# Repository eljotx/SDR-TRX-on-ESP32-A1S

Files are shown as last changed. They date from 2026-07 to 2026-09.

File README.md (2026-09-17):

# SDR-TRX-on-ESP32-A1S -> JACK
This repository describes an SDR transceiver based on the ESP32 A1S processor, using an ILI9341 color touchscreen display, and a Si5351 oscillator. The program was written on the Arduino platform and is still in development, but the most important features have already been implemented and tested.
The most important part of the software is Arduino Audio Tools, authored by Phil Schatzmann: https://github.com/pschatzmann/arduino-audio-tools

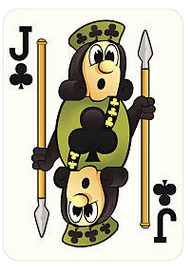
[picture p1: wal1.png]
JACK


# General Idea

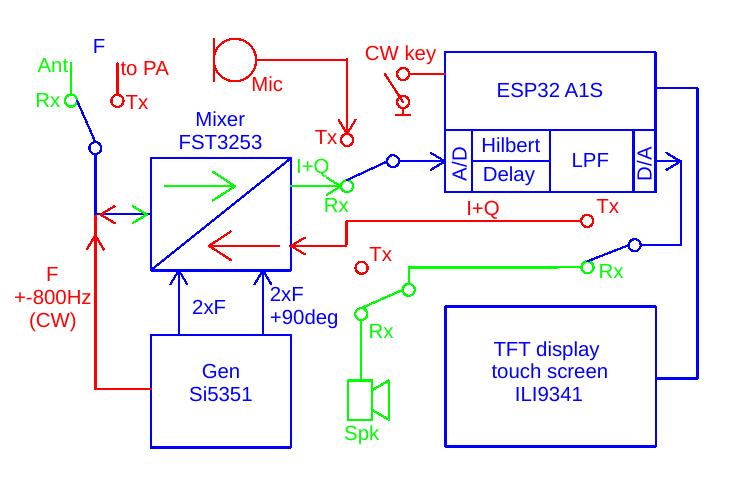
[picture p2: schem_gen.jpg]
Basic idea


The transceiver was built using a phase-based SSB signal generation method. Due to the breadth of the topic and the abundance of descriptions available online, this method will not be described here. However, I encourage you to study this topic theoretically, which will help you understand the presented solution.

Crucial to the solution is the use of **Tayloe mixer on FST3253, A/D conversion, Hilbert transforms, digital filters, and D/A conversion** in the audio paths of the receiver and transmitter.

## Local oscilator 

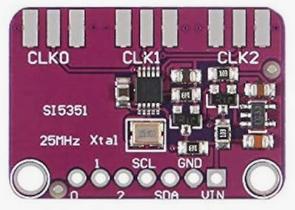
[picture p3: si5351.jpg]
Generator Si5351


The Si5351 acts as a local oscillator, clocking the transmitter and receiver mixers at a frequency that ensures proper detection or modulation. In this case, the clock signals have a frequency twice that of the useful signal, with an additional 90-degree shift between them, achieved using an additional shaping circuit based on integrated circuits 7474 and 7486. It is possible to generate the mixer signals directly within the Si5351, but for operation above 3.5 MHz, the controller needs to be modified, but the biggest inconvenience is the need to reset the PLL synchronization loop. This synchronization generates delays that are perceived as strong clicks during receive mode.

## Tayloe Mixer

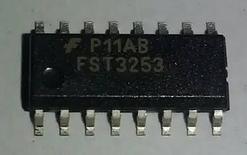
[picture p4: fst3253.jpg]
Mixer FST3253


The FST3253 is a dual, quadruple, high-speed digital keyer that acts as a keyed mixer for both the transmitter and receiver. During reception, the mixer extracts the I and Q components from the received signal for further digital processing. During transmission, it modulates the RF signal with I and Q components, creating a lower or upper sideband signal.

## Processor ESP32 A1S

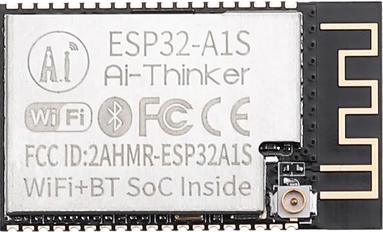
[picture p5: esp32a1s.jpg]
Procesor ESP32A1S


The core of the system is the ESP32 A1S processor, which is suitable for implementing the project because it contains built-in internal A/D and D/A converters and operates at a speed that allows for sufficiently fast sampling and the use of digital filters of desired complexity. Although the A/D and D/A converters have a resolution of 16 bits, this seems sufficient for a design that doesn't aspire to perfection, but rather addresses basic digital processing issues. Additionally, the processor has two cores, allowing for the separation of tasks that don't require immediate processing from those related to audio streaming. An additional advantage of the processor is the ability to use two I2c channels for communication with peripherals and a channel SPI for communication with the display. All of these features are discussed in more detail in the following descriptions.

# How receiver works
The antenna signal reaches a Tayloe mixer, where I and Q signals are generated. Both signals contain sideband information, which is used for digital data processing. To achieve this, the analog I and Q signals are digitized using 16-bit A/D converters. A Hilbert transform is then applied to one of the channels (shifting the signal's phase by 90 degrees). The signals are then digitally filtered using a BiQuad digital filter. Three filters are available: two low-pass filters at 3.6 kHz and 2.4 kHz, and a bandpass filter at 800 Hz for CW reception. Finally, the I and Q signals are converted back to analog using 16-bit D/A converters and summed, reducing the sideband of the received signal. The received sideband is selected in the Tayloe mixer by changing the phase of the heterodyne signals, reducing the load on the digital software.

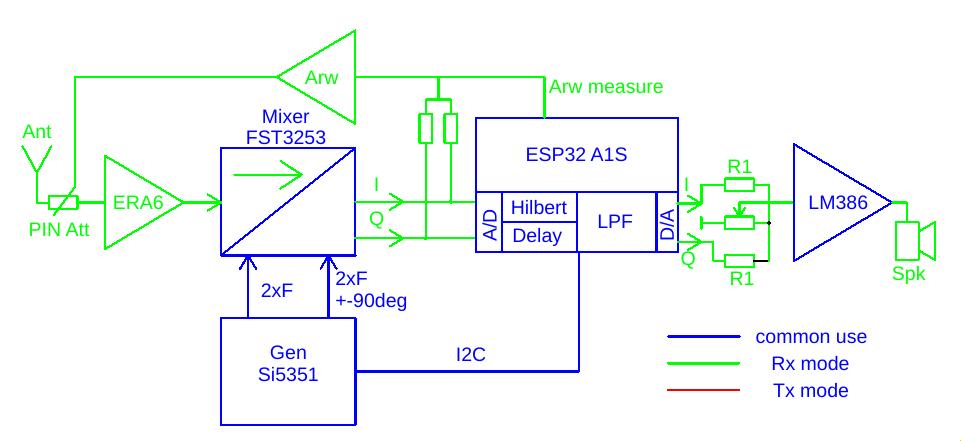
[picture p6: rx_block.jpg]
Receiver


The figure shows the signal waveform during reception in more detail. The antenna signal passes through an adjustable PIN diode attenuator and an ERA6 amplifier, and is then detected in the Taylor mixer. The I and Q signals extracted from the mixer, after summing, detection, and amplification, are used to adjust the gain using the PIN attenuator, and also, through AGC signal measurement, visualize the received signal strength. Simultaneously, the extracted I and Q signals undergo digital processing, as described earlier, and after conversion to analog and amplification, they can be received via headphones or a loudspeaker.

# How transceiver works

## SSB mode
In SSB mode, the transmitter initially digitizes the microphone signal using A/D converters. Subsequently, a Hilbert transform is performed on one of the signals, followed by a common LPF digital filtering with a 2.4 kHz bandwidth. This creates two digital I and Q signals, which are then converted to analog using D/A converters. The SSB signal is formed in a Tayloe mixer using two heterodyne signals that are 90 degrees out of phase. Similar to receiving, the sideband is selected by determining which heterodyne signal has a +90 degree offset relative to the other. This signal is then amplified and fed to the antenna. 

## CW mode
In CW mode, the Tayloe mixer is disabled (heterodyne stop), and an additional keyed heterodyne is activated at the device's operating frequency, with a sideband offset of approximately +800 Hz, depending on the sideband used.

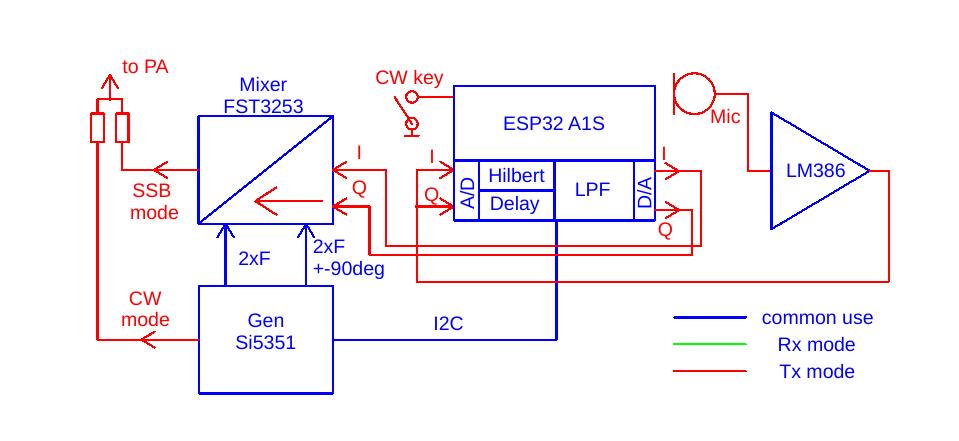
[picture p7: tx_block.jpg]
Transceiver


In addition to the previously described CW and SSB signal generation process, the figure shows how common circuit elements are used. Specifically, the microphone signal is pre-amplified in the same amplifier used for reception, and after shaping the I and Q channels, it feeds the Tayloe mixer. The final output signal is generated at the Tayloe mixer output in SSB mode or directly from the Si5351 generator in CW mode.

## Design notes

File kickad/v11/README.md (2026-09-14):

Kickad files was created with KicCad version 8.09-1

Software version 1_1 require using resistance divider (values) as showed on picture.

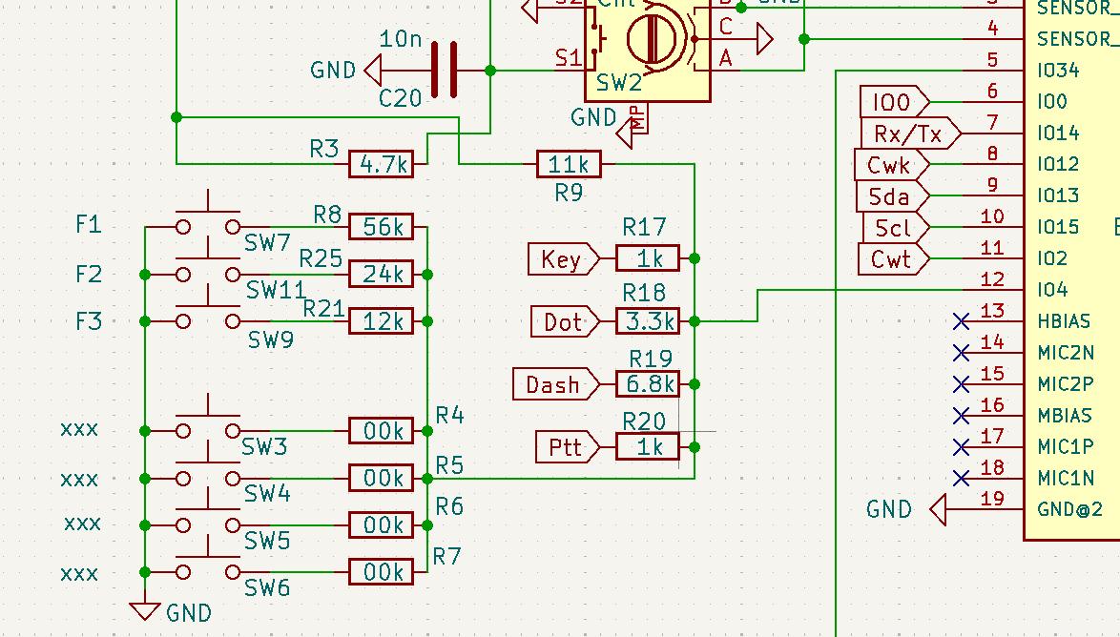
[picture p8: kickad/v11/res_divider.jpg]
divider


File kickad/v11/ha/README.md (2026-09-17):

The system can be operated in a basic configuration without the AGC system and redundant components. The drawing shows which components do not need to be installed in such a case.
The red markings refer to the PIN diode attenuator. The purple markings refer to the input amplifier, which results in reduced receiver sensitivity. In both cases, the jumpers marked in blue must be installed.

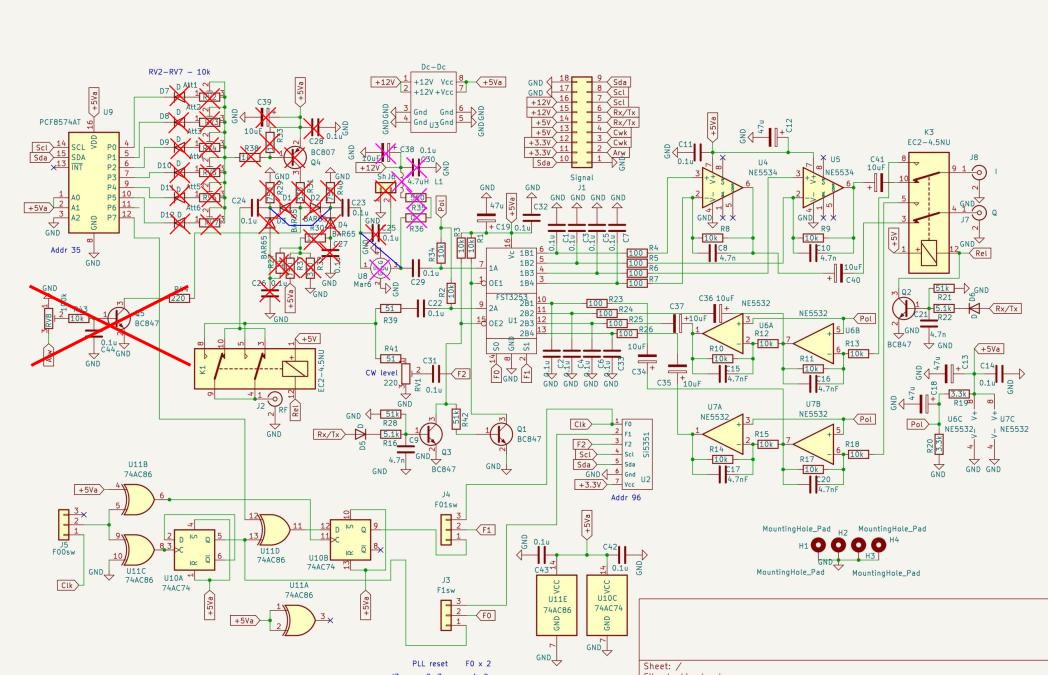
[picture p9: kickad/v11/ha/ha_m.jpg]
reduction


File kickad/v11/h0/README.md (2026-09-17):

Practical tip for mounting anti noise capacitor C31.
The LM386 amplifier may sometimes oscillate at frequencies ranging from several tens of kilohertz to nearly 200 kHz (this is visible on the output when an oscilloscope is connected and is indicated by an operating current exceeding 100 mA). To prevent this, capacitor C31 should be soldered close to the LM386 chip; a good solution is to solder C31 directly onto resistor R10.

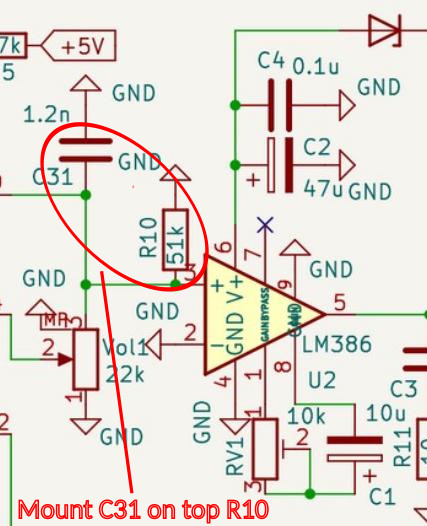
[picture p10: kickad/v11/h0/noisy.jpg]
divider


The system can be operated in a basic configuration without the AGC system and redundant components. The drawing shows which components do not need to be installed in such a case.

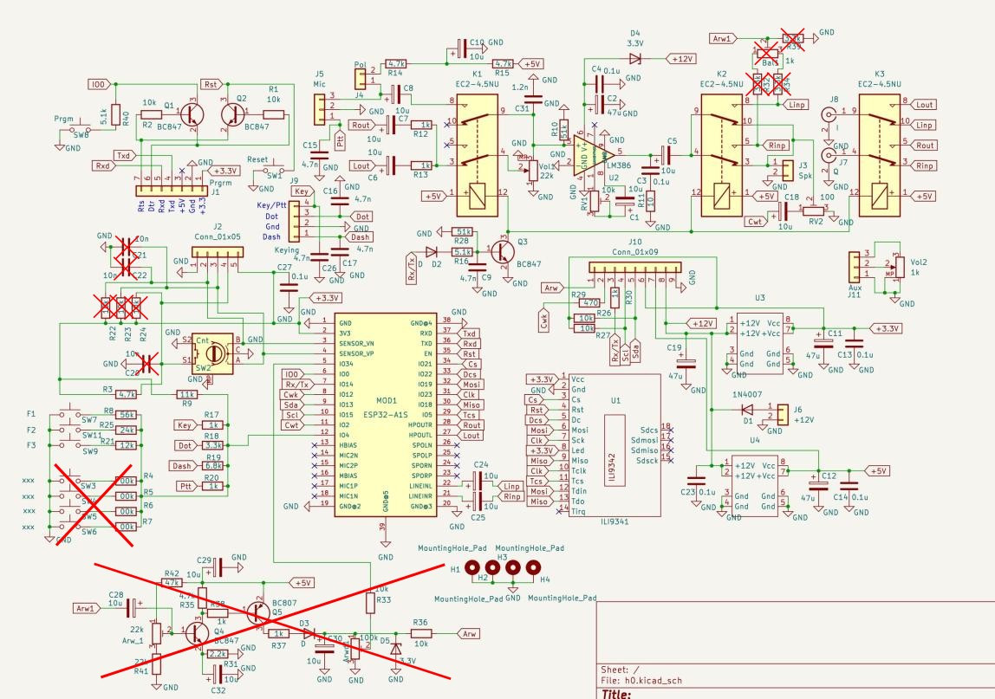
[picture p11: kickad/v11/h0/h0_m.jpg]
reduction


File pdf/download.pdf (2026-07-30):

Jak zaprogramować procesor Waleta z pomocą przeglądarki Chrome

Do wgrywania plików binarnych do procesorów ESP firma Expressive przygotowała dla systemu Windows narzędzia dostępne pod adresami: https://docs.espressif.com/projects/esp-test-tools/en/latest/esp32/production_stage/tools/flash_download_tool.html (https://docs.espressif.com/projects/esp-test-tools/en/latest/esp32/production_stage/tools/flash_download_tool.html) lub https://docs.espressif.com/projects/esp-at/en/latest/esp32/Get_Started/
Stamtąd też można ściągnąć pakiet oprogramowania jako plik .zip https://dl.espressif.com/public/flash_download_tool.zip , w którym znajduje się plik
wykonywalny .exe działający jako okno IDE pozwalający na wgranie plików binarnych do procesora.
Niezależnie od tego, niemal identyczną role pełni dostępna w sieci aplikacja zbliżona w wyglądzie do narzędzia instalowanego na platformie Windows z tym, że działa ona wyłącznie w przeglądarce Chrome.
1. Przeglądarka Chrome ma komponenty pozwalające na bezpośrednie programowanie układu ESP32 A1S bez konieczności instalacji Arduino, bibliotek i innych zależności.
Odpowiednie narzędzie znajduje się na stronie : https://espressif.github.io/esptool-js/
2. Aby wykorzystać to narzędzie należy przede wszystkim zapewnić kontakt elektryczny procesora na płytce z komputerem PC za pomocą opisanego wcześniej (np. w wykazie elementów płytki h0) konwertera USB/RS232 z pełną sygnalizacją (RTS oraz DTR).

Fotografia pokazuje gdzie na płytce znajdują się obwody odpowiedzialne za komunikacją oraz konwerter z pełną sygnalizacją RS. Do programowania procesora nie jest potrzebne zewnętrzne zasilanie bo wystarcza to z portu USB PC.

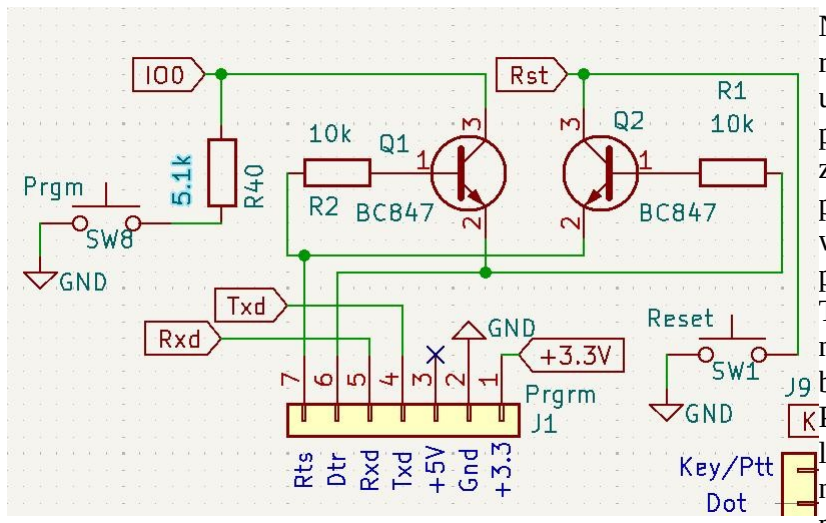
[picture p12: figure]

Niestety, okazało się, że obecne rozwiązanie elektryczne nie uwzględniało tej formy ładowania programu i musiałem
zmodyfikować tą część układu przez dołożenie przycisku
wprowadzania procesora w tryb programowania (SW8 oraz R40). Te elementy pojawią się w
następnej wersji płytek o ile będzie taka potrzeba.
Platforma Arduino radzi sobie lepiej z ładowaniem programu i nie wymaga ręcznego przełączenia procesora w tryb programowania dlatego to rozwiązanie pojawia się tak późno i obecne płytki nie zawierają dodatkowych

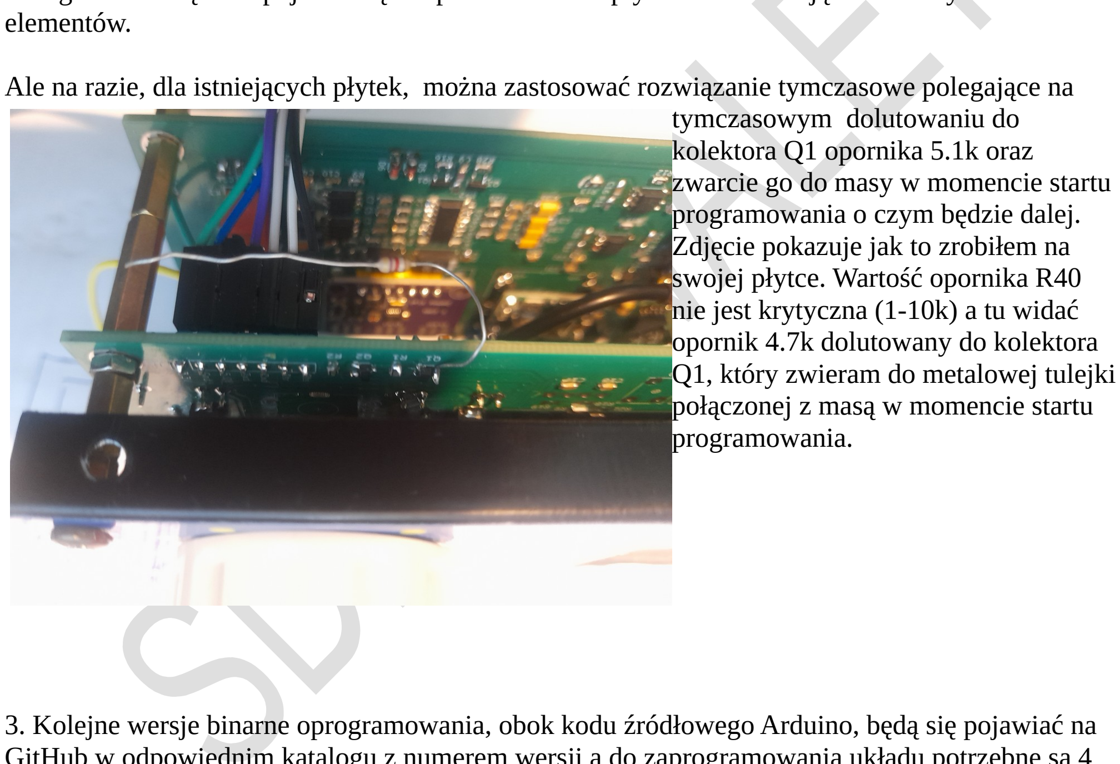
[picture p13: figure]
elementów.; tymczasowym dolutowaniu do kolektora Q1 opornika 5.1k oraz zwarcie go do masy w momencie startu programowania o czym będzie dalej. Zdjęcie pokazuje jak to zrobiłem na swojej płytce. Wartość opornika R40 nie jest krytyczna (1-10k) a tu widać opornik 4.7k dolutowany do kolektora Q1, który zwieram do metalowej tulejki połączonej z masą w momencie startu programowania.

Ale na razie, dla istniejących płytek, można zastosować rozwiązanie tymczasowe polegające na

3. Kolejne wersje binarne oprogramowania, obok kodu źródłowego Arduino, będą się pojawiać na GitHub w odpowiednim katalogu z numerem wersji a do zaprogramowania układu potrzebne są 4 pliki binarne i na przykład obecnie mają one nazwę:
boot_app0.bin
ssd_trx01.ino.bin
ssd_trx01.ini.bootloader.bin
ssd_trx01.ino.partitions.bin
Dodatkowo, podświetliłem plik flash_args, który jest bardzo pomocny podczas definiowania treści wgranej do procesora. Kolejne wersje oprogramowania zawierać będą zestaw pokazanych pięciu plików ale być może będą się różnić rdzeniem nazwy, który tu ma postać ssd_trx01

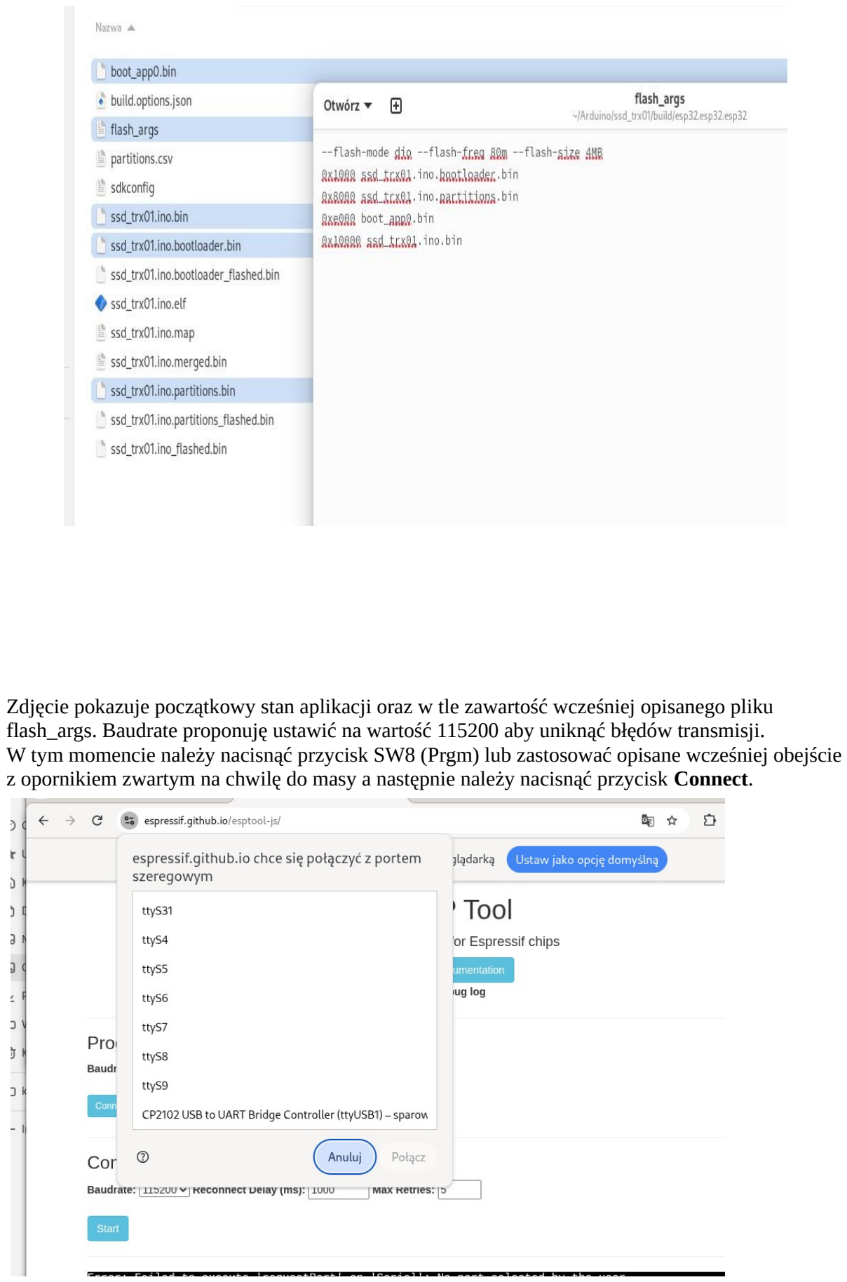
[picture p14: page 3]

Zdjęcie pokazuje początkowy stan aplikacji oraz w tle zawartość wcześniej opisanego pliku flash_args. Baudrate proponuję ustawić na wartość 115200 aby uniknąć błędów transmisji.
W tym momencie należy nacisnąć przycisk SW8 (Prgm) lub zastosować opisane wcześniej obejście z opornikiem zwartym na chwilę do masy a następnie należy nacisnąć przycisk Connect.

Pojawi się okno z możliwością wyboru portu, w moim przypadku to ostatni na dole port ttyUSB1 identyfikowany dodatkowo przez symbol chip-u CP2102. Po wyborze (kliknięciu) na właściwy port aktywny stanie się klawisz Połącz (Connect) i powinien pojawić się komunikat w oknie konsoli na dole aplikacji o skutecznym połączeniu.

Od tego momentu można zwolnić przycisk programowania i przejść do wyboru plików oraz uruchomienia procedury download.

5. Właściwe programowanie wymaga podania dla każdego z czterech plików wymienionych w p.3 zarówno nazwy jak i adresu gdzie powinien ten plik się zaczynać. Robi się to zamieszczając w polu adresowym (z lewej) odpowiednią wartość skojarzoną ze ścieżką do pliku i tu jest pomocny widoczny w tle plik flash_args zawierając właśnie potrzebne dane. Kolejne pliki dodaje się klawiszem Add File.

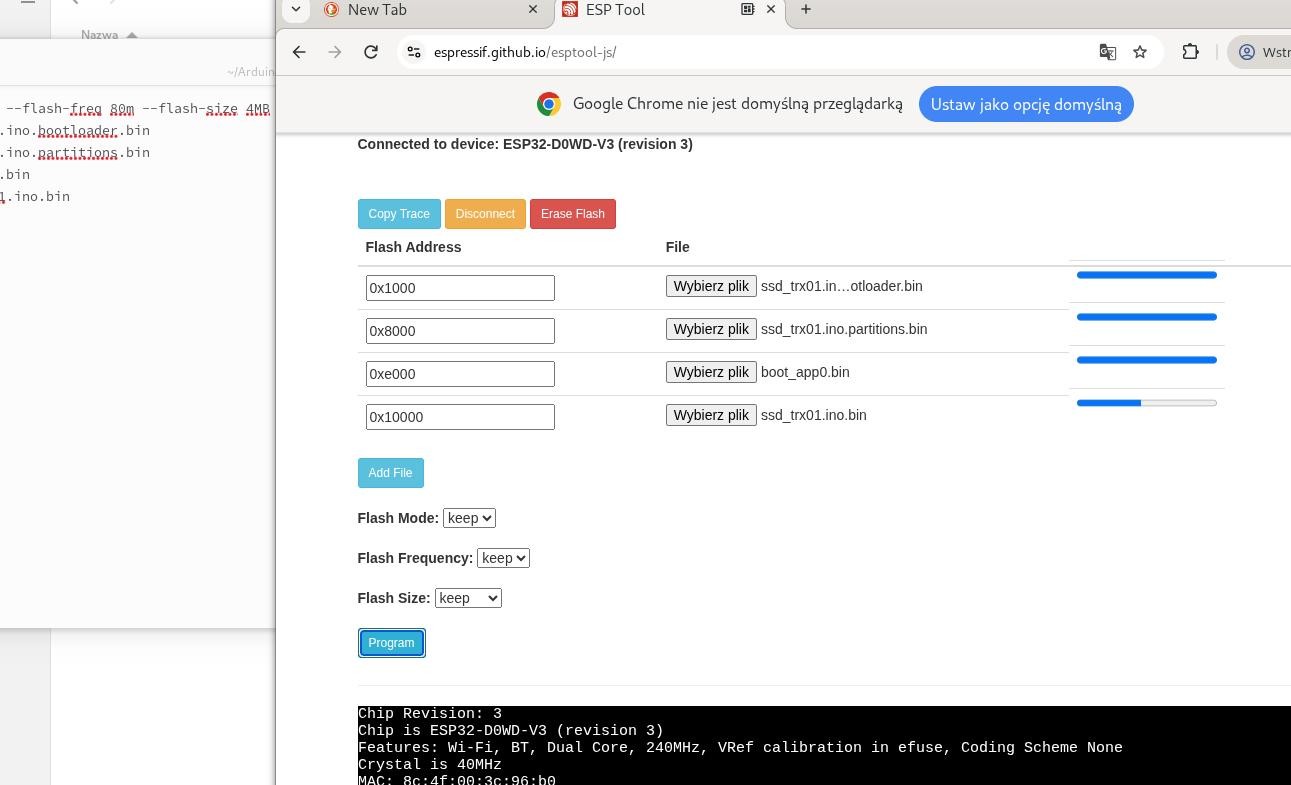
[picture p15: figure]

Zdjęcie pokazuje stan aplikacji po wybraniu czterech niezbędnych plików z odpowiednimi adresami po uruchomieniu programowania za pomocą klawisza Program. Przesłanie plików zajmuje nie więcej niż kilkanaście sekund a po zakończeniu należy układ zresetować klawiszem RST lub poprzez zasilanie i procesor powinien już działać pod kontrolą nowego oprogramowania.

Przy sprawnym połączeniu płytki procesora z komputerem PC wgranie oprogramowania zajmuje kilka minut.

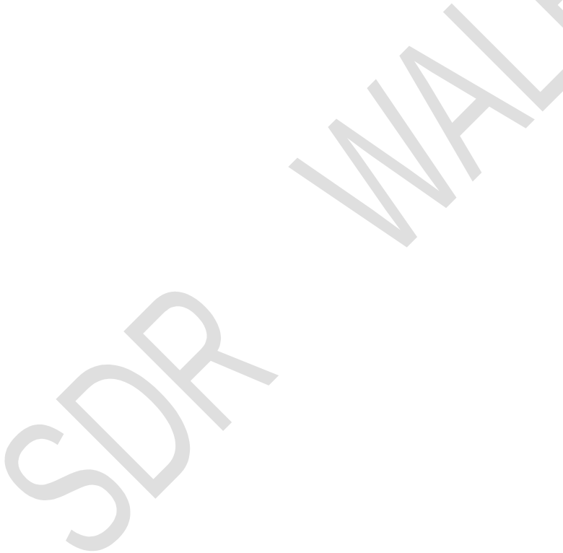
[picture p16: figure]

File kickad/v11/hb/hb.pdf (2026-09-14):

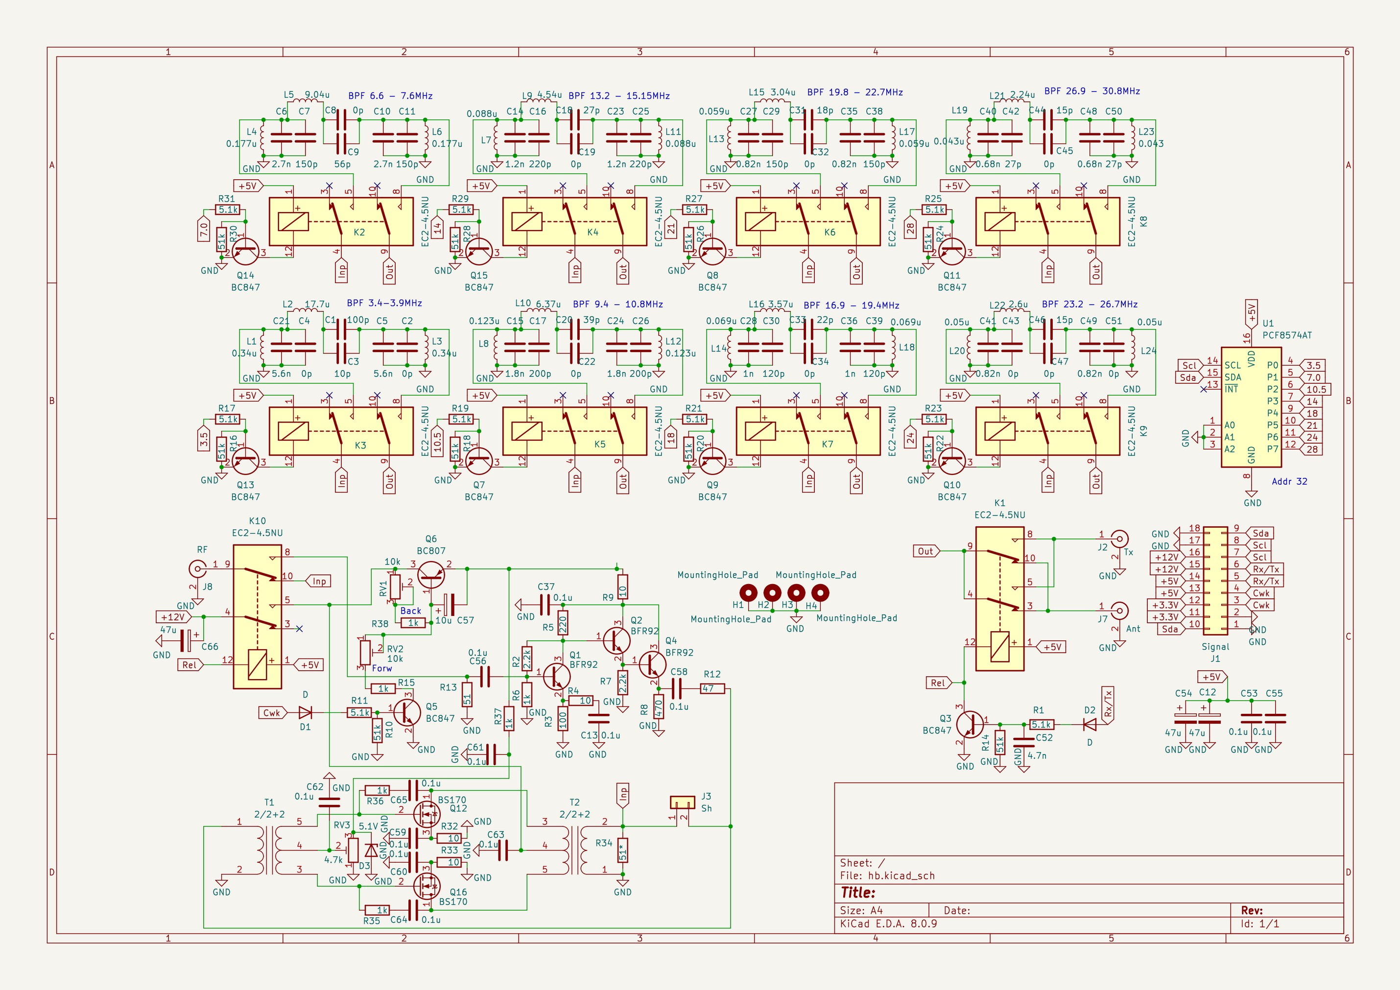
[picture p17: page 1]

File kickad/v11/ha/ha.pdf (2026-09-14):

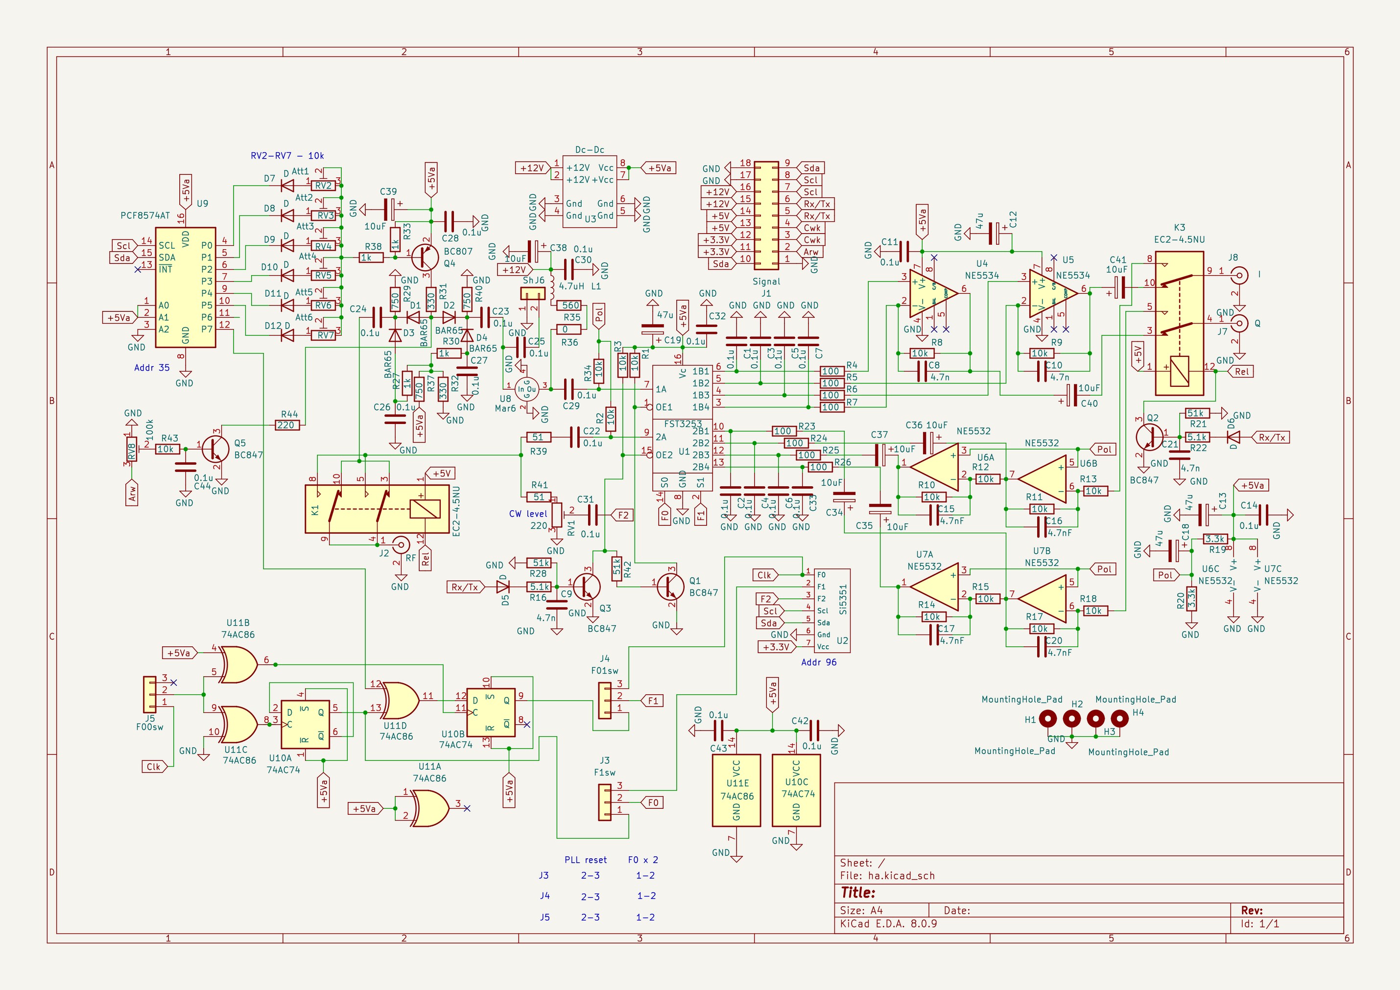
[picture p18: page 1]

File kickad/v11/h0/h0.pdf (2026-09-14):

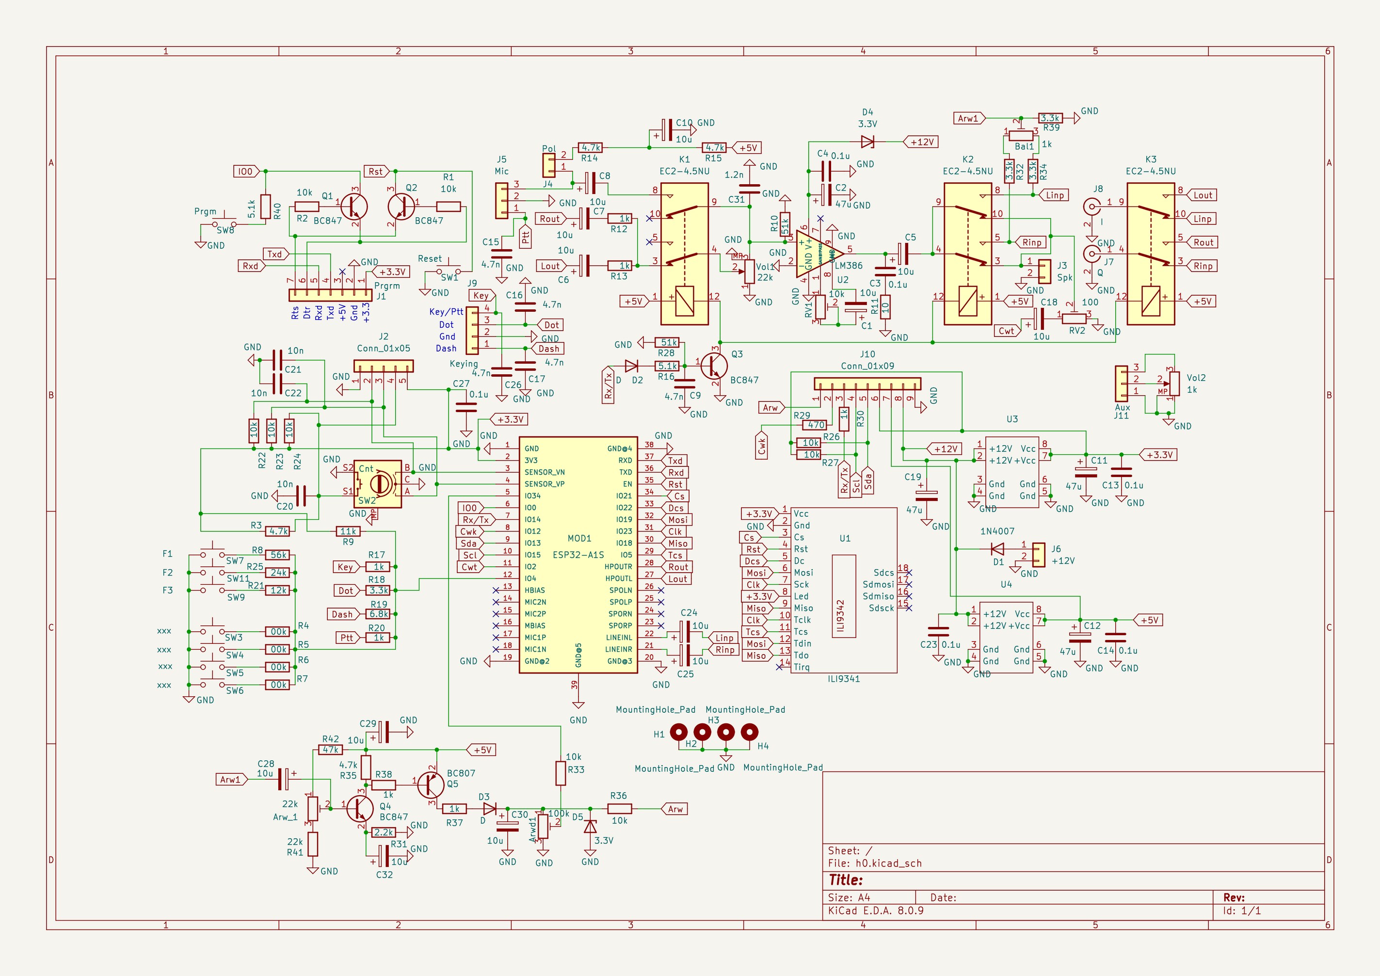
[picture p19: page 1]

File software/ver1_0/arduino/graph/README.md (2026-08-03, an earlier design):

All files here must be in graph subdirectory of main arduino file directory

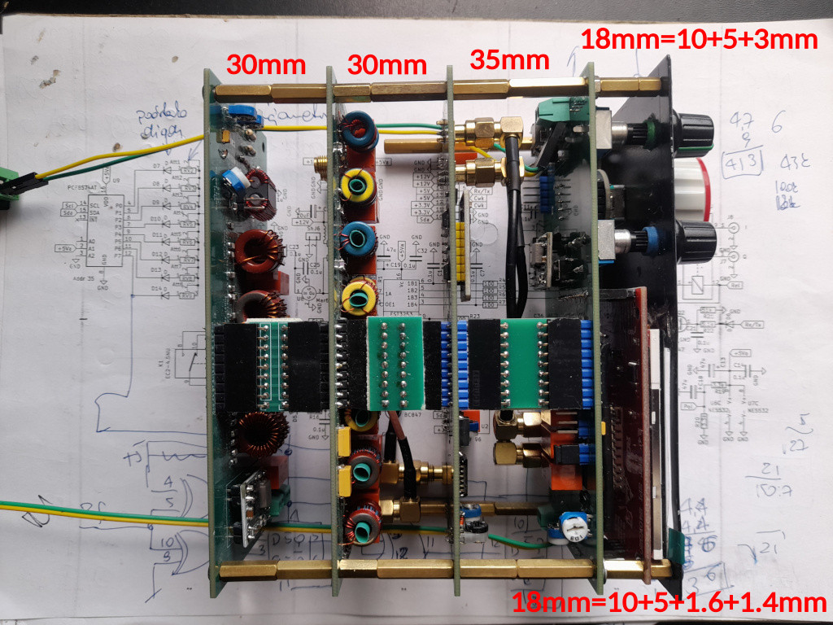
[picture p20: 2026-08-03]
images/mont01.jpg

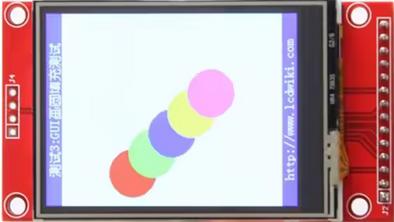
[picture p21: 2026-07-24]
ili9341a.jpg

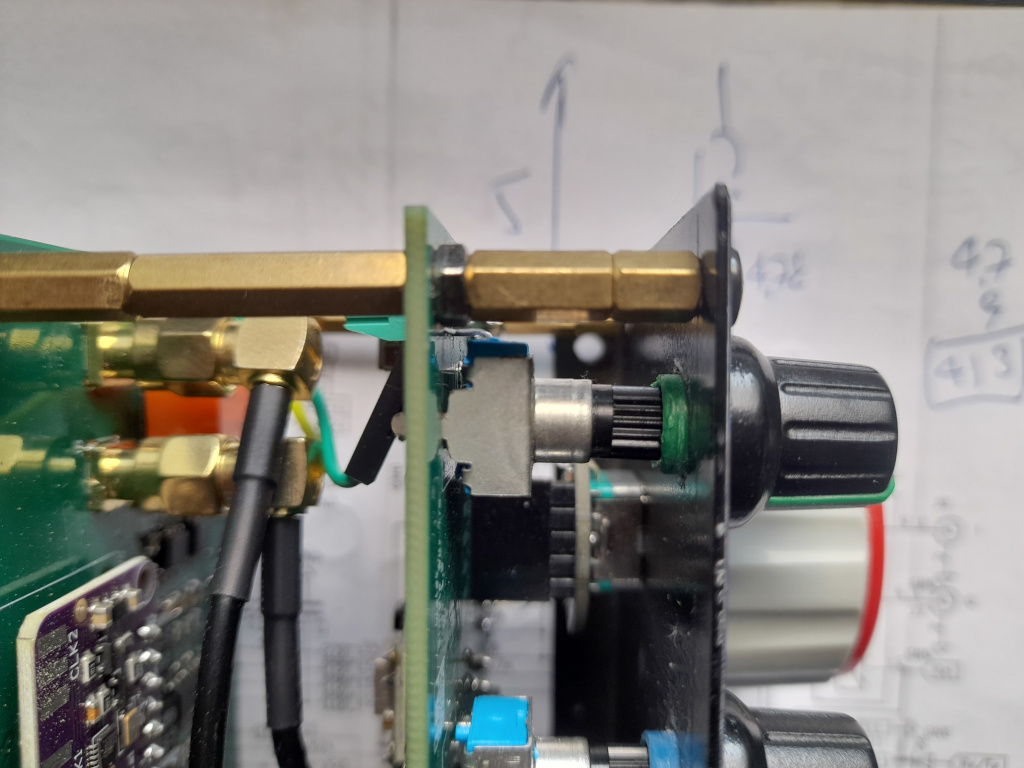
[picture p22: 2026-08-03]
images/mont03.jpg

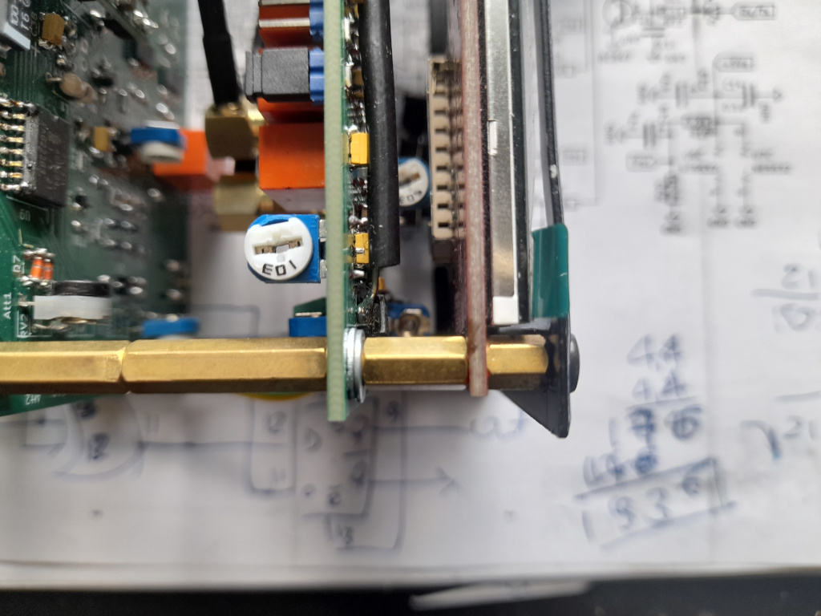
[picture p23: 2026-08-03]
images/mont02.jpg

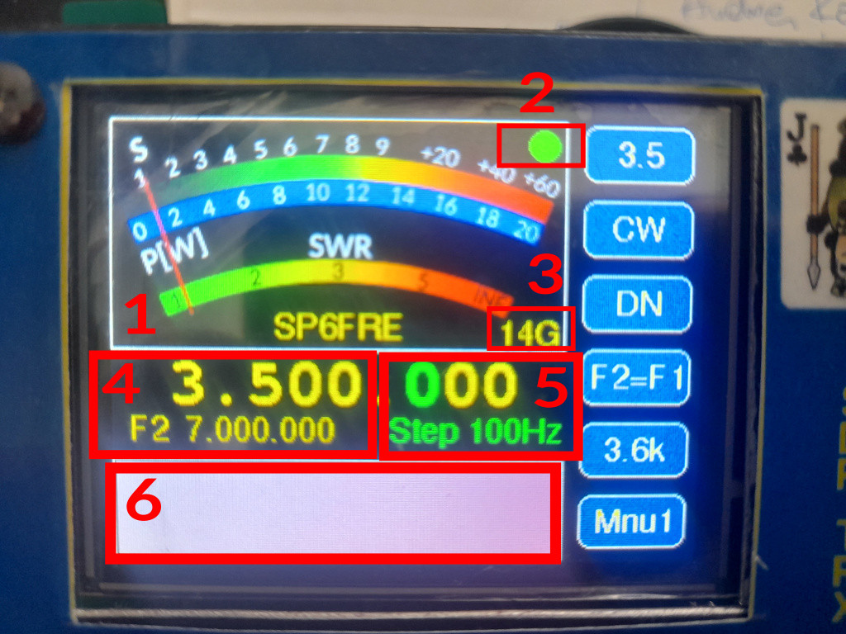
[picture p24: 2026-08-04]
images/screen.jpg

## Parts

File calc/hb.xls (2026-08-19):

Reference | Value | Uwagi | Footprint | Qty | DNP | Cena | Wartość | Gdzie kupić
C1 | 10p |  | Capacitor_SMD:C_0805_2012Metric | 1 |  | 0.15 | 0.15 | TME, allegro
C2,C4,C9,C18,C20,C31,C33,C43,C44,C46,C51 | 0p |  | Capacitor_SMD:C_0805_2012Metric | 11 |  | 0.15 | 1.65 | TME, allegro
C3,C49 | 100p |  | Capacitor_SMD:C_0805_2012Metric | 2 |  | 0.15 | 0.30 | TME, allegro
C5,C21 | 5.6n |  | Capacitor_SMD:C_0805_2012Metric | 2 |  | 0.15 | 0.30 | TME, allegro
C6,C10 | 2.7n |  | Capacitor_SMD:C_0805_2012Metric | 2 |  | 0.15 | 0.30 | TME, allegro
C7,C11,C29,C38 | 150p |  | Capacitor_SMD:C_0805_2012Metric | 4 |  | 0.15 | 0.60 | TME, allegro
C8 | 56p |  | Capacitor_SMD:C_0805_2012Metric | 1 |  | 0.15 | 0.15 | TME, allegro
C12,C54,C66 | 47u | 47-100u | Capacitor_Tantalum_SMD:CP_EIA-7343-31_Kemet-D | 3 |  | 2.928 | 8.78 | TME
C13,C37,C53,C55,C56,C58,C59,C60,C61,C62,C63,C64,C65 | 0.1u |  | Capacitor_SMD:C_0805_2012Metric | 13 |  | 0.15 | 1.95 | TME, allegro
C14,C23 | 1.2n |  | Capacitor_SMD:C_0805_2012Metric | 2 |  | 0.15 | 0.30 | TME, allegro
C15,C24 | 1.8n |  | Capacitor_SMD:C_0805_2012Metric | 2 |  | 0.15 | 0.30 | TME, allegro
C16,C25 | 220p |  | Capacitor_SMD:C_0805_2012Metric | 2 |  | 0.15 | 0.30 | TME, allegro
C17,C26 | 200p |  | Capacitor_SMD:C_0805_2012Metric | 2 |  | 0.15 | 0.30 | TME, allegro
C19,C42,C50 | 27p |  | Capacitor_SMD:C_0805_2012Metric | 3 |  | 0.15 | 0.45 | TME, allegro
C22 | 39p |  | Capacitor_SMD:C_0805_2012Metric | 1 |  | 0.15 | 0.15 | TME, allegro
C27,C35,C41 | 0.82n |  | Capacitor_SMD:C_0805_2012Metric | 3 |  | 0.15 | 0.45 | TME, allegro
C28,C36 | 1n |  | Capacitor_SMD:C_0805_2012Metric | 2 |  | 0.15 | 0.30 | TME, allegro
C30,C39 | 120p |  | Capacitor_SMD:C_0805_2012Metric | 2 |  | 0.15 | 0.30 | TME, allegro
C32 | 18p |  | Capacitor_SMD:C_0805_2012Metric | 1 |  | 0.15 | 0.15 | TME, allegro
C34 | 22p |  | Capacitor_SMD:C_0805_2012Metric | 1 |  | 0.15 | 0.15 | TME, allegro
C40,C48 | 0.68n |  | Capacitor_SMD:C_0805_2012Metric | 2 |  | 0.15 | 0.30 | TME, allegro
C45,C47 | 15p |  | Capacitor_SMD:C_0805_2012Metric | 2 |  | 0.15 | 0.30 | TME, allegro
C52 | 4.7n |  | Capacitor_SMD:C_0805_2012Metric | 1 |  | 0.15 | 0.15 | TME, allegro
C57 | 10u |  | Capacitor_SMD:C_0805_2012Metric | 1 |  | 0.15 | 0.15 | TME, allegro
D1,D2 | D | Schottky | Capacitor_SMD:C_1206_3216Metric | 2 |  | 0.3 | 0.60 | TME, allegro
D3 | 5.1V |  | Capacitor_SMD:C_1206_3216Metric | 1 |  | 0.3 | 0.30 | TME, allegro
J1 | Signal |  | Connector_PinHeader_2.54mm:PinHeader_2x09_P2.54mm_Vertical | 1 |  | 3.105 | 3.11 | TME, allegro
J2 | Tx |  | Connector_Coaxial:SMA_Amphenol_901-144_Vertical | 1 |  | 2.5 | 2.50 | aliexpress
J3 | Sh |  | Connector_PinHeader_2.54mm:PinHeader_1x02_P2.54mm_Vertical | 1 |  | 0.345 | 0.35 | TME, allegro
J7 | Ant |  | Connector_Coaxial:SMA_Amphenol_901-144_Vertical | 1 |  | 2.5 | 2.50 | aliexpress
J8 | RF |  | Connector_Coaxial:SMA_Amphenol_901-144_Vertical | 1 |  | 2.5 | 2.50 | aliexpress
K1,K2,K3,K4,K5,K6,K7,K8,K9,K10 | EC2-4.5NU |  | Relay_THT:Relay_DPDT_Kemet_EC2_NJ | 10 |  | 2.952 | 29.52 | https://shop.tvsat.com.pl/pl/p/10szt-EC2-4.5N-Relay-4.5VDC-2A-Coil-178-Ohm-THT-NEC/8891
L1,L3 | 0.34u | T37-12 lub 17 | tr_rf:l_01 | 2 |  | 3.2 | 6.40 | allegro, hps://sklep.sp2fp.profimot.pl/rdzenie-c-1.html,
L2 | 17.7u | T37-1 | tr_rf:l_01 | 1 |  | 2.5 | 2.50 | allegro, https://sklep.sp2fp.profimot.pl/rdzenie-c-1.html
L4,L6 | 0.177u | T37-12 lub 17 | tr_rf:l_01 | 2 |  | 3.2 | 6.40 | allegro, https://sklep.sp2fp.profimot.pl/rdzenie-c-1.html
L5 | 9.04u | T37-1 | tr_rf:l_01 | 1 |  | 2.5 | 2.50 | allegro, https://sklep.sp2fp.profimot.pl/rdzenie-c-1.html
L7,L11 | 0.088u | T37-0 | tr_rf:l_01 | 2 |  | 4.5 | 9.00 | allegro, https://sklep.sp2fp.profimot.pl/rdzenie-c-1.html
L8,L12 | 0.123u | T37-12 lub 17 | tr_rf:l_01 | 2 |  | 3.2 | 6.40 | allegro, https://sklep.sp2fp.profimot.pl/rdzenie-c-1.html
L9 | 4.54u | T37-2 | tr_rf:l_01 | 1 |  | 2.5 | 2.50 | allegro, https://sklep.sp2fp.profimot.pl/rdzenie-c-1.html
L10 | 6.37u | T37-2 | tr_rf:l_01 | 1 |  | 2.5 | 2.50 | allegro, https://sklep.sp2fp.profimot.pl/rdzenie-c-1.html
L13,L17 | 0.059u | T37-0 | tr_rf:l_01 | 2 |  | 4.5 | 9.00 | allegro, https://sklep.sp2fp.profimot.pl/rdzenie-c-1.html
L14,L18 | 0.069u | T37-0 | tr_rf:l_01 | 2 |  | 4.5 | 9.00 | allegro, https://sklep.sp2fp.profimot.pl/rdzenie-c-1.html
L15 | 3.04u | T37-2 | tr_rf:l_01 | 1 |  | 2.5 | 2.50 | allegro, https://sklep.sp2fp.profimot.pl/rdzenie-c-1.html
L16 | 3.57u | T37-2 | tr_rf:l_01 | 1 |  | 2.5 | 2.50 | allegro, https://sklep.sp2fp.profimot.pl/rdzenie-c-1.html
L19 | 0.043u | T37-0 | tr_rf:l_01 | 1 |  | 4.5 | 4.50 | allegro, https://sklep.sp2fp.profimot.pl/rdzenie-c-1.html
L20,L24 | 0.05u | T37-0 | tr_rf:l_01 | 2 |  | 4.5 | 9.00 | allegro, https://sklep.sp2fp.profimot.pl/rdzenie-c-1.html
L21 | 2.24u | T37-2 | tr_rf:l_01 | 1 |  | 2.5 | 2.50 | allegro, https://sklep.sp2fp.profimot.pl/rdzenie-c-1.html
L22 | 2.6u | T32-2 | tr_rf:l_01 | 1 |  | 2.5 | 2.50 | allegro, https://sklep.sp2fp.profimot.pl/rdzenie-c-1.html
L23 | 0.043 | T37-0 | tr_rf:l_01 | 1 |  | 4.5 | 4.50 | allegro, https://sklep.sp2fp.profimot.pl/rdzenie-c-1.html
Q1,Q2,Q4 | BFR92 |  | Package_TO_SOT_SMD:SOT-23 | 3 |  | 1.31241 | 3.94 | TME, allegro
Q3,Q5,Q7,Q8,Q9,Q10,Q11,Q13,Q14,Q15 | BC847 |  | Package_TO_SOT_SMD:SOT-23 | 10 |  | 0.8784 | 8.78 | TME, allegro
Q6 | BC807 |  | Package_TO_SOT_SMD:SOT-23 | 1 |  | 0.8784 | 0.88 | TME, allegro
Q12,Q16 | BS170 |  | Package_TO_SOT_THT:TO-92_Inline | 2 |  | 1.968 | 3.94 | TME, allegro
R1,R11,R17,R19,R21,R23,R25,R27,R29,R31 | 5.1k |  | Resistor_SMD:R_0805_2012Metric | 10 |  | 0.03 | 0.30 | TME, allegro
R2,R7 | 2.2k |  | Resistor_SMD:R_0805_2012Metric | 2 |  | 0.03 | 0.06 | TME, allegro
R3 | 100 |  | Resistor_SMD:R_0805_2012Metric | 1 |  | 0.03 | 0.03 | TME, allegro
R4,R9,R32,R33 | 10 |  | Resistor_SMD:R_0805_2012Metric | 4 |  | 0.03 | 0.12 | TME, allegro
R5 | 220 |  | Resistor_SMD:R_0805_2012Metric | 1 |  | 0.03 | 0.03 | TME, allegro
R6,R15,R35,R36,R37,R38 | 1k |  | Resistor_SMD:R_0805_2012Metric | 6 |  | 0.03 | 0.18 | TME, allegro
R8 | 470 |  | Resistor_SMD:R_0805_2012Metric | 1 |  | 0.03 | 0.03 | TME, allegro
R10,R14,R16,R18,R20,R22,R24,R26,R28,R30 | 51k |  | Resistor_SMD:R_0805_2012Metric | 10 |  | 0.03 | 0.30 | TME, allegro
R12 | 47 |  | Resistor_SMD:R_0805_2012Metric | 1 |  | 0.03 | 0.03 | TME, allegro
R13 | 51 |  | Resistor_SMD:R_0805_2012Metric | 1 |  | 0.03 | 0.03 | TME, allegro
R34 | 51* |  | Resistor_SMD:R_0805_2012Metric | 1 |  | 0.03 | 0.03 | TME, allegro
RV1,RV2 | 10k |  | Potentiometer_THT:Potentiometer_ACP_CA6-H2,5_Horizontal | 2 |  | 0.5 | 1.00 | TME, allegro
RV3 | 4.7k |  | Potentiometer_THT:Potentiometer_ACP_CA6-H2,5_Horizontal | 1 |  | 0.5 | 0.50 | TME, allegro
T1,T2 | 2/2+2 | dwuotworowy niski | tr_rf:tr_05_v | 2 |  | 2.5 | 5.00 | allegro, https://sklep.sp2fp.profimot.pl/rdzenie-c-1.html
U1 | PCF8574AT |  | Package_SO:SOIC-16W_7.5x10.3mm_P1.27mm | 1 |  | 7.3 | 7.30 | TME
 | Przewód SMA kątowy | >10szt |  | 3 |  | 7.4 | 22.20 | aliexpress
 | Płytka dr. |  |  | 1 |  | 13.627 | 13.63 | JLCPCB
 |  |  |  |  |  | suma | 212.11

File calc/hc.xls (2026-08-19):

Reference | Value | Uwagi | Footprint | Qty | DNP | Cena | Wartość | Gdzie kupić
C1,C27,C28,C29,C31 | 0.1u |  | Capacitor_SMD:C_0805_2012Metric | 5 |  | 0.15 | 0.75 | TME, allegro
C2 | 470p |  | Capacitor_SMD:C_1206_3216Metric | 1 |  | 0.15 | 0.15 | TME, allegro
C3,C4 | 750p |  | Capacitor_SMD:C_1206_3216Metric | 2 |  | 0.15 | 0.30 | TME, allegro
C5,C9,C12 | 47p |  | Capacitor_SMD:C_1206_3216Metric | 3 |  | 0.15 | 0.45 | TME, allegro
C6,C10 | 390p |  | Capacitor_SMD:C_1206_3216Metric | 2 |  | 0.15 | 0.30 | TME, allegro
C7,C11,C15,C17,C19,C21,C23,C25 | 0p |  | Capacitor_SMD:C_1206_3216Metric | 8 |  | 0.15 | 1.20 | TME, allegro
C8 | 680p |  | Capacitor_SMD:C_1206_3216Metric | 1 |  | 0.15 | 0.15 | TME, allegro
C13 | 1n |  | Capacitor_SMD:C_1206_3216Metric | 1 |  | 0.15 | 0.15 | TME, allegro
C14,C18 | 200p |  | Capacitor_SMD:C_1206_3216Metric | 2 |  | 0.15 | 0.30 | TME, allegro
C16 | 360p |  | Capacitor_SMD:C_1206_3216Metric | 1 |  | 0.15 | 0.15 | TME, allegro
C20,C24 | 100p |  | Capacitor_SMD:C_1206_3216Metric | 2 |  | 0.15 | 0.30 | TME, allegro
C22 | 180p |  | Capacitor_SMD:C_1206_3216Metric | 1 |  | 0.15 | 0.15 | TME, allegro
C26,C32 | 47u | 47-100u | Capacitor_Tantalum_SMD:CP_EIA-3528-21_Kemet-B | 2 |  | 2.928 | 5.86 | TME, allegro
C30 | 4.7n |  | Capacitor_SMD:C_0805_2012Metric | 1 |  | 0.15 | 0.15 | TME, allegro
D1,D2,D3 | D | Schottky | Diode_SMD:D_1206_3216Metric | 3 |  | 0.3 | 0.90 | TME, allegro
D4 | 1N4007 |  | Diode_SMD:D_1206_3216Metric | 1 |  | 0.3 | 0.30 | TME, allegro
J1 | +12V | 3mm | Connector:power_con | 1 |  | 0.5 | 0.50 | TME, allegro
J2 | Sign |  | Connector_PinHeader_2.54mm:PinHeader_2x09_P2.54mm_Vertical | 1 |  | 1.5525 | 1.55 | TME, allegro
J5 | Ant |  | Connector_Coaxial:SMA_Amphenol_901-144_Vertical | 1 |  | 2.5 | 2.50 | aliexpress
J7 | Sh |  | Connector_PinHeader_2.54mm:PinHeader_1x02_P2.54mm_Vertical | 1 |  | 0.345 | 0.35 | TME, allegro
J10 | RF |  | Connector_Coaxial:SMA_Amphenol_901-144_Vertical | 1 |  | 2.5 | 2.50 | aliexpress
J11 | Pa |  | Connector_Coaxial:SMA_Amphenol_901-144_Vertical | 1 |  | 2.5 | 2.50 | aliexpress
J12 | +12Tx | 3mm | Connector:power_con | 1 |  | 0.5 | 0.50 | TME, allegro
K1,K2,K3,K4,K6,K7 | EC2-4.5NU |  | Relay_THT:Relay_DPDT_Kemet_EC2_NU | 6 |  | 2.952 | 17.71 | https://shop.tvsat.com.pl/pl/p/10szt-EC2-4.5N-Relay-4.5VDC-2A-Coil-178-Ohm-THT-NEC/8891
L1,L2 | 2.73u | T50-2 | tr_rf:l_01 | 2 |  | 4.3 | 8.60 | allegro, https://sklep.sp2fp.profimot.pl/rdzenie-c-1.html
L3,L4 | 1.37u | T50-2 | tr_rf:l_01 | 2 |  | 4.3 | 8.60 | allegro, https://sklep.sp2fp.profimot.pl/rdzenie-c-1.html
L5,L6 | 0.683u | T50-12,17 lub 6 | tr_rf:l_01 | 2 |  | 4.3 | 8.60 | allegro, https://sklep.sp2fp.profimot.pl/rdzenie-c-1.html
L7,L8 | 0.341u | T50-12,17 lub 6 | tr_rf:l_01 | 2 |  | 4.3 | 8.60 | allegro, https://sklep.sp2fp.profimot.pl/rdzenie-c-1.html
Q1,Q2,Q3,Q4,Q5 | BC847 |  | Package_TO_SOT_SMD:SOT-23 | 5 |  | 0.8784 | 4.39 | TME, allegro
R2,R5,R7,R9,R17 | 5.1k |  | Resistor_SMD:R_0805_2012Metric | 5 |  | 0.03 | 0.15
R3 | 1.2k |  | Resistor_SMD:R_0805_2012Metric | 1 |  | 0.03 | 0.03
R4,R6,R8,R10,R16 | 51k |  | Resistor_SMD:R_0805_2012Metric | 5 |  | 0.03 | 0.15
R18,R19 | 51 |  | Resistor_THT:R_Axial_DIN0309_L9.0mm_D3.2mm_P12.70mm_Horizontal | 2 |  | 0.2 | 0.40
RV1,RV2,RV3 | 10k |  | Potentiometer_THT:Potentiometer_ACP_CA6-H2,5_Horizontal | 3 |  | 0.5 | 1.50
TR2 | DC | dwuotworowy | dircoupler:dircoupler | 1 |  | 5 | 5.00
U2 | MCP3424 |  | Package_SO:SOIC-14_3.9x8.7mm_P1.27mm | 1 |  | 14.36 | 14.36 | TME, allegro
U3 | Dc-Dc |  | Dc-dc:dc-dc | 1 |  | 4.99 | 4.99 | allegro
U4 | PCF8574AT |  | Package_SO:SOIC-16W_7.5x10.3mm_P1.27mm | 1 |  | 7.3 | 7.30 | TME, allegro
 | Przewód SMA kątowy | >10szt |  | 2 |  | 7.4 | 14.80 | aliexpress
 | Płytka dr. |  |  | 1 |  | 13.627 | 13.63 | JLCPCB
 |  |  |  |  |  | suma | 140.7645

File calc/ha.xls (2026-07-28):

Reference | Value | Uwagi | Footprint | Qty | DNP | Cena | Wartość | Gdzie kupić
C1,C2,C3,C4,C5,C6,C7,C11,C14,C22,C23,C24,C25,C26,C27,C28,C29,C30,C31,C32,C33,C42,C43,C44 | 0.1u |  | Capacitor_SMD:C_0805_2012Metric | 24 |  | 0.15 | 3.60 | TME, allegro
C8,C9,C10,C21 | 4.7n |  | Capacitor_SMD:C_0805_2012Metric | 4 |  | 0.15 | 0.60 | TME, allegro
C12,C13,C18,C19 | 47u | 47-100u | Capacitor_Tantalum_SMD:CP_EIA-7343-31_Kemet-D | 4 |  | 2.928 | 11.71 | TME
C15,C16,C17,C20 | 4.7nF |  | Capacitor_SMD:C_0805_2012Metric | 4 |  | 0.15 | 0.60 | TME, allegro
C34,C35,C36,C37,C38,C39,C40,C41 | 10uF |  | Capacitor_SMD:C_1206_3216Metric | 8 |  | 0.15 | 1.20 | TME, allegro
D1,D2,D3,D4 | BAR65 |  | Capacitor_SMD:C_0805_2012Metric | 4 |  | 0.15 | 0.60 | https://shop.tvsat.com.pl/pl/p/200szt-BAR65-03W-E6722-Diode-PIN-3GHz-SMD-SOD123-SIEMENS/19748
D5,D6,D7,D8,D9,D10,D11,D12 | D |  | Capacitor_SMD:C_1206_3216Metric | 8 |  | 0.15 | 1.20 | TME, allegro
J1 | Signal |  | Connector_PinHeader_2.54mm:PinHeader_2x09_P2.54mm_Vertical | 1 |  | 3.105 | 3.11 | TME, allegro
J2 | RF |  | Connector_Coaxial:SMA_Amphenol_901-144_Vertical | 1 |  | 2.5 | 2.50 | aliexpress
J6 | Sh |  | Connector_PinHeader_2.54mm:PinHeader_1x02_P2.54mm_Vertical | 1 |  | 0.345 | 0.35 | TME, allegro
J7 | Q |  | Connector_Coaxial:SMA_Amphenol_901-144_Vertical | 1 |  | 2.5 | 2.50 | aliexpress
J8 | I |  | Connector_Coaxial:SMA_Amphenol_901-144_Vertical | 1 |  | 2.5 | 2.50 | aliexpress
K1,K3 | EC2-4.5NU |  | Relay_THT:Relay_DPDT_Kemet_EC2_NJ | 2 |  | 2.952 | 5.90 | https://shop.tvsat.com.pl/pl/p/10szt-EC2-4.5N-Relay-4.5VDC-2A-Coil-178-Ohm-THT-NEC/8891
L1 | 4.7uH |  | Inductor_THT:L_Axial_L5.3mm_D2.2mm_P7.62mm_Horizontal_Vishay_IM-1 | 1 |  | 0.3 | 0.30
Q1,Q2,Q3,Q5 | BC847 |  | Package_TO_SOT_SMD:SOT-23 | 4 |  | 0.8784 | 3.51 | TME, allegro
Q4 | BC807 |  | Package_TO_SOT_SMD:SOT-23 | 1 |  | 0.8784 | 0.88 | TME, allegro
R1,R2,R3,R8,R9,R10,R11,R12,R13,R14,R15,R17,R18,R34,R43 | 10k |  | Resistor_SMD:R_0805_2012Metric | 15 |  | 0.03 | 0.45 | TME, allegro
R4,R5,R6,R7,R23,R24,R25,R26 | 100 |  | Resistor_SMD:R_0805_2012Metric | 8 |  | 0.03 | 0.24 | TME, allegro
R16,R22 | 5.1k |  | Resistor_SMD:R_0805_2012Metric | 2 |  | 0.03 | 0.06 | TME, allegro
R19,R20 | 3.3k |  | Resistor_SMD:R_0805_2012Metric | 2 |  | 0.03 | 0.06 | TME, allegro
R21,R28,R42 | 51k |  | Resistor_SMD:R_0805_2012Metric | 3 |  | 0.03 | 0.09 | TME, allegro
R27,R30,R33,R38 | 1k |  | Resistor_SMD:R_0805_2012Metric | 4 |  | 0.03 | 0.12 | TME, allegro
R29,R37,R40 | 750 |  | Resistor_SMD:R_0805_2012Metric | 3 |  | 0.03 | 0.09 | TME, allegro
R31,R32 | 330 |  | Resistor_SMD:R_0805_2012Metric | 2 |  | 0.03 | 0.06 | TME, allegro
R35 | 560 |  | Resistor_SMD:R_0805_2012Metric | 1 |  | 0.03 | 0.03 | TME, allegro
R36 | 0 |  | Resistor_SMD:R_0805_2012Metric | 1 |  | 0.03 | 0.03 | TME, allegro
R39,R41 | 51 |  | Resistor_SMD:R_0805_2012Metric | 2 |  | 0.03 | 0.06 | TME, allegro
R44,RV1 | 220 |  | Resistor_SMD:R_0805_2012Metric | 2 |  | 0.03 | 0.06 | TME, allegro
RV2 | Att1 |  | Potentiometer_THT:Potentiometer_ACP_CA6-H2,5_Horizontal | 1 |  | 0.5 | 0.50 | TME, allegro
RV3 | Att2 |  | Potentiometer_THT:Potentiometer_ACP_CA6-H2,5_Horizontal | 1 |  | 0.5 | 0.50 | TME, allegro
RV4 | Att3 |  | Potentiometer_THT:Potentiometer_ACP_CA6-H2,5_Horizontal | 1 |  | 0.5 | 0.50 | TME, allegro
RV5 | Att4 |  | Potentiometer_THT:Potentiometer_ACP_CA6-H2,5_Horizontal | 1 |  | 0.5 | 0.50 | TME, allegro
RV6 | Att5 |  | Potentiometer_THT:Potentiometer_ACP_CA6-H2,5_Horizontal | 1 |  | 0.5 | 0.50 | TME, allegro
RV7 | Att6 |  | Potentiometer_THT:Potentiometer_ACP_CA6-H2,5_Horizontal | 1 |  | 0.5 | 0.50 | TME, allegro
RV8 | 100k |  | Potentiometer_THT:Potentiometer_ACP_CA6-H2,5_Horizontal | 1 |  | 0.5 | 0.50 | TME, allegro
U1 | FST3253 |  | Package_SO:SOIC-16W_5.3x10.2mm_P1.27mm | 1 |  | 15 | 15.00 | allegro
U2 | Si5351 |  | Si5351:Si5351 | 1 |  | 21.5 | 21.50 | allegro
U3 | Dc-Dc |  | Dc-dc:dc-dc | 1 |  | 4.99 | 4.99 | allegro
U4,U5 | NE5534 |  | Package_SO:SO-8_3.9x4.9mm_P1.27mm | 2 |  | 5.2 | 10.40 | TME, allegro
U6,U7 | NE5532 |  | Package_SO:SO-8_3.9x4.9mm_P1.27mm | 2 |  | 5.2 | 10.40 | TME, allegro
U8 | Mar6 |  | era_mar:Era | 1 |  | 11.468 | 11.47 | https://www.digikey.pl/pl/products/detail/mini-circuits/MAR-6SM/13928288
U9 | PCF8574AT |  | Package_SO:SOIC-16W_7.5x10.3mm_P1.27mm | 1 |  | 7.3 | 7.30 | TME
U10 | 74AC74 |  | Package_SO:SO-14_5.3x10.2mm_P1.27mm | 1 |  | 4.3 | 4.30 | TME
U11 | 74AC86 |  | Package_SO:SO-14_5.3x10.2mm_P1.27mm | 1 |  | 3.2 | 3.20 | TME
 | Płytka dr. |  |  | 1 |  | 13.627 | 13.63 | JLCPCB
 | Przewód SMA kątowy | >10szt |  | 2 |  | 7.4 | 14.80 | aliexpress
 |  |  |  |  |  | Suma | 162.893

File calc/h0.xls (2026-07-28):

Reference | Value | Uwagi | Footprint | Qty | DNP | Cena | Wartość | Gdzie kupić
Arwd1,Arw_1 | 100k |  | Potentiometer_THT:Potentiometer_ACP_CA6-H2,5_Horizontal | 2 |  | 0.5 | 1.00 | TME, allegro
Bal1,R1,R2,R9,R10,R22,R23,R24,R26,R27,R33,R36,RV1 | 10k |  | Resistor_SMD:R_0805_2012Metric | 13 |  | 0.03 | 0.39 | TME,allegro
C1,C5,C6,C7,C8,C10,C18,C24,C25,C28,C29,C30 | 10u | Tantal | SMD:C_1206_3216Metric | 12 |  | 1.098 | 1.10 | TME
C2,C11,C12,C19 | 47u lub 100u | Tantal | Capacitor_Tantalum_SMD:CP_EIA-7343-31_Kemet-D | 4 |  | 2.928 | 11.71 | TME
C3,C4,C13,C14,C23,C27 | 0.1u |  | Capacitor_SMD:C_0805_2012Metric | 6 |  | 0.15 | 0.90 | TME, allegro
C9,C15,C16,C17,C26 | 4.7n |  | Capacitor_SMD:C_0805_2012Metric | 5 |  | 0.15 | 0.75 | TME, allegro
C20,C21,C22 | 10n |  | Capacitor_SMD:C_0805_2012Metric | 3 |  | 0.15 | 0.45 | TME, allegro
D1 | 1N4007 |  | Diode_SMD:D_2114_3652Metric | 1 |  | 0.3 | 0.30 | TME, allegro
D2,D3 | D | np.. BAT48 SMD | SMD:C_1206_3216Metric | 2 |  | 0.29 | 0.58 | https://botland.com.pl/diody-schottky/14581-dioda-schottky-bat48-smd-1a-40v-10szt-5903351244503.html
D4,D5 | 3.3V |  | SMD:C_1206_3216Metric | 2 |  | 0.5 | 1.00 | TME, allegro
J1 | Prgrm |  | Connector_PinHeader_2.54mm:PinHeader_1x07_P2.54mm_Vertical | 1 |  | 1.2075 | 1.21 | TME, allegro
J2 | Conn_01x05 |  | Connector_PinHeader_2.54mm:PinHeader_1x05_P2.54mm_Vertical | 1 |  | 0.8625 | 0.86 | TME, allegro
J3 | Spk | Raster pinów 3.5mm | Connector:power_con | 1 |  | 1.5 | 1.50 | TME, allegro
J4 | Pol |  | Connector_PinHeader_2.54mm:PinHeader_1x02_P2.54mm_Vertical | 1 |  | 0.345 | 0.35 | TME, allegro
J5 | Mic |  | Connector_PinHeader_2.54mm:PinHeader_1x03_P2.54mm_Vertical | 1 |  | 0.5175 | 0.52 | TME, allegro
J6 | +12V | Raster pinów 3.5mm | Connector:power_con | 1 |  | 1.5 | 1.50 | TME, allegro
J7 | Q | >=10 szt | Connector_Coaxial:SMA_Amphenol_901-144_Vertical | 1 |  | 2.5 | 2.50 | aliexpress
J8 | I | >=10 szt | Connector_Coaxial:SMA_Amphenol_901-144_Vertical | 1 |  | 2.5 | 2.50 | aliexpress
J9 | Keying |  | Connector_PinHeader_2.54mm:PinHeader_1x04_P2.54mm_Vertical | 1 |  | 0.69 | 0.69 | TME, allegro
J10 | Conn_01x09 |  | Connector_PinHeader_2.54mm:PinHeader_1x09_P2.54mm_Vertical | 1 |  | 1.5525 | 1.55 | TME, allegro
J11 | Aux |  | Connector_PinHeader_2.54mm:PinHeader_1x03_P2.54mm_Vertical | 1 |  | 0.5175 | 0.52 | TME, allegro
K1,K2,K3 | EC2-4.5NU |  | Relay_THT:Relay_DPDT_Kemet_EC2_NJ | 3 |  | 2.952 | 8.86 | https://shop.tvsat.com.pl/pl/p/10szt-EC2-4.5N-Relay-4.5VDC-2A-Coil-178-Ohm-THT-NEC/8891
MOD1 | ESP32-A1S |  | esp32a1s:ESP32-A1S | 1 |  | 30.9 | 30.90 | aliexpress
Q1,Q2,Q3,Q4 | BC847 |  | Package_TO_SOT_SMD:SOT-23 | 4 |  | 0.8784 | 3.51 | TME, allegro
Q5 | BC807 |  | Package_TO_SOT_SMD:SOT-23 | 1 |  | 0.8784 | 0.88 | TME,allegro
R3,R14,R15,R17,R20,R35 | 4.7k |  | Resistor_SMD:R_0805_2012Metric | 6 |  | 0.03 | 0.18 | TME, allegro
R4 | 15k |  | Resistor_SMD:R_0805_2012Metric | 1 |  | 0.03 | 0.03 | TME, allegro
R5 | 7.5k |  | Resistor_SMD:R_0805_2012Metric | 1 |  | 0.03 | 0.03 | TME, allegro
R6 | 3.6k |  | Resistor_SMD:R_0805_2012Metric | 1 |  | 0.03 | 0.03 | TME, allegro
R7 | 1.6k |  | Resistor_SMD:R_0805_2012Metric | 1 |  | 0.03 | 0.03 | TME, allegro
R8,R29,R31 | 470 |  | Resistor_SMD:R_0805_2012Metric | 3 |  | 0.03 | 0.09 | TME, allegro
R11 | 10 |  | Resistor_SMD:R_0805_2012Metric | 1 |  | 0.03 | 0.03 | TME, allegro
R12,R13,R30,R37,R38,Vol2 | 1k |  | Resistor_SMD:R_0805_2012Metric | 6 |  | 0.03 | 0.18 | TME, allegro
R16 | 5.1k |  | Resistor_SMD:R_0805_2012Metric | 1 |  | 0.03 | 0.03 | TME, allegro
R18 | 12k |  | Resistor_SMD:R_0805_2012Metric | 1 |  | 0.03 | 0.03 | TME, allegro
R19 | 24k |  | Resistor_SMD:R_0805_2012Metric | 1 |  | 0.03 | 0.03 | TME, allegro
R21 | 1.2k |  | Resistor_SMD:R_0805_2012Metric | 1 |  | 0.03 | 0.03 | TME, allegro
R25 | 56k |  | Resistor_SMD:R_0805_2012Metric | 1 |  | 0.03 | 0.03 | TME, allegro
R28 | 51k |  | Resistor_SMD:R_0805_2012Metric | 1 |  | 0.03 | 0.03 | TME, allegro
R32,R34,R39 | 3.3k |  | Resistor_SMD:R_0805_2012Metric | 3 |  | 0.03 | 0.09 | TME, allegro
RV2 | 100 | >=10 szt | Potentiometer_THT:Potentiometer_ACP_CA6-H2,5_Horizontal | 1 |  | 0.36 | 0.36 | TME, allegro
SW1 | Reset |  | Connector:microswitch | 1 |  | 0.5 | 0.50 | TME, allegro
SW2 | Cnt |  | Rotary_Encoder:RotaryEncoder_Alps_EC11E-Switch_Vertical_H20mm | 1 |  | 6.9 | 6.90 | allegro, aliexpress
SW3 | Step |  | Connector:microswitch | 1 |  | 0.5 | 0.50 | TME, allegro
SW4 | Up/Dn |  | Connector:microswitch | 1 |  | 0.5 | 0.50 | TME, allegro
SW5 | Rit |  | Connector:microswitch | 1 |  | 0.5 | 0.50 | TME, allegro
SW6 | Save |  | Connector:microswitch | 1 |  | 0.5 | 0.50 | TME, allegro
SW7 | Rest |  | Connector:microswitch | 1 |  | 0.5 | 0.50 | TME, allegro
SW9 | Mnu |  | Connector:microswitch | 1 |  | 0.5 | 0.50 | TME, allegro
SW11 | F1/F2 |  | Connector:microswitch | 1 |  | 0.5 | 0.50 | TME, allegro
U1 | ILI9341 | 2.4” | Ili9341:ili9342 | 1 |  | 41.1 | 41.10 | allegro
U2 | LM386 |  | Package_SO:Diodes_PSOP-8 | 1 |  | 4.6 | 4.60 | TME
U3,U4 | ~ |  | Dc-dc:dc-dc | 2 |  | 4.99 | 9.98 | allegro
Vol? | 22k |  | Potentiometer_THT:Potentiometer_Alpha_RD901F-40-00D_Single_Vertical | 1 |  | 4.5 | 4.50 | TME, allegro
 | Płytka dr. |  |  | 1 |  | 13.627 | 13.63
 | Przewód SMA kątowy | 10szt |  | 2 |  | 7.4 | 14.80
 | Programator |  | Konwerter USB CP2102 RS232 TTL UART 3.3/5V programator do odczytu TX/RX | 1 |  | 9.4 | 9.40 | allegro, Microbot
 | Inne |  |  | 1 |  | 10 | 10.00 | allegro, Microbot
 |  |  |  |  |  | Razem ok: | 196.16

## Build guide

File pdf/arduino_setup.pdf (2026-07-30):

Ustawienie i konfiguracja bibliotek niezbędnych do programowania Waleta

### 1. Instalacja platformy Arduino

Software dla różnych systemów operacyjnych można znaleźć pod tym linkiem: https://support.arduino.cc/hc/en-us/articles/360019833020-Download-and-install-Arduino-IDE

Kolejno należy wgrać do Arduino biblioteki procesorów ESP:
Installing ESP32 Add-on in Arduino IDE
1. In your Arduino IDE, go to File> Preferences.
2. Open the Boards Manager. Go to Tools > Board > Boards Manager…
3. Search for ESP32 and press install button for the “ESP32 by Espressif Systems“:
4. That's it. It should be installed after a few seconds.
Pomocny film: https://randomnerdtutorials.com/installing-the-esp32-board-in-arduino-idewindows-instructions/ (https://randomnerdtutorials.com/installing-the-esp32-board-in-arduino-ide-windows-instructions/)
Po dołączeniu konwertera USB/RS do procesora należy wybrać odpowiedni procesor oraz port, w moim przypadku jest to port linux-owy, na platformie Windows będzie to jakiś COMx.

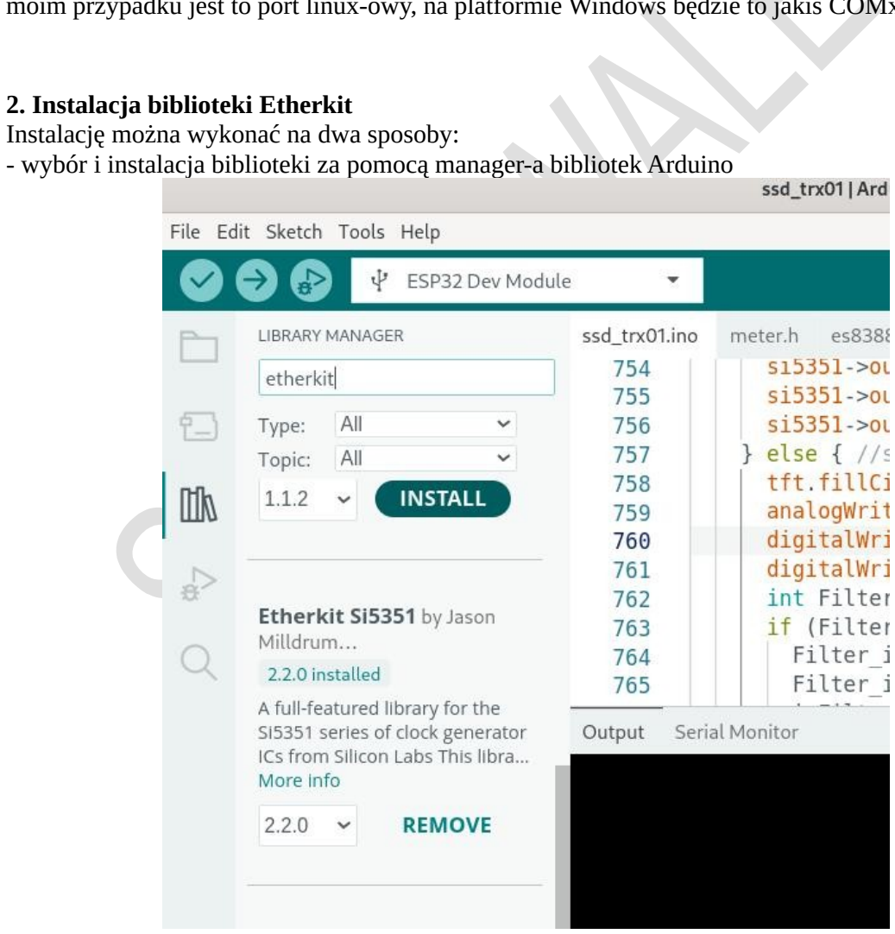
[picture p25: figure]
2. Instalacja biblioteki Etherkit

Instalację można wykonać na dwa sposoby:
- wybór i instalacja biblioteki za pomocą manager-a bibliotek Arduino

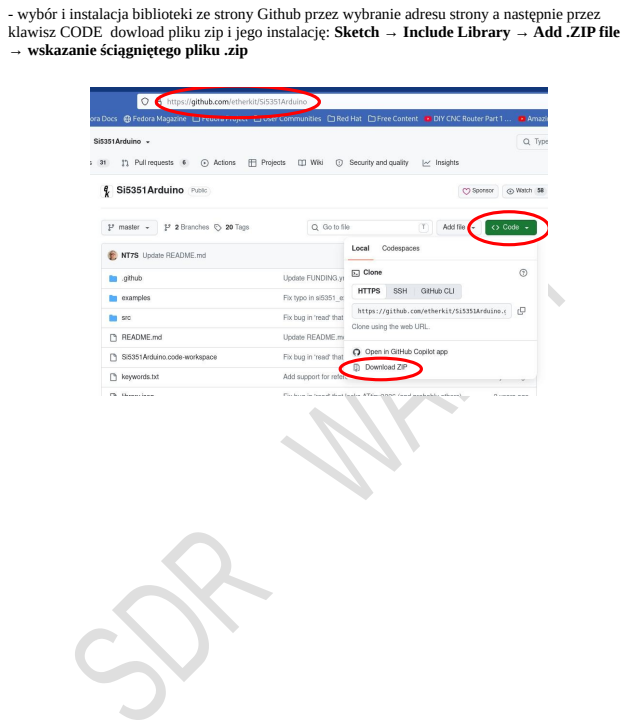
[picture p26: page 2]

- wybór i instalacja biblioteki ze strony Github przez wybranie adresu strony a następnie przez
klawisz CODE dowload pliku zip i jego instalację: Sketch → Include Library → Add .ZIP file
→ wskazanie ściągniętego pliku .zip

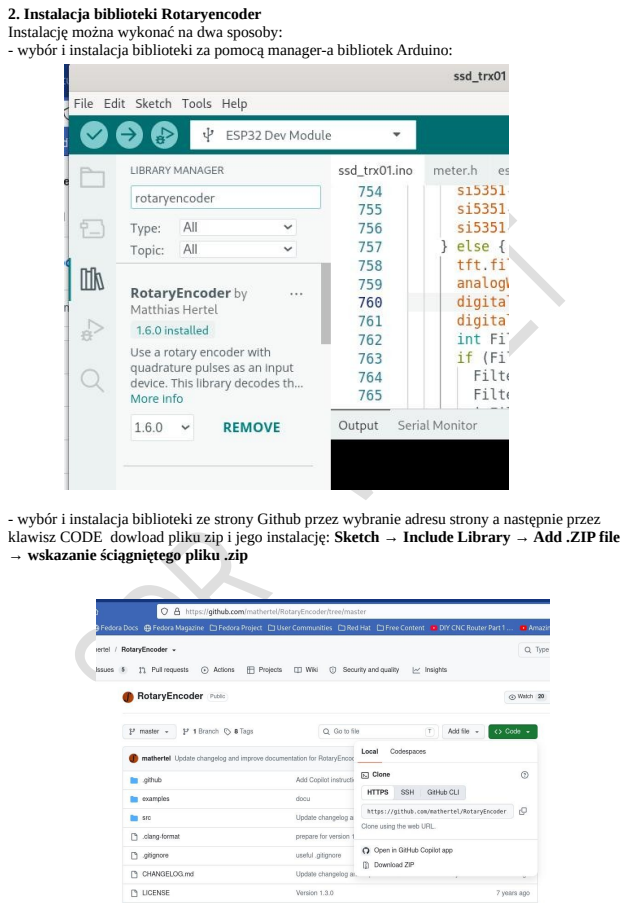
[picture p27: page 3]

2. Instalacja biblioteki Rotaryencoder
Instalację można wykonać na dwa sposoby:
- wybór i instalacja biblioteki za pomocą manager-a bibliotek Arduino:

- wybór i instalacja biblioteki ze strony Github przez wybranie adresu strony a następnie przez
klawisz CODE dowload pliku zip i jego instalację: Sketch → Include Library → Add .ZIP file
→ wskazanie ściągniętego pliku .zip

### 3. Instalacja bibliotek Arduino Audio Tools

- wybór i instalacja biblioteki ze strony Github przez wybranie adresu strony a następnie przez klawisz CODE dowload pliku zip i jego instalację: Sketch → Include Library → Add .ZIP file

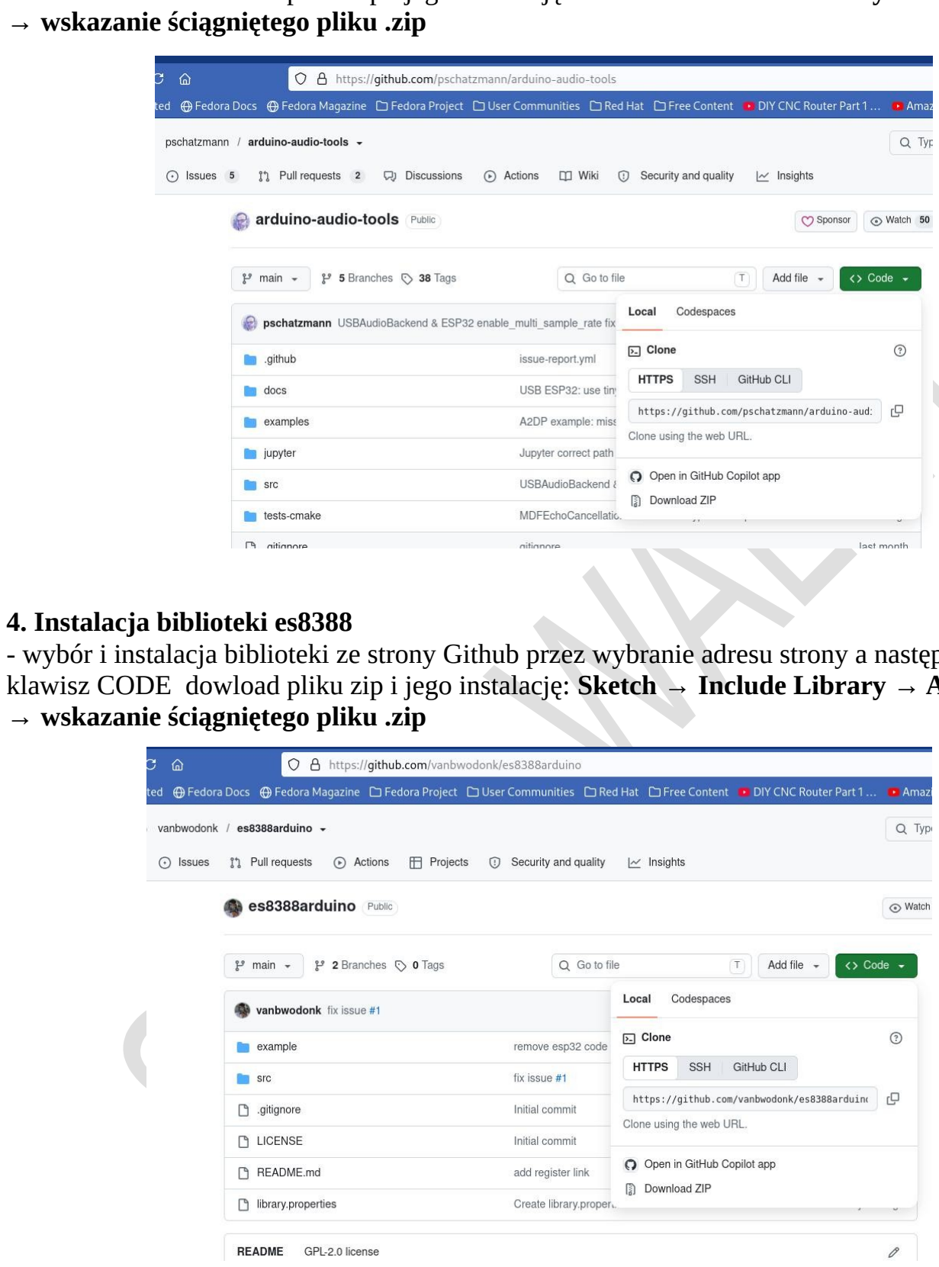
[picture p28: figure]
→ wskazanie ściągniętego pliku .zip; 4. Instalacja biblioteki es8388

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

Niezbędne do pracy pliki można też ściągnąć z mojej strony i wgrać je w głównym katalogu projektu (sketch-a):
https://lx-net.pl/img/es8388.cpp
https://lx-net.pl/img/es8388.h

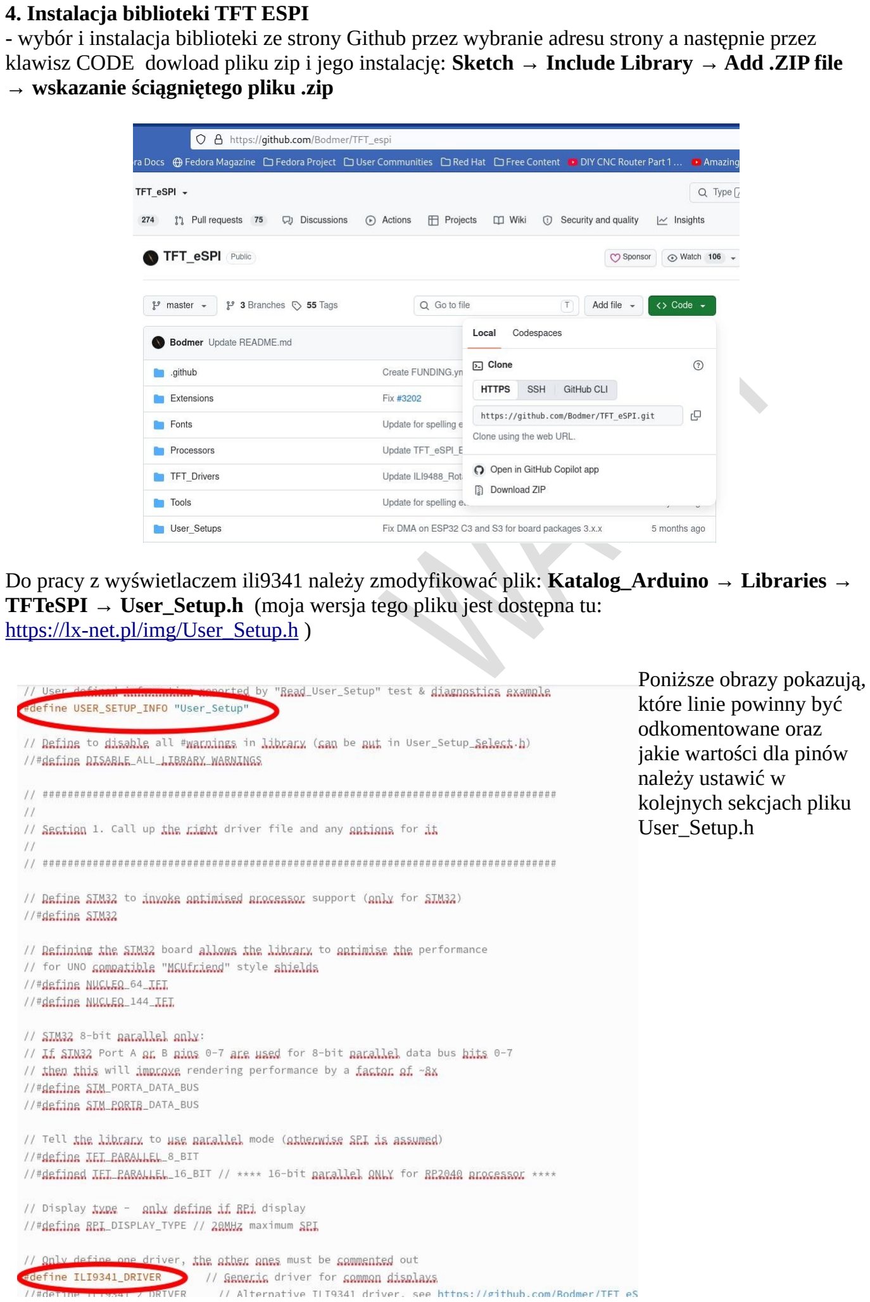
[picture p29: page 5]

### 4. Instalacja biblioteki TFT ESPI

- wybór i instalacja biblioteki ze strony Github przez wybranie adresu strony a następnie przez klawisz CODE dowload pliku zip i jego instalację: Sketch → Include Library → Add .ZIP file → wskazanie ściągniętego pliku .zip

Do pracy z wyświetlaczem ili9341 należy zmodyfikować plik: Katalog_Arduino → Libraries → TFTeSPI → User_Setup.h (moja wersja tego pliku jest dostępna tu: https://lx-net.pl/img/User_Setup.h )

Poniższe obrazy pokazują,
które linie powinny być
odkomentowane oraz
jakie wartości dla pinów
należy ustawić w
kolejnych sekcjach pliku
User_Setup.h

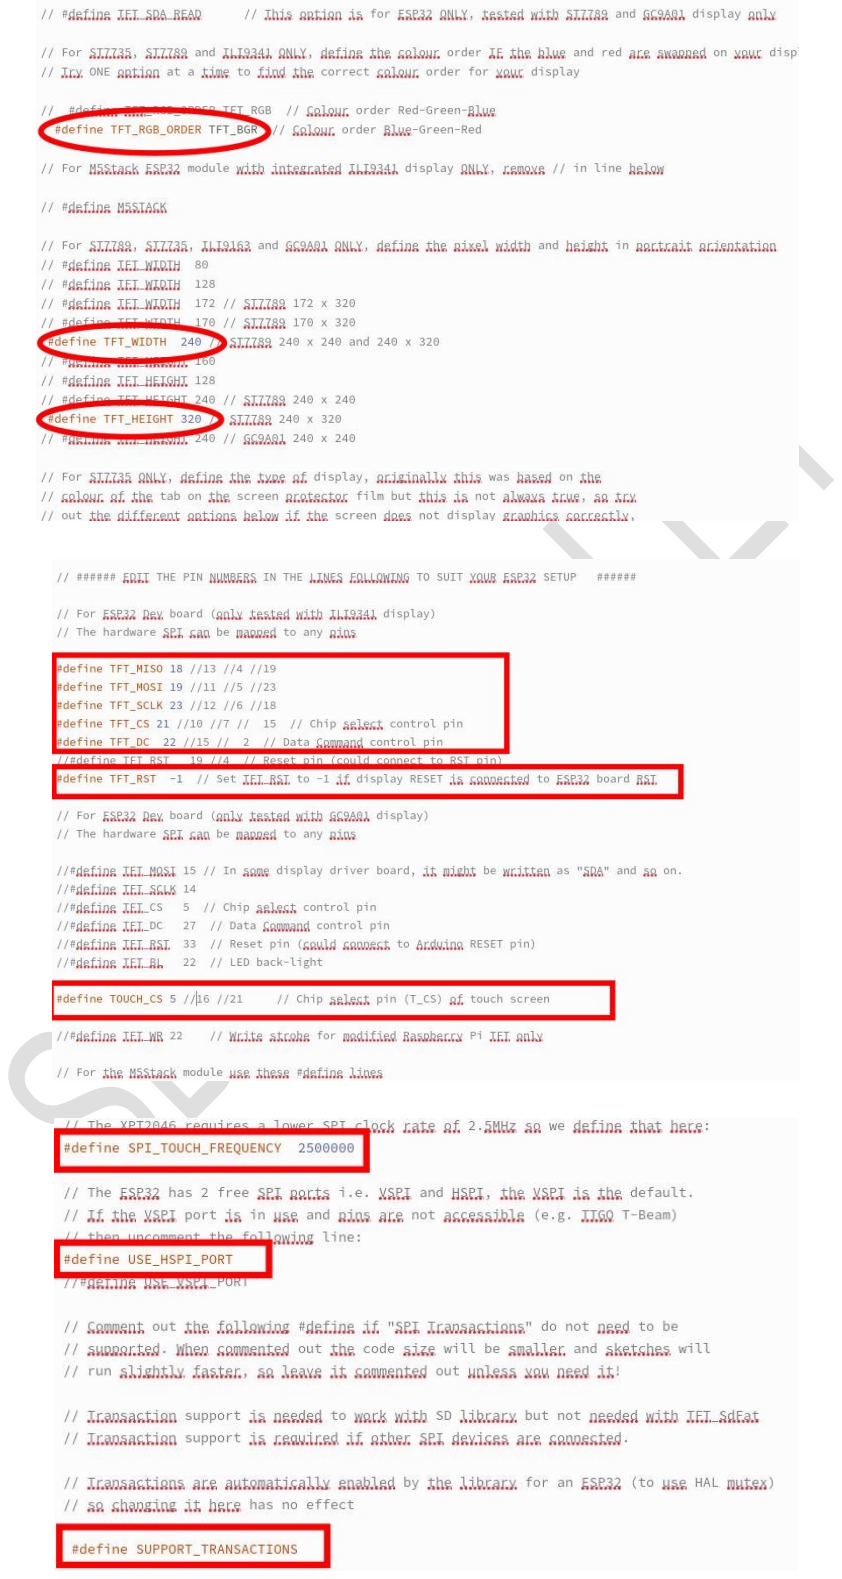
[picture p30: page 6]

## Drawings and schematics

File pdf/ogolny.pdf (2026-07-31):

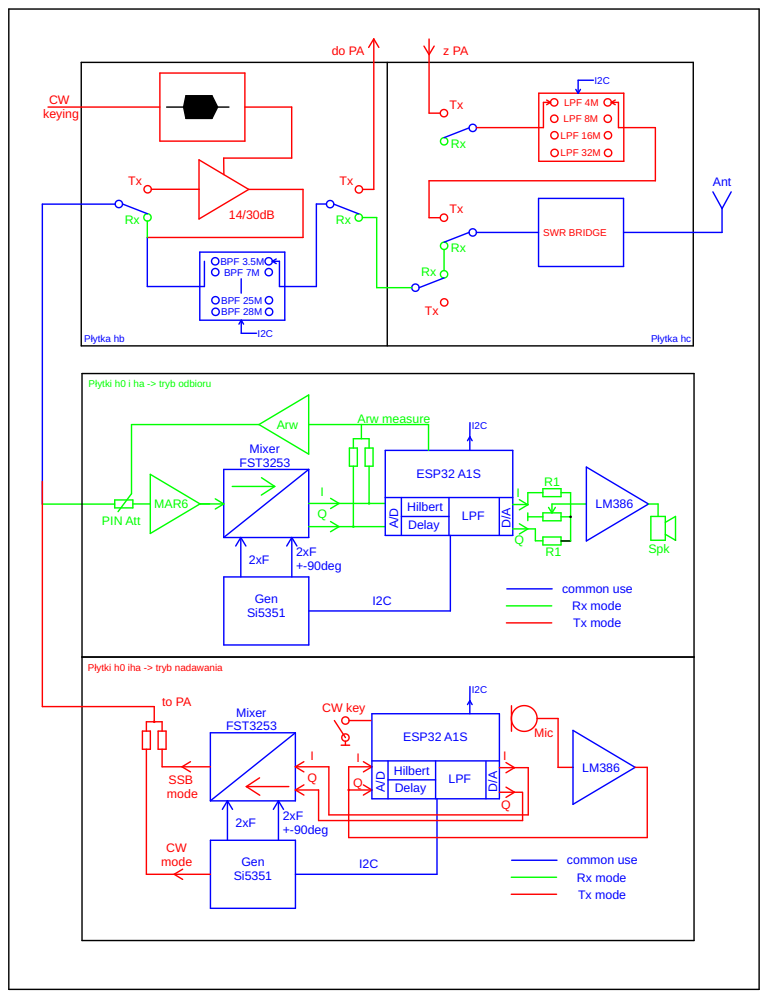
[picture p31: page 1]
Gen Si5351; common use Rx mode Tx mode; 2xF +-90deg; R1R1 Mixer FST3253; ESP32 A1S; D/A D/A Hilbert; Hilbert; Delay; LPF; keying; CW key; Mic; Spk LM386; Ant; Arw MAR6; BPF 3.5M BPF 7M; BPF 25M BPF 28M; LPF 4M; LPF 8M LPF 16M; LPF 32M; Płytka hc; SWR BRIDGE; PIN Att; Arw measure

Płytka hb Płytki h0 i ha -> tryb odbioru

LPF

common use Rx mode Tx mode

Płytki h0 iha -> tryb nadawania

Mixer FST3253
mode SSB mode

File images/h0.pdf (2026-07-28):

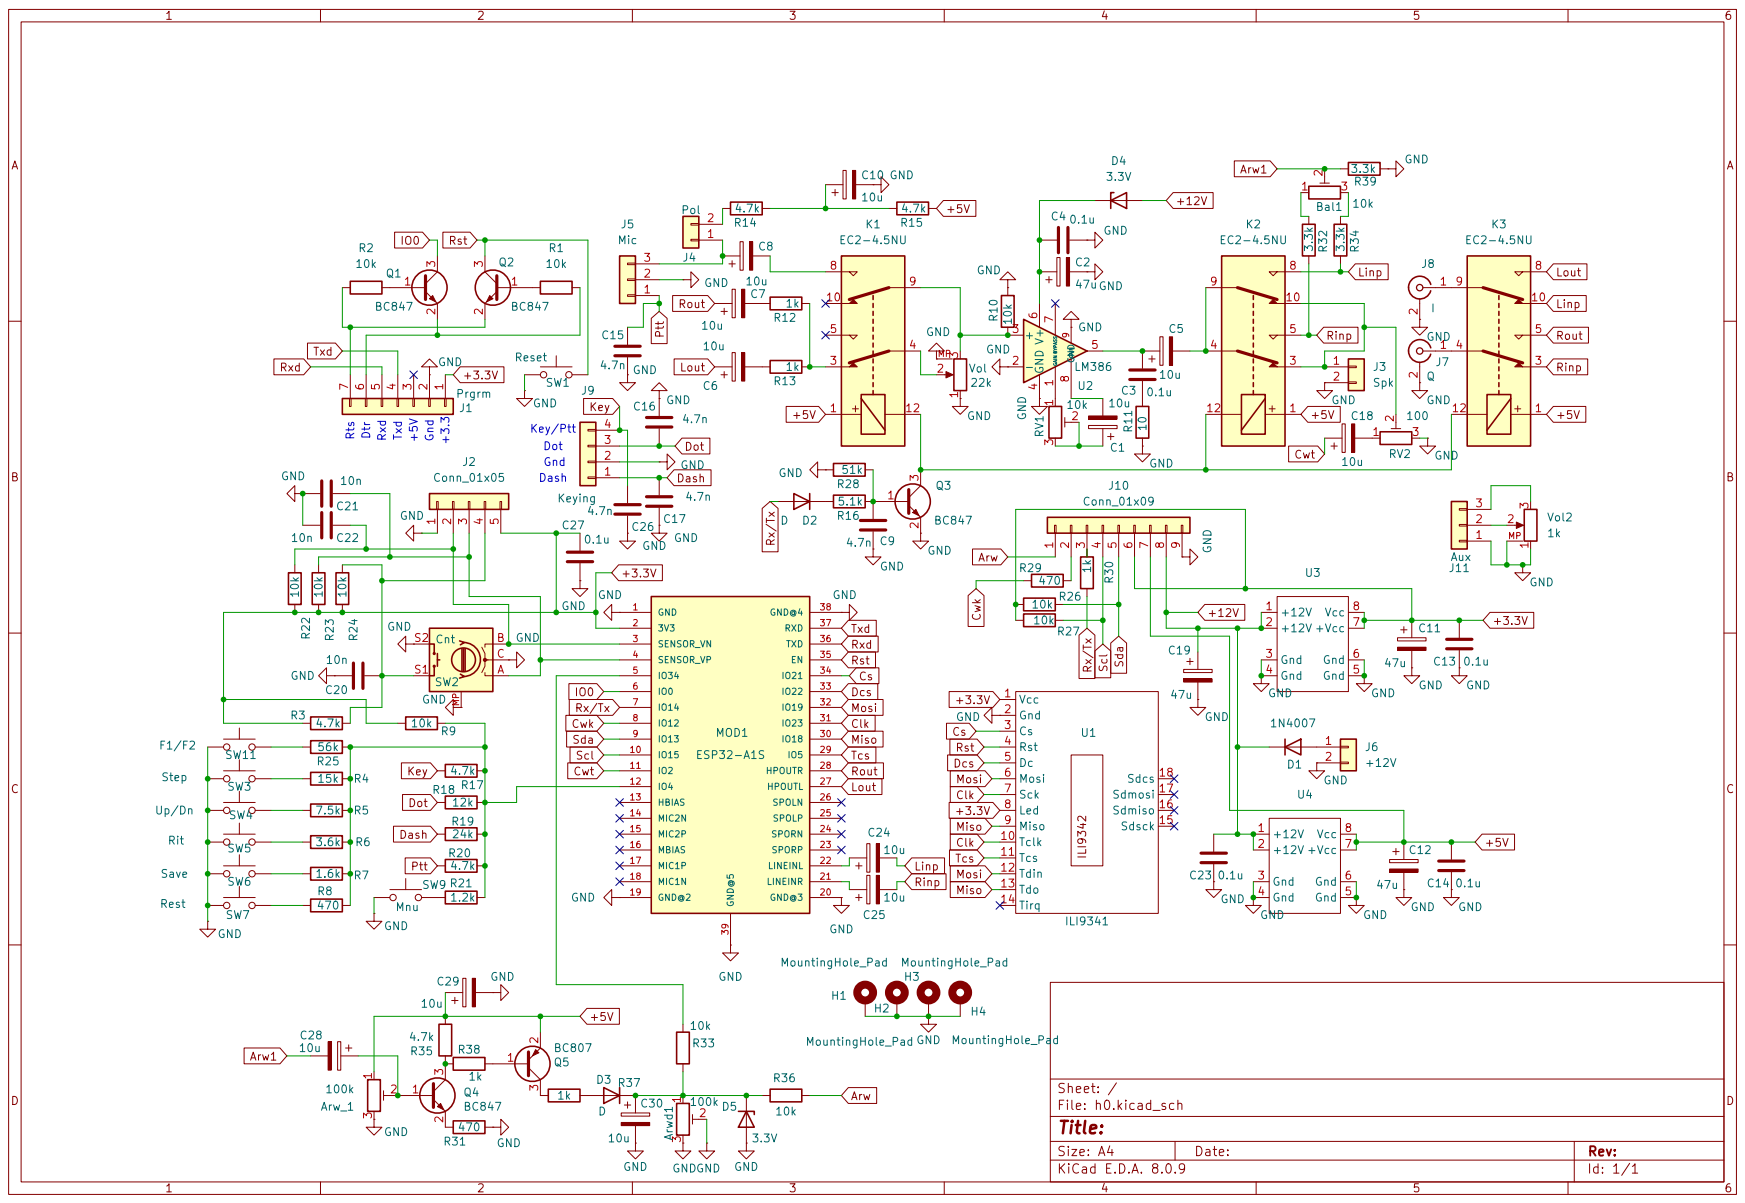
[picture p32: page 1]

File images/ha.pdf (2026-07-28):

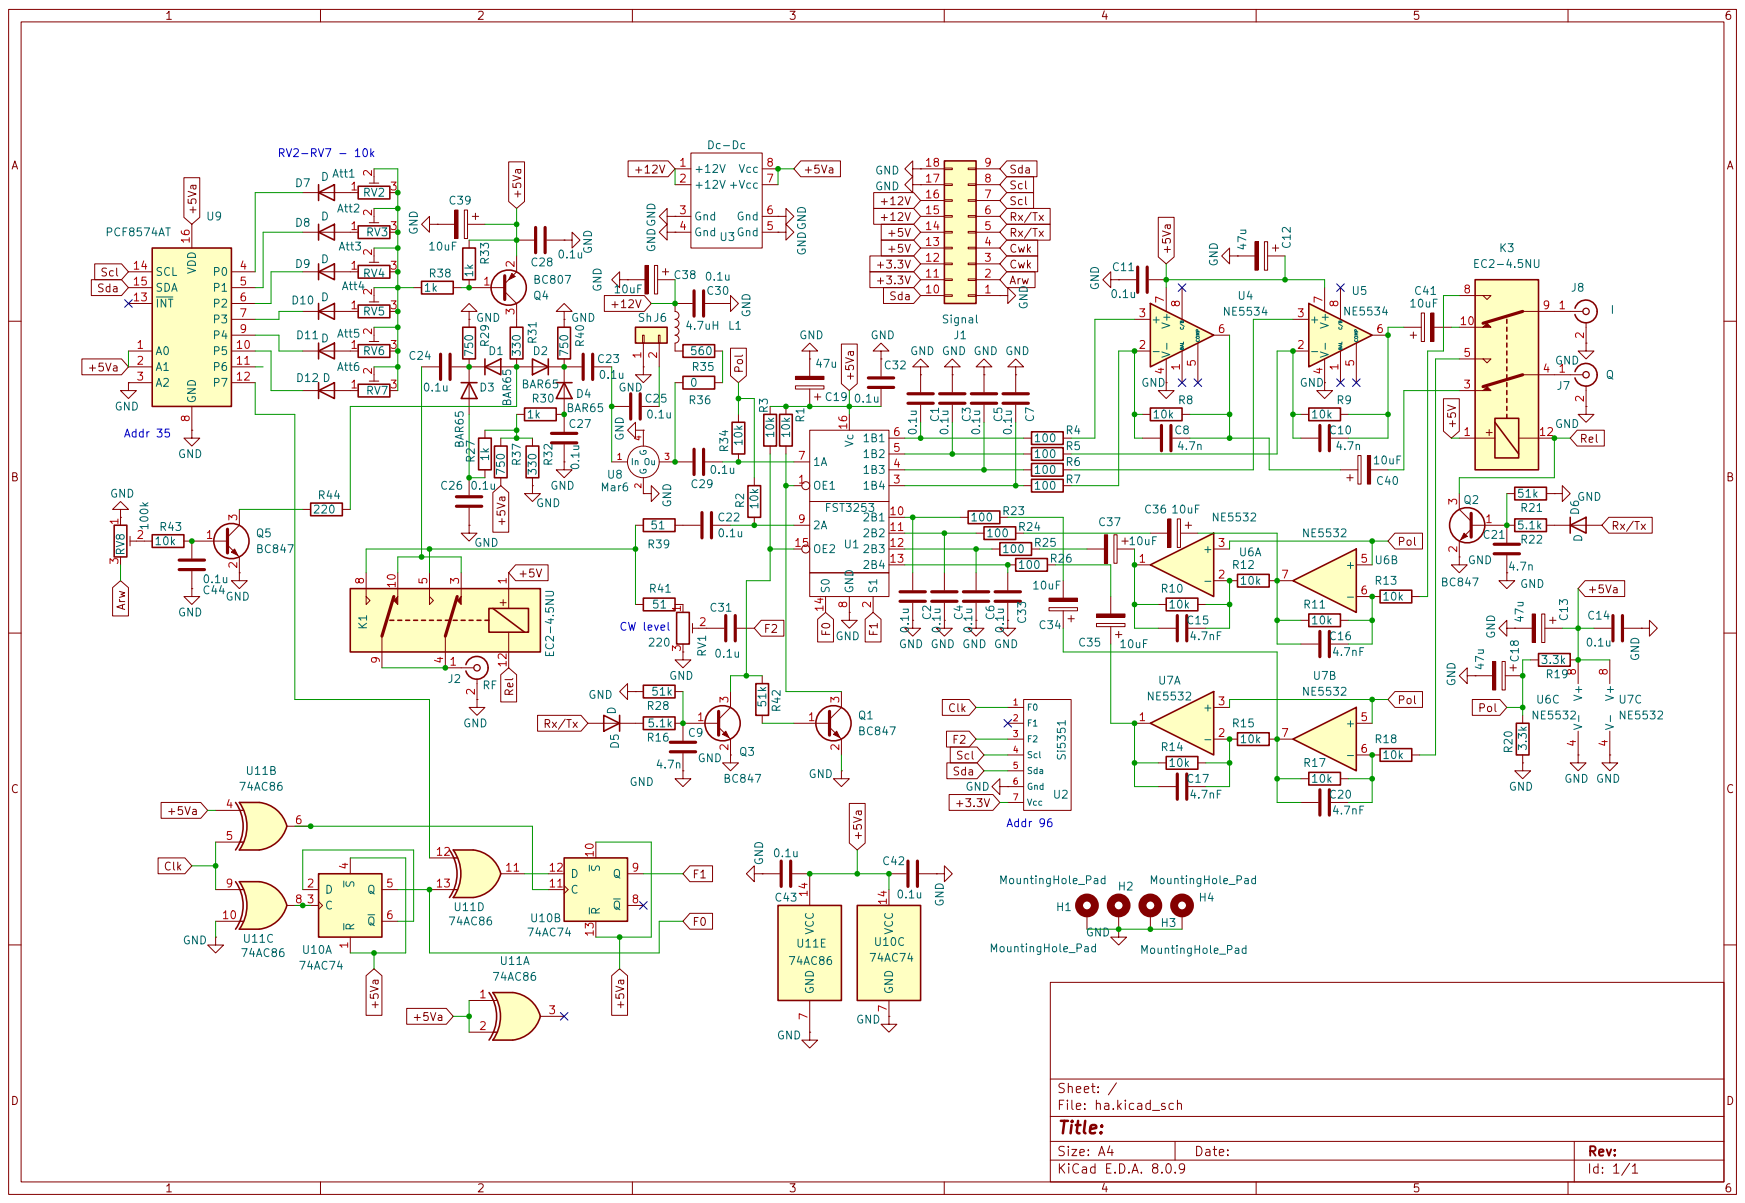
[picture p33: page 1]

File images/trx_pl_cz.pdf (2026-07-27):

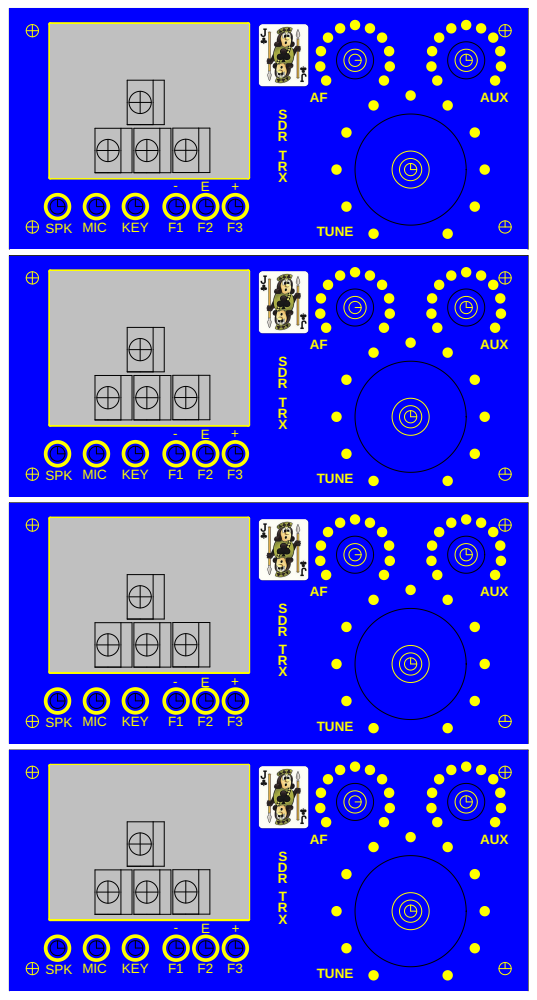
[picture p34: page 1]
TUNE TUNE TUNE TUNE AFAFAFAF SSSSDDDDRRRRTTTTRRRRXXXX; AUX AUX AUX AUX SPK SPK SPK SPK MIC KEY MIC KEY MIC KEY MIC KEY

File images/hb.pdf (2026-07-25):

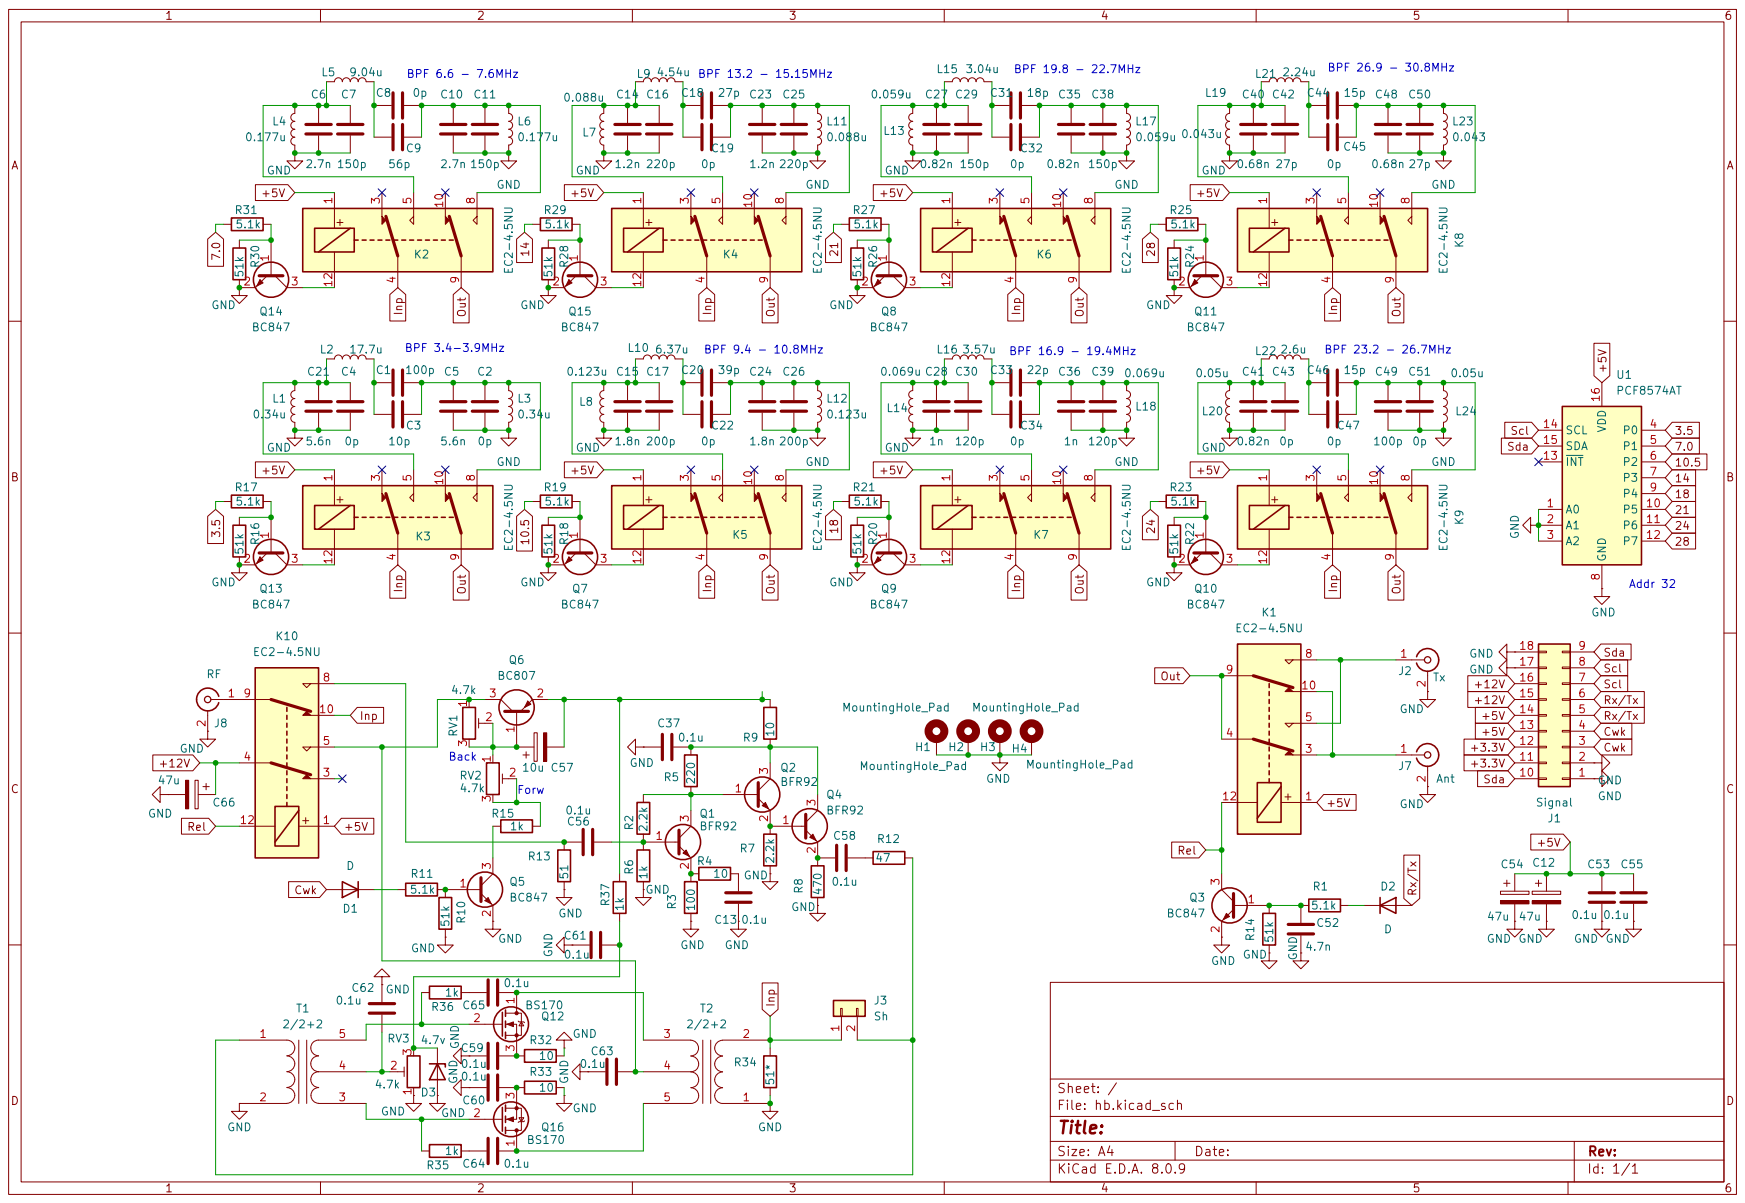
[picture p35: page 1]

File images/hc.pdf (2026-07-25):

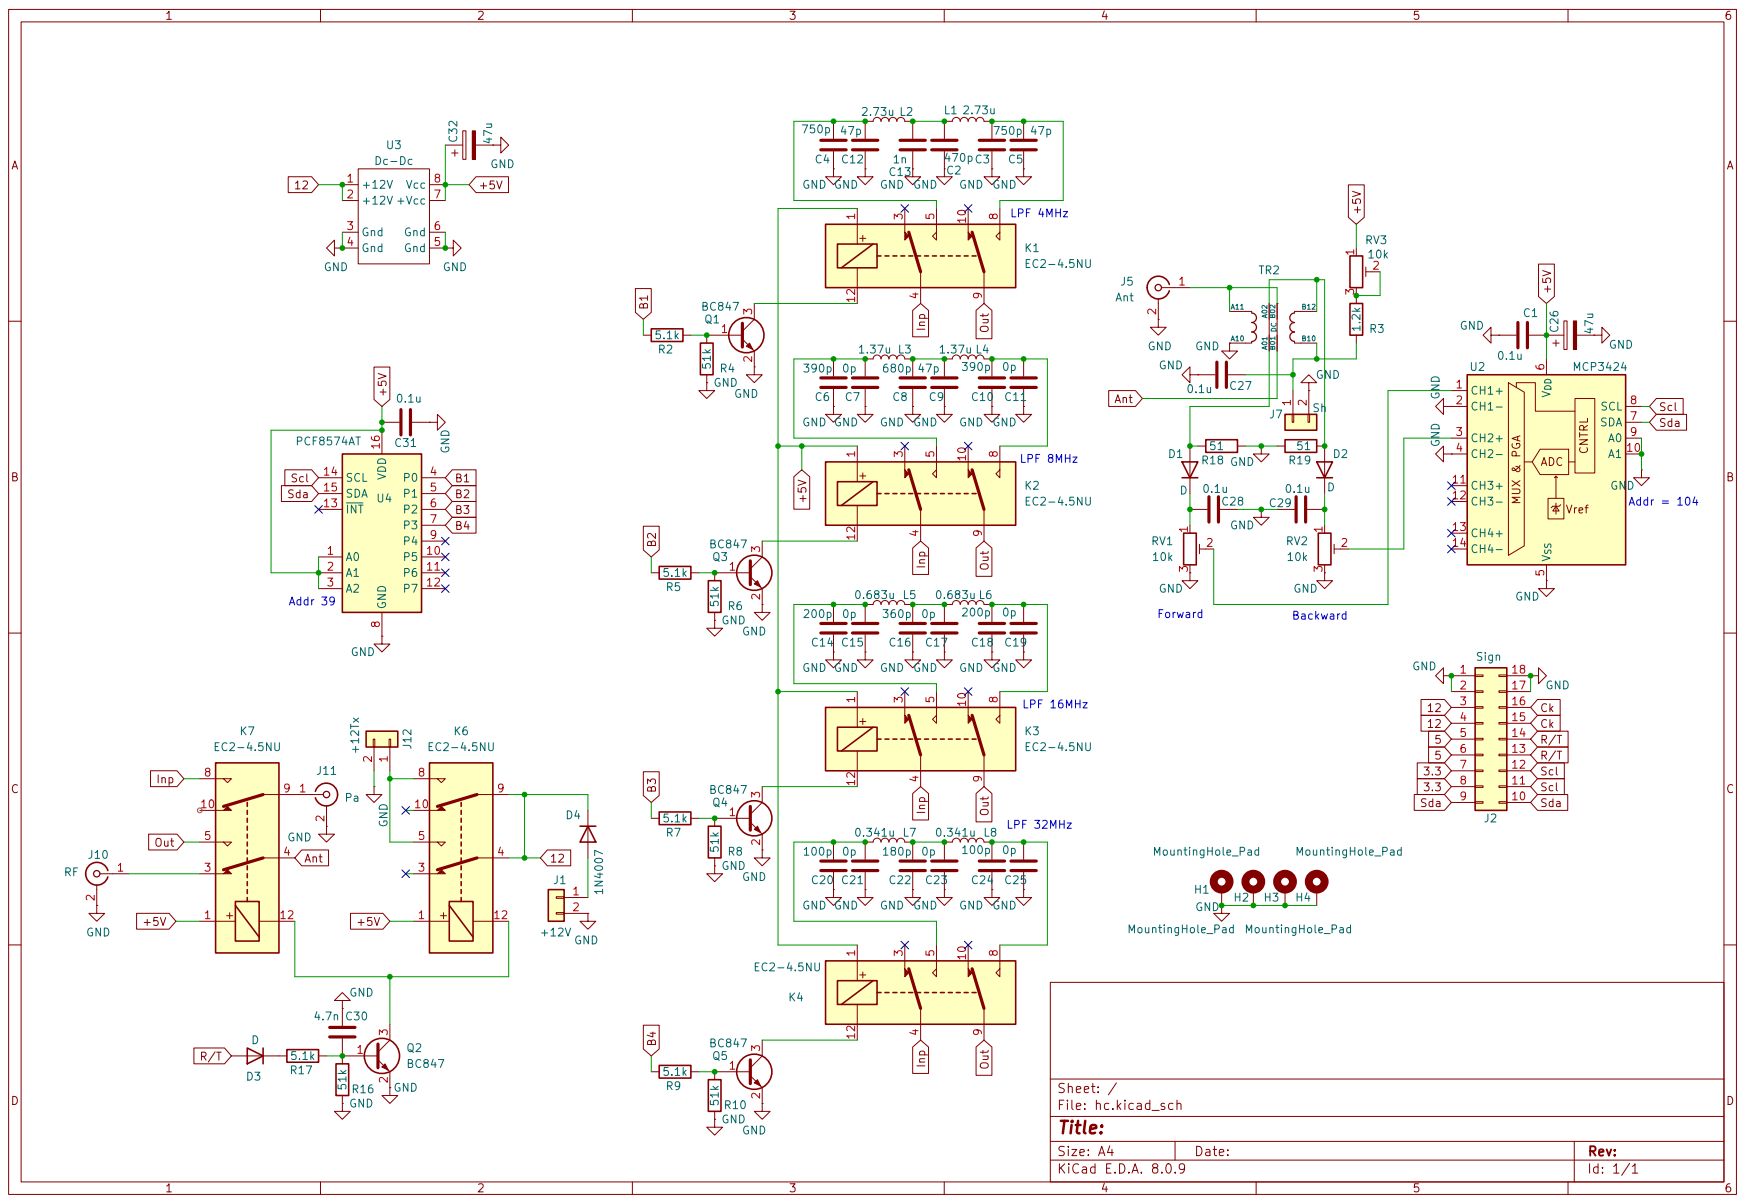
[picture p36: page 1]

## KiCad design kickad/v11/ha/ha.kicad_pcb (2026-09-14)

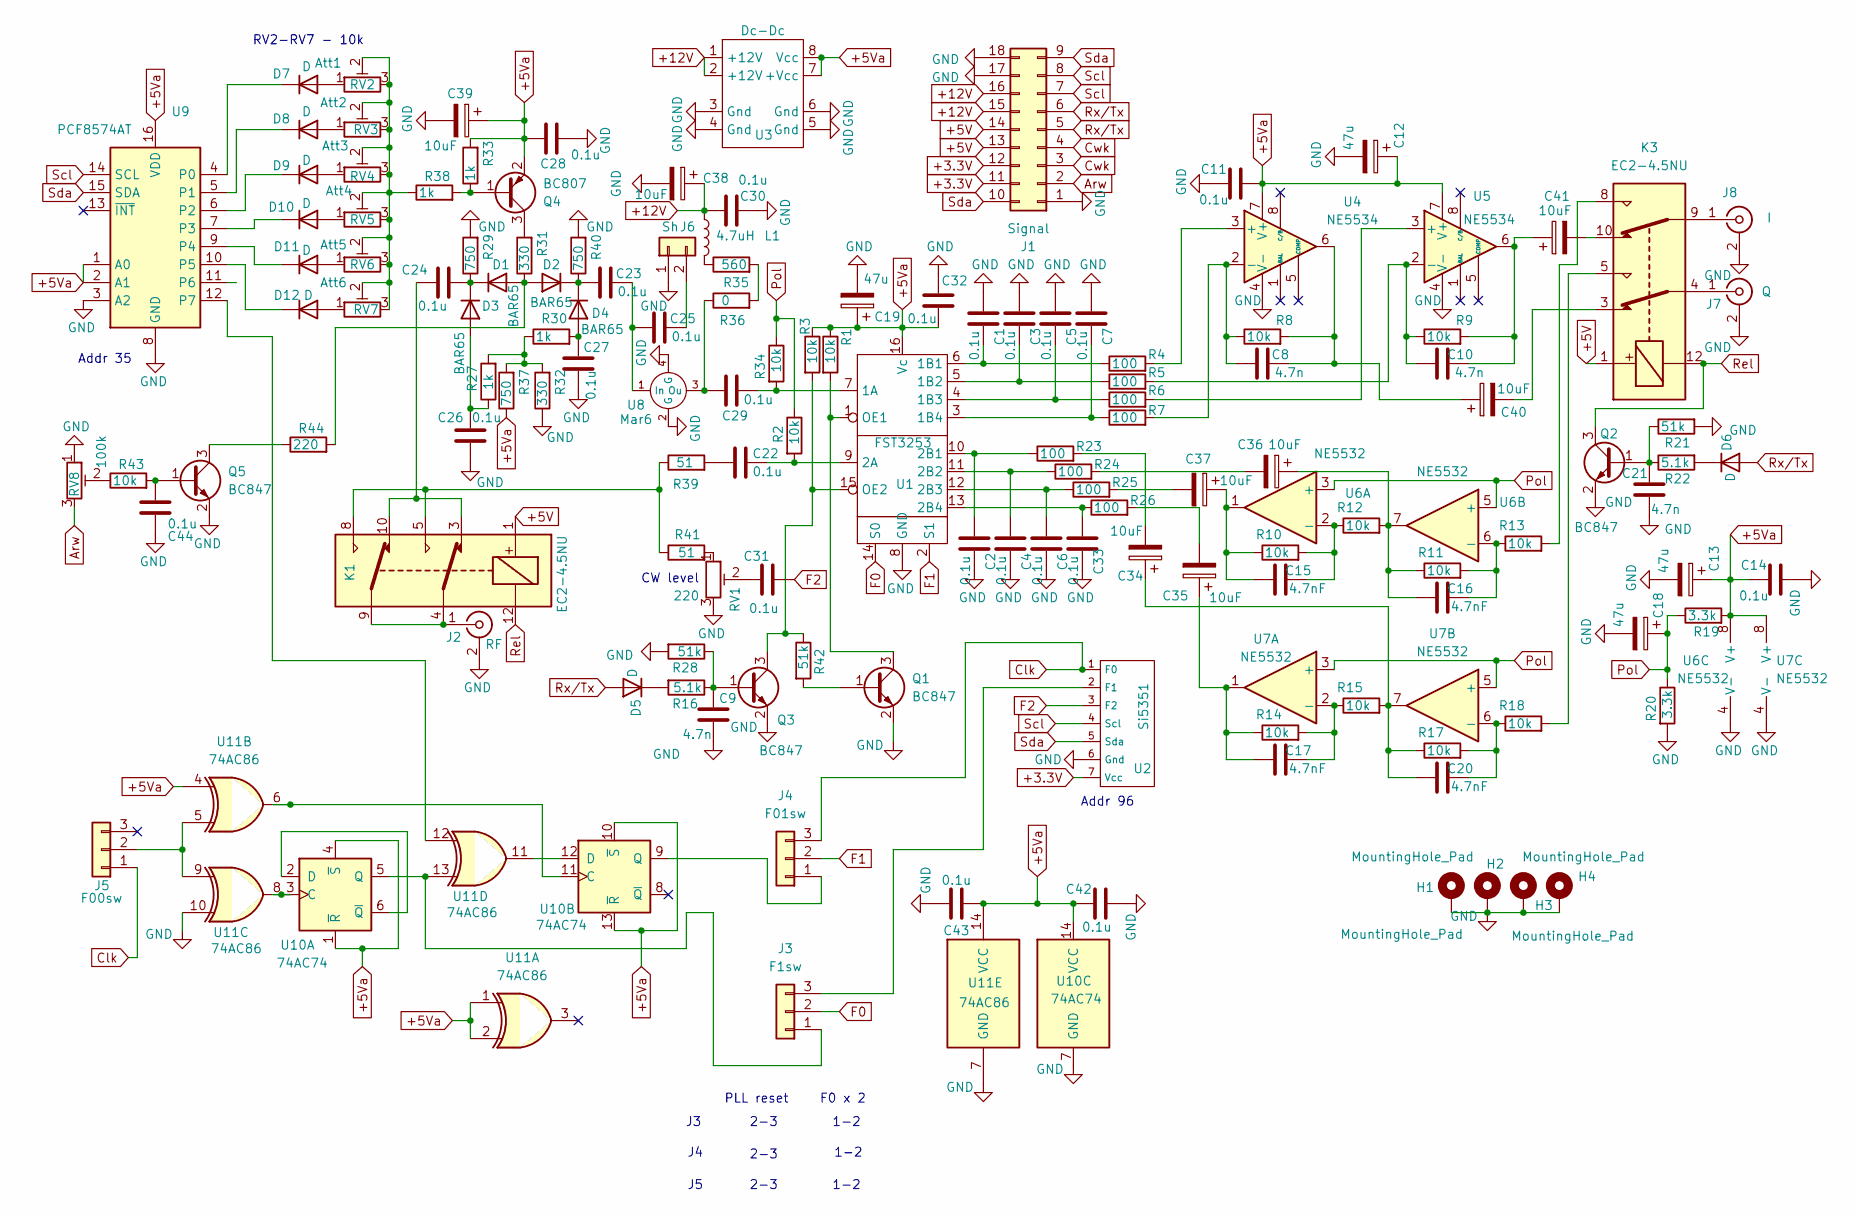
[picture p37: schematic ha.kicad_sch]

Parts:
C1, C2, C3, C4, C5, C6, C7, C11, C14, C22, C23, C24, C25, C26, C27, C28, C29, C30, C31, C32, C33, C42, C43, C44: 0.1u; C_0805_2012Metric
C8, C9, C10, C21: 4.7n; C_0805_2012Metric
C12, C13, C18, C19: 47u; CP_EIA-7343-31_Kemet-D
C15, C16, C17, C20: 4.7nF; C_0805_2012Metric
C34, C35, C36, C37, C38, C39, C40, C41: 10uF; C_1206_3216Metric
D1, D2, D3, D4: BAR65; C_0805_2012Metric
D5, D6, D7, D8, D9, D10, D11, D12: D; C_1206_3216Metric
H1, H2, H3, H4: MountingHole_Pad; MountingHole_3.2mm_M3_Pad_Via
J1: Signal; PinHeader_2x09_P2.54mm_Vertical
J2: RF; SMA_Amphenol_901-144_Vertical
J3: F1sw; PinHeader_1x03_P2.54mm_Vertical
J4: F01sw; PinHeader_1x03_P2.54mm_Vertical
J5: F00sw; PinHeader_1x03_P2.54mm_Vertical
J6: Sh; PinHeader_1x02_P2.54mm_Vertical
J7: Q; SMA_Amphenol_901-144_Vertical
J8: I; SMA_Amphenol_901-144_Vertical
K1, K3: EC2-4.5NU; Relay_DPDT_Kemet_EC2_NJ
L1: 4.7uH; L_Axial_L5.3mm_D2.2mm_P7.62mm_Horizontal_Vishay_IM-1
Q1, Q2, Q3, Q5: BC847; SOT-23
Q4: BC807; SOT-23
R1, R2, R3, R8, R9, R10, R11, R12, R13, R14, R15, R17, R18, R34, R43: 10k; R_0805_2012Metric
R4, R5, R6, R7, R23, R24, R25, R26: 100; R_0805_2012Metric
R16, R22: 5.1k; R_0805_2012Metric
R19, R20: 3.3k; R_0805_2012Metric
R21, R28, R42: 51k; R_0805_2012Metric
R27, R30, R33, R38: 1k; R_0805_2012Metric
R29, R37, R40: 750; R_0805_2012Metric
R31, R32: 330; R_0805_2012Metric
R35: 560; R_0805_2012Metric
R36: 0; R_0805_2012Metric
R39, R41: 51; R_0805_2012Metric
R44: 220; R_0805_2012Metric
RV1: 220; Potentiometer_ACP_CA6-H2,5_Horizontal
RV2: Att1; Potentiometer_ACP_CA6-H2,5_Horizontal
RV3: Att2; Potentiometer_ACP_CA6-H2,5_Horizontal
RV4: Att3; Potentiometer_ACP_CA6-H2,5_Horizontal
RV5: Att4; Potentiometer_ACP_CA6-H2,5_Horizontal
RV6: Att5; Potentiometer_ACP_CA6-H2,5_Horizontal
RV7: Att6; Potentiometer_ACP_CA6-H2,5_Horizontal
RV8: 100k; Potentiometer_ACP_CA6-H2,5_Horizontal
U1: FST3253; SOIC-16W_5.3x10.2mm_P1.27mm
U2: Si5351
U3: Dc-Dc; dc-dc
U4, U5: NE5534; SO-8_3.9x4.9mm_P1.27mm
U6, U7: NE5532; SO-8_3.9x4.9mm_P1.27mm
U8: Mar6; Era
U9: PCF8574AT; SOIC-16W_7.5x10.3mm_P1.27mm
U10: 74AC74; SO-14_5.3x10.2mm_P1.27mm
U11: 74AC86; SO-14_5.3x10.2mm_P1.27mm

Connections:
+3.3V: J1.11, J1.12, U2.7 (Vcc)
+5V: J1.13, J1.14, K1.1, K3.1
+5Va: C11.1, C12.1, C13.1, C14.2, C19.1, C28.1, C32.1, C39.1, C42.2, C43.2, Q4.2 (E), R1.1, R3.1, R19.2, R33.2, R37.1, U1.16 (Vc), U3.7 (+Vcc), U3.8 (Vcc), U4.7 (V+), U5.7 (V+), U6.8 (V+), U7.8 (V+), U9.1 (A0), U9.2 (A1), U9.16 (VDD), U10.1 (~R), U10.4 (~S), U10.10 (~S), U10.13 (~R), U10.14 (VCC), U11.1, U11.2, U11.4, U11.14 (VCC)
+12V: C30.2, C38.1, J1.15, J1.16, L1.1, U3.1 (+12V), U3.2 (+12V)
Arw: J1.2, RV8.3
Clk: J4.3, J5.1, U2.1 (F0)
Cwk: J1.3, J1.4
F0: J3.2, U1.14 (S0)
F1: J4.2, U1.2 (S1)
F2: C31.1, U2.3 (F2)
GND: C1.2, C2.1, C3.2, C4.1, C5.2, C6.1, C7.2, C9.1, C11.2, C12.2, C13.2, C14.1, C18.2, C19.2, C21.1, C26.2, C27.2, C28.2, C30.1, C32.2, C33.1, C38.2, C39.2, C42.1, C43.1, C44.1, H1.1, H2.1, H3.1, H4.1, J1.1, J1.17, J1.18, J2.2 (Ext), J6.1, J7.2 (Ext), J8.2 (Ext), Q1.2 (E), Q2.2 (E), Q3.2 (E), Q5.2 (E), R20.2, R21.2, R28.2, R29.2, R32.1, R40.2, RV1.3, RV8.1, U1.8 (GND), U2.6 (Gnd), U3.3 (Gnd), U3.4 (Gnd), U3.5 (Gnd), U3.6 (Gnd), U4.4 (V-), U5.4 (V-), U6.4 (V-), U7.4 (V-), U8.2 (G), U8.4 (G), U9.3 (A2), U9.8 (GND), U10.7 (GND), U11.7 (GND), U11.10
unnamed: C10.1, C41.1, R9.2, U5.6
unnamed: C15.2, C37.1, R10.1, U6.1
unnamed: C16.2, C36.1, R11.1, R12.2, U6.7
unnamed: C17.2, C35.1, R14.1, U7.1
unnamed: C20.2, C34.1, R15.2, R17.1, U7.7
unnamed: C22.2, R39.2
unnamed: C24.2, K1.3, K1.10
unnamed: C31.2, RV1.2
unnamed: C34.2, R23.2
unnamed: C35.2, R26.2
unnamed: C36.2, R24.2
unnamed: C37.2, R25.2
unnamed: C8.1, C40.1, R8.2, U4.6
unnamed: C40.2, K3.3
unnamed: C41.2, K3.10
unnamed: D1.2 (A), D2.2 (A), R31.1, R44.2
unnamed: C24.1, D1.1 (K), D3.1 (K), R29.1
unnamed: C23.2, D2.1 (K), D4.1 (K), R40.1
unnamed: C26.1, D3.2 (A), R27.1
unnamed: C27.1, D4.2 (A), R30.2
unnamed: D5.1 (K), R16.2
unnamed: D6.1 (K), R22.2
unnamed: D7.2 (A), RV2.1
unnamed: D7.1 (K), U9.4 (P0)
unnamed: D8.2 (A), RV3.1
unnamed: D8.1 (K), U9.5 (P1)
unnamed: D9.2 (A), RV4.1
unnamed: D9.1 (K), U9.6 (P2)
unnamed: D10.2 (A), RV5.1
unnamed: D10.1 (K), U9.7 (P3)
unnamed: D11.2 (A), RV6.1
unnamed: D11.1 (K), U9.9 (P4)
unnamed: D12.2 (A), RV7.1
unnamed: D12.1 (K), U9.10 (P5)
unnamed: J2.1 (In), K1.4, K1.9
unnamed: J3.1, U10.5 (Q), U11.13
unnamed: J3.3, U2.2 (F1)
unnamed: J4.1, U10.9 (Q)
unnamed: J5.2, U11.5, U11.9
unnamed: C25.1, J6.2
unnamed: J7.1 (In), K3.4
unnamed: J8.1 (In), K3.9
unnamed: K1.5, K1.8, R39.1, R41.1
unnamed: K3.5, R18.2
unnamed: K3.8, R13.2
unnamed: L1.2, R35.1
unnamed: Q1.1 (B), R42.2
unnamed: Q1.3 (C), R1.2, U1.1 (OE1)
unnamed: C21.2, Q2.1 (B), R21.1, R22.1
unnamed: C9.2, Q3.1 (B), R16.1, R28.1
unnamed: Q3.3 (C), R3.2, R42.1, U1.15 (OE2)
unnamed: Q4.1 (B), R33.1, R38.2
unnamed: Q4.3 (C), R31.2
unnamed: C44.2, Q5.1 (B), R43.2
unnamed: Q5.3 (C), R44.1
unnamed: R27.2, R30.1, R32.2, R37.2
unnamed: R35.2, R36.2
unnamed: R38.1, RV2.2, RV2.3, RV3.2, RV3.3, RV4.2, RV4.3, RV5.2, RV5.3, RV6.2, RV6.3, RV7.2, RV7.3
unnamed: R41.2, RV1.1
unnamed: R43.1, RV8.2
unnamed: C29.1, R34.2, U1.7 (1A)
unnamed: C1.1, R4.1, U1.6 (1B1)
unnamed: C3.1, R5.1, U1.5 (1B2)
unnamed: C5.1, R6.1, U1.4 (1B3)
unnamed: C7.1, R7.1, U1.3 (1B4)
unnamed: C22.1, R2.2, U1.9 (2A)
unnamed: C2.2, R23.1, U1.10 (2B1)
unnamed: C4.2, R24.1, U1.11 (2B2)
unnamed: C6.2, R25.1, U1.12 (2B3)
unnamed: C33.2, R26.1, U1.13 (2B4)
unnamed: R4.2, U4.3 (+)
unnamed: C8.2, R7.2, R8.1, U4.2 (-)
unnamed: R6.2, U5.3 (+)
unnamed: C10.2, R5.2, R9.1, U5.2 (-)
unnamed: C15.1, R10.2, R12.1, U6.2 (-)
unnamed: C16.1, R11.2, R13.1, U6.6 (-)
unnamed: C17.1, R14.2, R15.1, U7.2 (-)
unnamed: C20.1, R17.2, R18.1, U7.6 (-)
unnamed: C23.1, C25.2, U8.1 (In)
unnamed: C29.2, R36.1, U8.3 (Ou)
unnamed: U9.12 (P7), U11.12
unnamed: U10.3 (C), U11.8
unnamed: U10.2 (D), U10.6 (~Q)
unnamed: U10.11 (C), U11.6
unnamed: U10.12 (D), U11.11
Pol: C18.1, R2.1, R19.1, R20.1, R34.1, U6.3 (+), U6.5 (+), U7.3 (+), U7.5 (+)
Rel: K1.12, K3.12, Q2.3 (C)
Rx/Tx: D5.2 (A), D6.2 (A), J1.5, J1.6
Scl: J1.7, J1.8, U2.4 (Scl), U9.14 (SCL)
Sda: J1.9, J1.10, U2.5 (Sda), U9.15 (SDA)

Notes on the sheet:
2-3
1-2
Addr 96
Addr 35
F0 x 2
PLL reset
RV2-RV7 - 10k
CW level

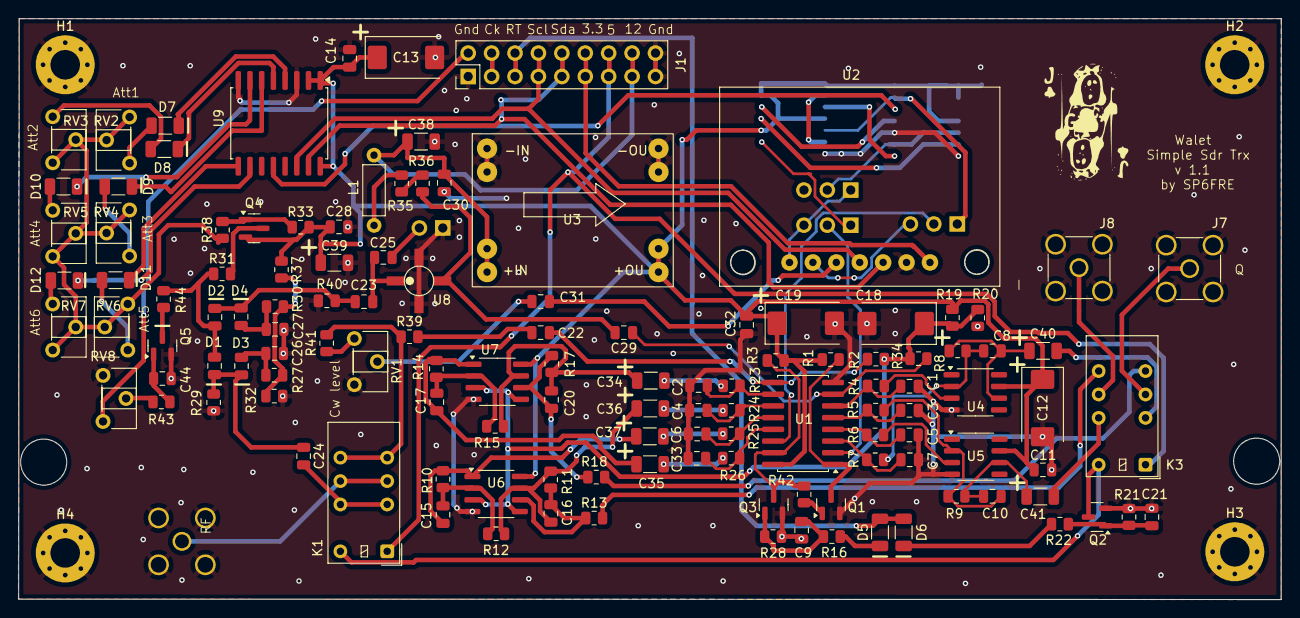
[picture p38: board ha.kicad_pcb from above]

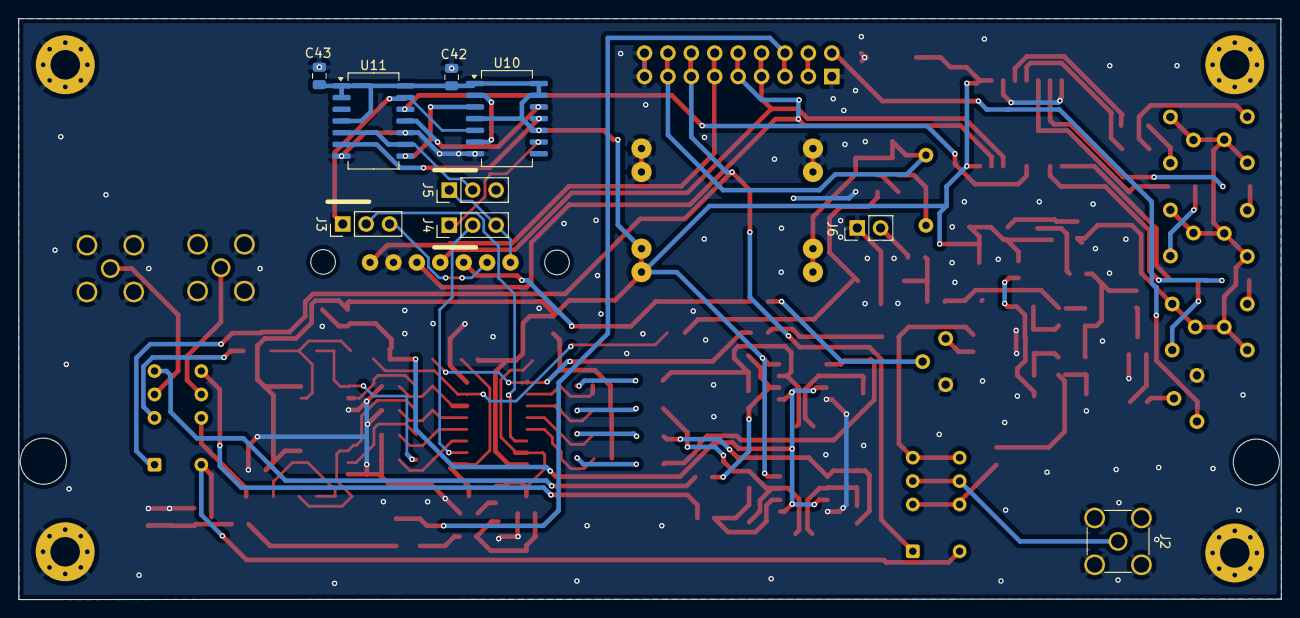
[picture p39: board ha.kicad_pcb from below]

Board: 2 copper layers, 137.0 x 63.0 mm, 139 parts (9 on the bottom side), 101 nets.

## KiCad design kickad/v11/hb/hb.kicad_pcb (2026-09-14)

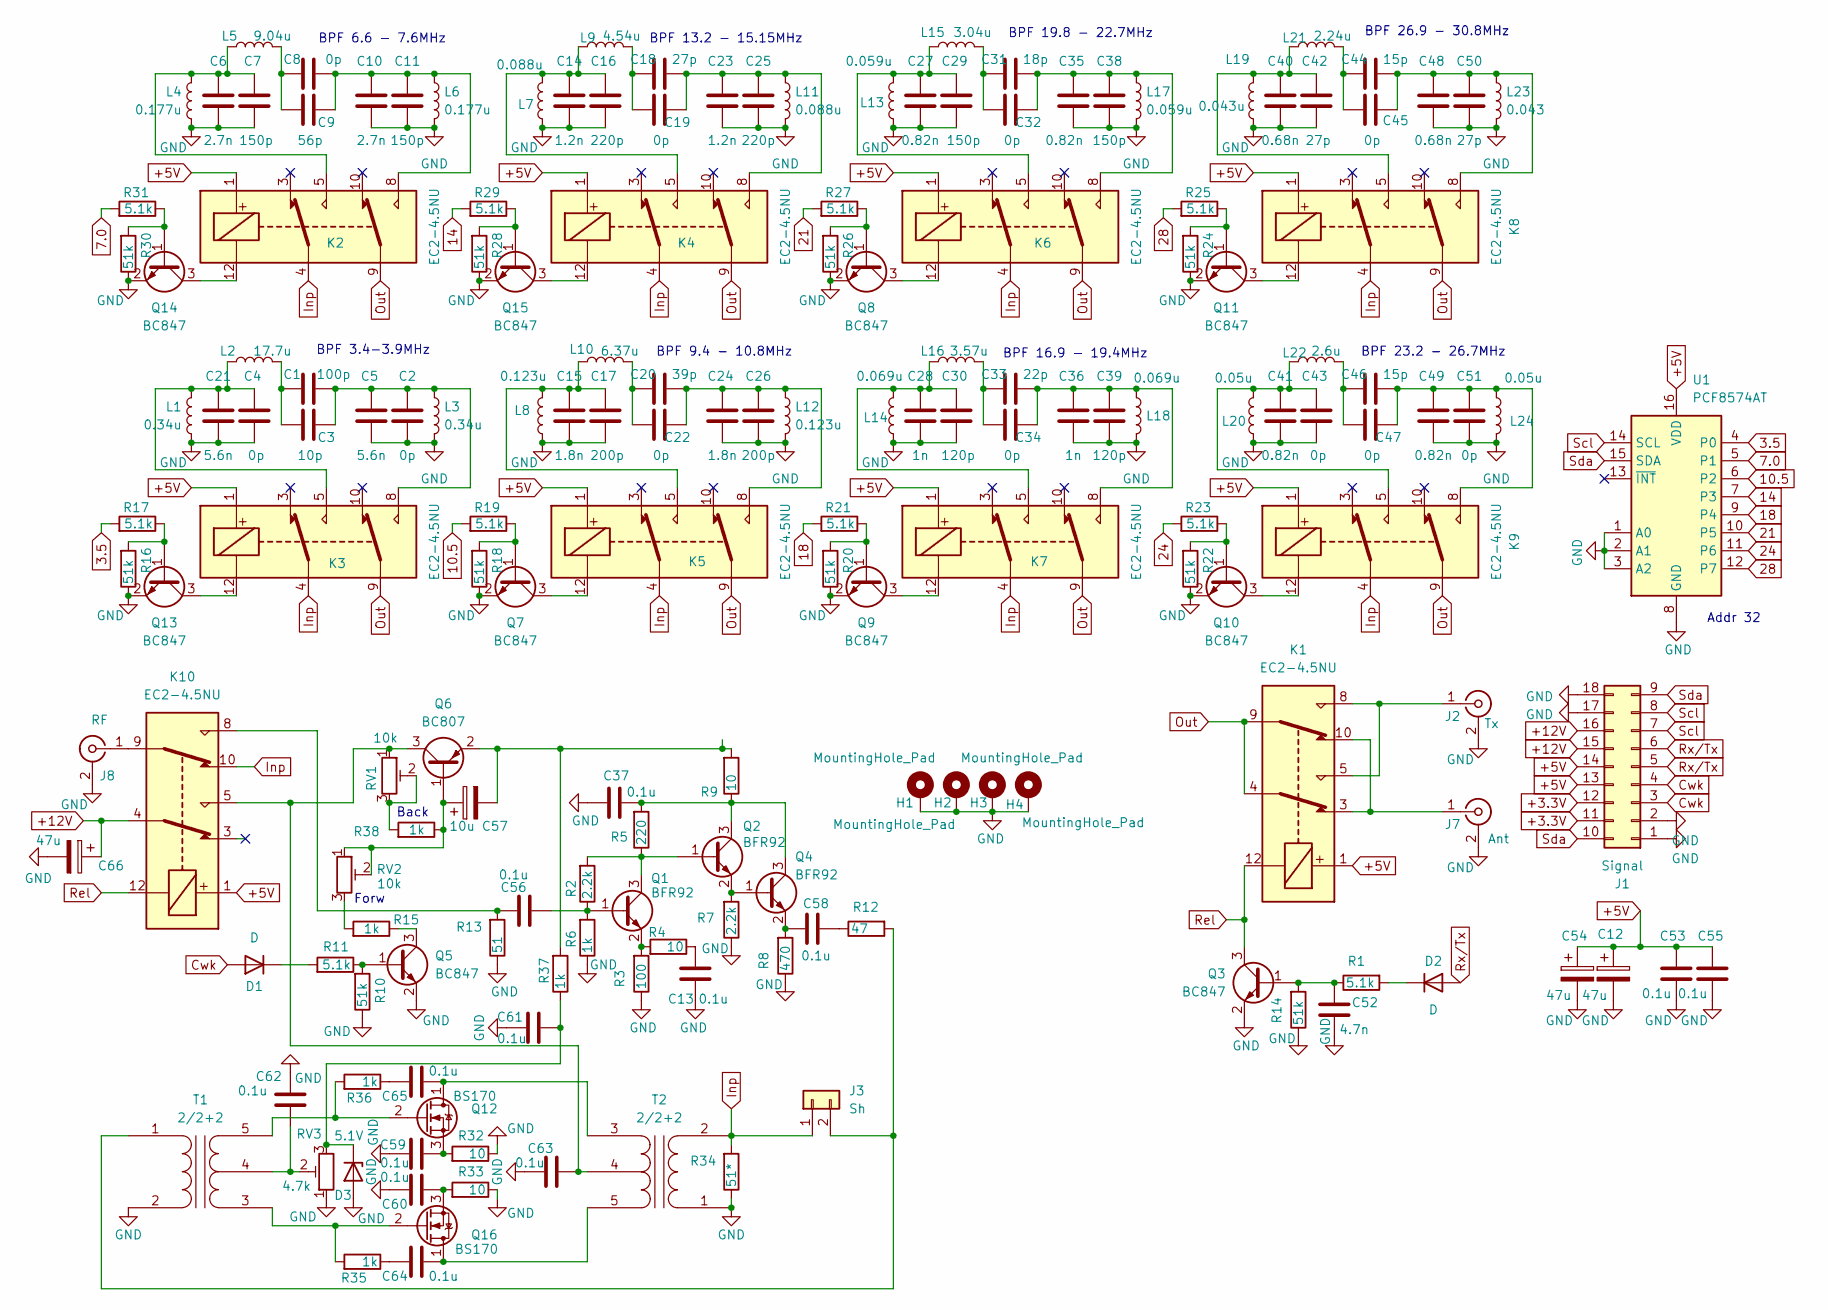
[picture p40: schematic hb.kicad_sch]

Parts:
C1: 10p; C_0805_2012Metric
C2, C4, C9, C18, C20, C31, C33, C43, C44, C46, C51: 0p; C_0805_2012Metric
C3: 100p; C_0805_2012Metric
C5, C21: 5.6n; C_0805_2012Metric
C6, C10: 2.7n; C_0805_2012Metric
C7, C11, C29, C38: 150p; C_0805_2012Metric
C8: 56p; C_0805_2012Metric
C12, C54, C66: 47u; CP_EIA-7343-31_Kemet-D
C13, C37, C53, C55, C56, C58, C59, C60, C61, C62, C63, C64, C65: 0.1u; C_0805_2012Metric
C14, C23: 1.2n; C_0805_2012Metric
C15, C24: 1.8n; C_0805_2012Metric
C16, C25: 220p; C_0805_2012Metric
C17, C26: 200p; C_0805_2012Metric
C19, C42, C50: 27p; C_0805_2012Metric
C22: 39p; C_0805_2012Metric
C27, C35, C41, C49: 0.82n; C_0805_2012Metric
C28, C36: 1n; C_0805_2012Metric
C30, C39: 120p; C_0805_2012Metric
C32: 18p; C_0805_2012Metric
C34: 22p; C_0805_2012Metric
C40, C48: 0.68n; C_0805_2012Metric
C45, C47: 15p; C_0805_2012Metric
C52: 4.7n; C_0805_2012Metric
C57: 10u; C_1206_3216Metric
D1, D2: D; C_1206_3216Metric
D3: 5.1V; C_1206_3216Metric
H1, H2, H3, H4: MountingHole_Pad; MountingHole_3.2mm_M3_Pad_Via
J1: Signal; PinHeader_2x09_P2.54mm_Vertical
J2: Tx; SMA_Amphenol_901-144_Vertical
J3: Sh; PinHeader_1x02_P2.54mm_Vertical
J7: Ant; SMA_Amphenol_901-144_Vertical
J8: RF; SMA_Amphenol_901-144_Vertical
K1, K2, K3, K4, K5, K6, K7, K8, K9, K10: EC2-4.5NU; Relay_DPDT_Kemet_EC2_NJ
L1, L3: 0.34u; l_01
L2: 17.7u; l_01
L4, L6: 0.177u; l_01
L5: 9.04u; l_01
L7, L11: 0.088u; l_01
L8, L12: 0.123u; l_01
L9: 4.54u; l_01
L10: 6.37u; l_01
L13, L17: 0.059u; l_01
L14, L18: 0.069u; l_01
L15: 3.04u; l_01
L16: 3.57u; l_01
L19: 0.043u; l_01
L20, L24: 0.05u; l_01
L21: 2.24u; l_01
L22: 2.6u; l_01
L23: 0.043; l_01
Q1, Q2, Q4: BFR92; SOT-23
Q3, Q5, Q7, Q8, Q9, Q10, Q11, Q13, Q14, Q15: BC847; SOT-23
Q6: BC807; SOT-23
Q12, Q16: BS170; TO-92_Inline
R1, R11, R17, R19, R21, R23, R25, R27, R29, R31: 5.1k; R_0805_2012Metric
R2, R7: 2.2k; R_0805_2012Metric
R3: 100; R_0805_2012Metric
R4, R9, R32, R33: 10; R_0805_2012Metric
R5: 220; R_0805_2012Metric
R6, R15, R35, R36, R37, R38: 1k; R_0805_2012Metric
R8: 470; R_0805_2012Metric
R10, R14, R16, R18, R20, R22, R24, R26, R28, R30: 51k; R_0805_2012Metric
R12: 47; R_0805_2012Metric
R13: 51; R_0805_2012Metric
R34: 51*; R_Axial_DIN0207_L6.3mm_D2.5mm_P10.16mm_Horizontal
RV1, RV2: 10k; Potentiometer_ACP_CA6-H2,5_Horizontal
RV3: 4.7k; Potentiometer_ACP_CA6-H2,5_Horizontal
T1, T2: 2/2+2; tr_05_v
U1: PCF8574AT; SOIC-16W_7.5x10.3mm_P1.27mm

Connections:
3.5: R17.2, U1.4 (P0)
7.0: R31.2, U1.5 (P1)
10.5: R19.2, U1.6 (P2)
14: R29.2, U1.7 (P3)
18: R21.2, U1.9 (P4)
21: R27.2, U1.10 (P5)
24: R23.2, U1.11 (P6)
28: R25.2, U1.12 (P7)
+3.3V: J1.11, J1.12
+5V: C12.1, C53.2, C54.1, C55.2, J1.13, J1.14, K1.1, K2.1, K3.1, K4.1, K5.1, K6.1, K7.1, K8.1, K9.1, K10.1, U1.16 (VDD)
+12V: C66.1, J1.15, J1.16, K10.4
Cwk: D1.2 (A), J1.3, J1.4
GND: C2.1, C4.1, C5.1, C6.1, C7.1, C10.1, C11.1, C12.2, C13.1, C14.1, C15.1, C16.1, C17.1, C21.1, C23.1, C24.1, C25.1, C26.1, C27.1, C28.1, C29.1, C30.1, C35.1, C36.1, C37.2, C38.1, C39.1, C40.1, C41.1, C42.1, C43.1, C48.1, C49.1, C50.1, C51.1, C52.1, C53.1, C54.2, C55.1, C59.2, C60.2, C61.1, C62.1, C63.2, C66.2, D3.2 (A), H1.1, H2.1, H3.1, H4.1, J1.1, J1.2, J1.17, J1.18, J2.2 (Ext), J7.2 (Ext), J8.2 (Ext), L1.2, L3.2, L4.2, L6.2, L7.2, L8.2, L11.2, L12.2, L13.2, L14.2, L17.2, L18.2, L19.2, L20.2, L23.2, L24.2, Q3.2 (E), Q5.2 (E), Q7.2 (E), Q8.2 (E), Q9.2 (E), Q10.2 (E), Q11.2 (E), Q13.2 (E), Q14.2 (E), Q15.2 (E), R3.1, R6.1, R7.1, R8.1, R10.1, R13.1, R14.1, R16.1, R18.1, R20.1, R22.1, R24.1, R26.1, R28.1, R30.1, R32.1, R33.1, R34.1, RV3.1, T1.2 (AB), T2.1 (AA), U1.1 (A0), U1.2 (A1), U1.3 (A2), U1.8 (GND)
Inp: J3.1, K2.4, K3.4, K4.4, K5.4, K6.4, K7.4, K8.4, K9.4, K10.10, R34.2, T2.2 (AB)
unnamed: C1.1, C2.2, C3.1, C5.2, K3.8, L3.1
unnamed: C1.2, C3.2, L2.2
unnamed: C6.2, C7.2, K2.5, L4.1, L5.1
unnamed: C8.2, C9.2, L5.2
unnamed: C8.1, C9.1, C10.2, C11.2, K2.8, L6.1
unnamed: C13.2, R4.1
unnamed: C14.2, C16.2, K4.5, L7.1, L9.1
unnamed: C15.2, C17.2, K5.5, L8.1, L10.1
unnamed: C18.1, C19.1, C23.2, C25.2, K4.8, L11.1
unnamed: C18.2, C19.2, L9.2
unnamed: C20.1, C22.1, C24.2, C26.2, K5.8, L12.1
unnamed: C20.2, C22.2, L10.2
unnamed: C4.2, C21.2, K3.5, L1.1, L2.1
unnamed: C27.2, C29.2, K6.5, L13.1, L15.1
unnamed: C28.2, C30.2, K7.5, L14.1, L16.1
unnamed: C31.1, C32.1, C35.2, C38.2, K6.8, L17.1
unnamed: C31.2, C32.2, L15.2
unnamed: C33.1, C34.1, C36.2, C39.2, K7.8, L18.1
unnamed: C33.2, C34.2, L16.2
unnamed: C40.2, C42.2, K8.5, L19.1, L21.1
unnamed: C41.2, C43.2, K9.5, L20.1, L22.1
unnamed: C44.1, C45.1, C48.2, C50.2, K8.8, L23.1
unnamed: C44.2, C45.2, L21.2
unnamed: C46.1, C47.1, C49.2, C51.2, K9.8, L24.1
unnamed: C46.2, C47.2, L22.2
unnamed: C56.2, K10.8, R13.2
unnamed: C58.1, R12.1
unnamed: C64.2, R35.1
unnamed: C65.2, R36.1
unnamed: D1.1 (K), R11.2
unnamed: D2.1 (K), R1.2
unnamed: C61.2, D3.1 (K), R37.1, RV3.3
unnamed: J2.1 (In), K1.5, K1.8
unnamed: J3.2, R12.2, T1.1 (AA)
unnamed: J7.1 (In), K1.3, K1.10
unnamed: J8.1 (In), K10.9
unnamed: C56.1, Q1.1 (B), R2.1, R6.2
unnamed: Q1.3 (C), Q2.1 (B), R2.2, R5.1
unnamed: Q1.2 (E), R3.2, R4.2
unnamed: C37.1, Q2.3 (C), Q4.3 (C), R5.2, R9.1
unnamed: Q2.2 (E), Q4.1 (B), R7.2
unnamed: C52.2, Q3.1 (B), R1.1, R14.2
unnamed: C58.2, Q4.2 (E), R8.2
unnamed: Q5.1 (B), R10.2, R11.1
unnamed: Q5.3 (C), R15.1
unnamed: C57.1, Q6.1 (B), R38.1, RV2.1, RV2.2
unnamed: C63.1, K10.5, Q6.3 (C), RV1.1, T2.4 (SC)
unnamed: C57.2, Q6.2 (E), R9.2, R37.2
unnamed: Q7.1 (B), R18.2, R19.1
unnamed: K5.12, Q7.3 (C)
unnamed: Q8.1 (B), R26.2, R27.1
unnamed: K6.12, Q8.3 (C)
unnamed: Q9.1 (B), R20.2, R21.1
unnamed: K7.12, Q9.3 (C)
unnamed: Q10.1 (B), R22.2, R23.1
unnamed: K9.12, Q10.3 (C)
unnamed: Q11.1 (B), R24.2, R25.1
unnamed: K8.12, Q11.3 (C)
unnamed: C65.1, Q12.1 (D), T2.3 (SA)
unnamed: Q12.2 (G), R36.2, T1.5 (SB)
unnamed: C59.1, Q12.3 (S), R32.2
unnamed: Q13.1 (B), R16.2, R17.1
unnamed: K3.12, Q13.3 (C)
unnamed: Q14.1 (B), R30.2, R31.1
unnamed: K2.12, Q14.3 (C)
unnamed: Q15.1 (B), R28.2, R29.1
unnamed: K4.12, Q15.3 (C)
unnamed: C64.1, Q16.1 (D), T2.5 (SB)
unnamed: Q16.2 (G), R35.2, T1.3 (SA)
unnamed: C60.1, Q16.3 (S), R33.2
unnamed: R15.2, RV2.3
unnamed: R38.2, RV1.2, RV1.3
unnamed: C62.2, RV3.2, T1.4 (SC)
Out: K1.4, K1.9, K2.9, K3.9, K4.9, K5.9, K6.9, K7.9, K8.9, K9.9
Rel: K1.12, K10.12, Q3.3 (C)
Rx/Tx: D2.2 (A), J1.5, J1.6
Scl: J1.7, J1.8, U1.14 (SCL)
Sda: J1.9, J1.10, U1.15 (SDA)

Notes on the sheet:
Forw
BPF 9.4 - 10.8MHz
BPF 16.9 - 19.4MHz
BPF 19.8 - 22.7MHz
Addr 32
BPF 23.2 - 26.7MHz
BPF 26.9 - 30.8MHz
BPF 6.6 - 7.6MHz
BPF 13.2 - 15.15MHz
Back
BPF 3.4-3.9MHz

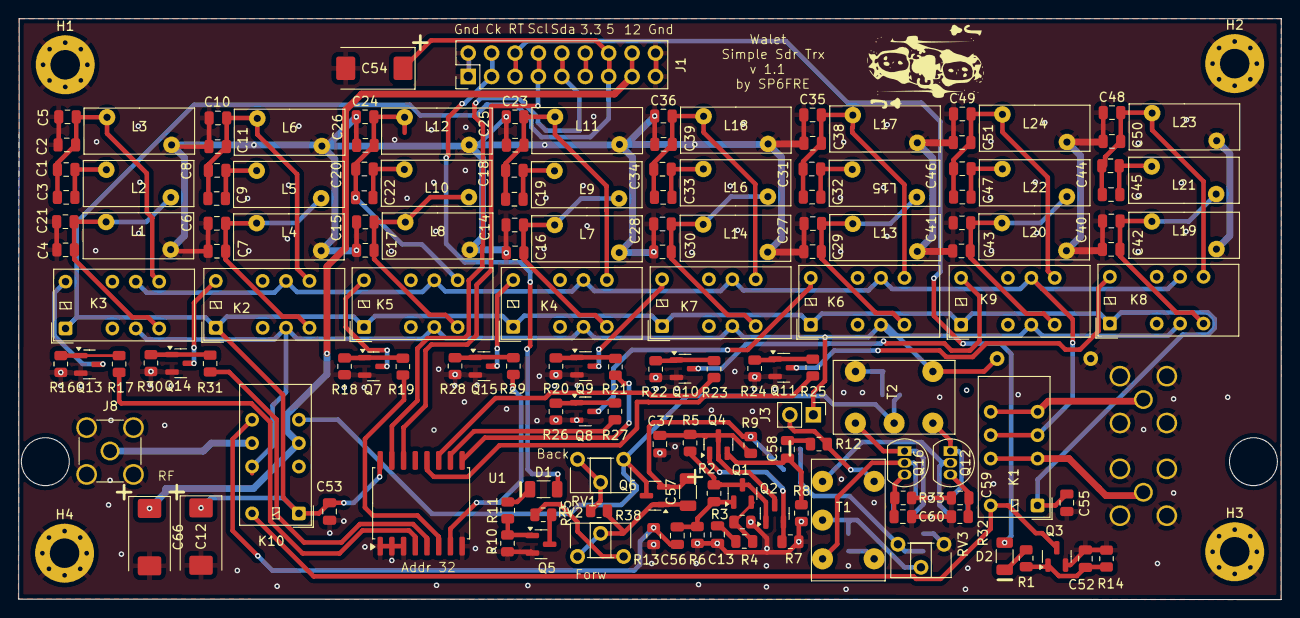
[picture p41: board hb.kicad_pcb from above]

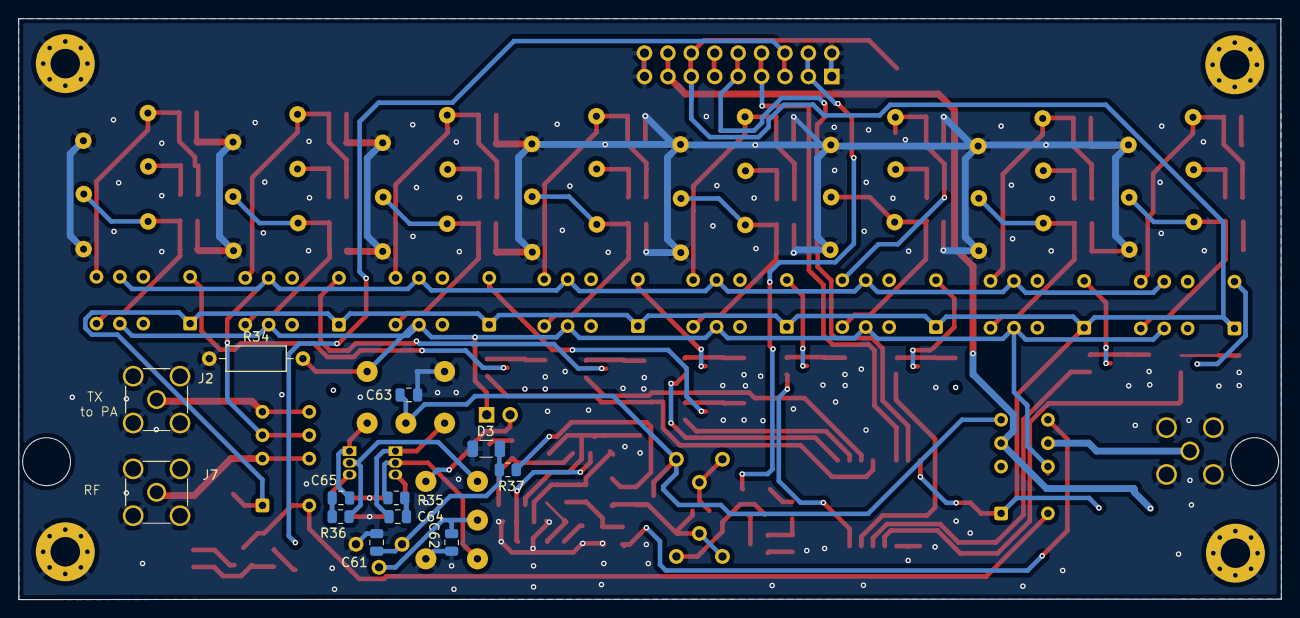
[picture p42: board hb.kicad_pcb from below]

Board: 2 copper layers, 137.0 x 63.0 mm, 172 parts (12 on the bottom side), 92 nets.

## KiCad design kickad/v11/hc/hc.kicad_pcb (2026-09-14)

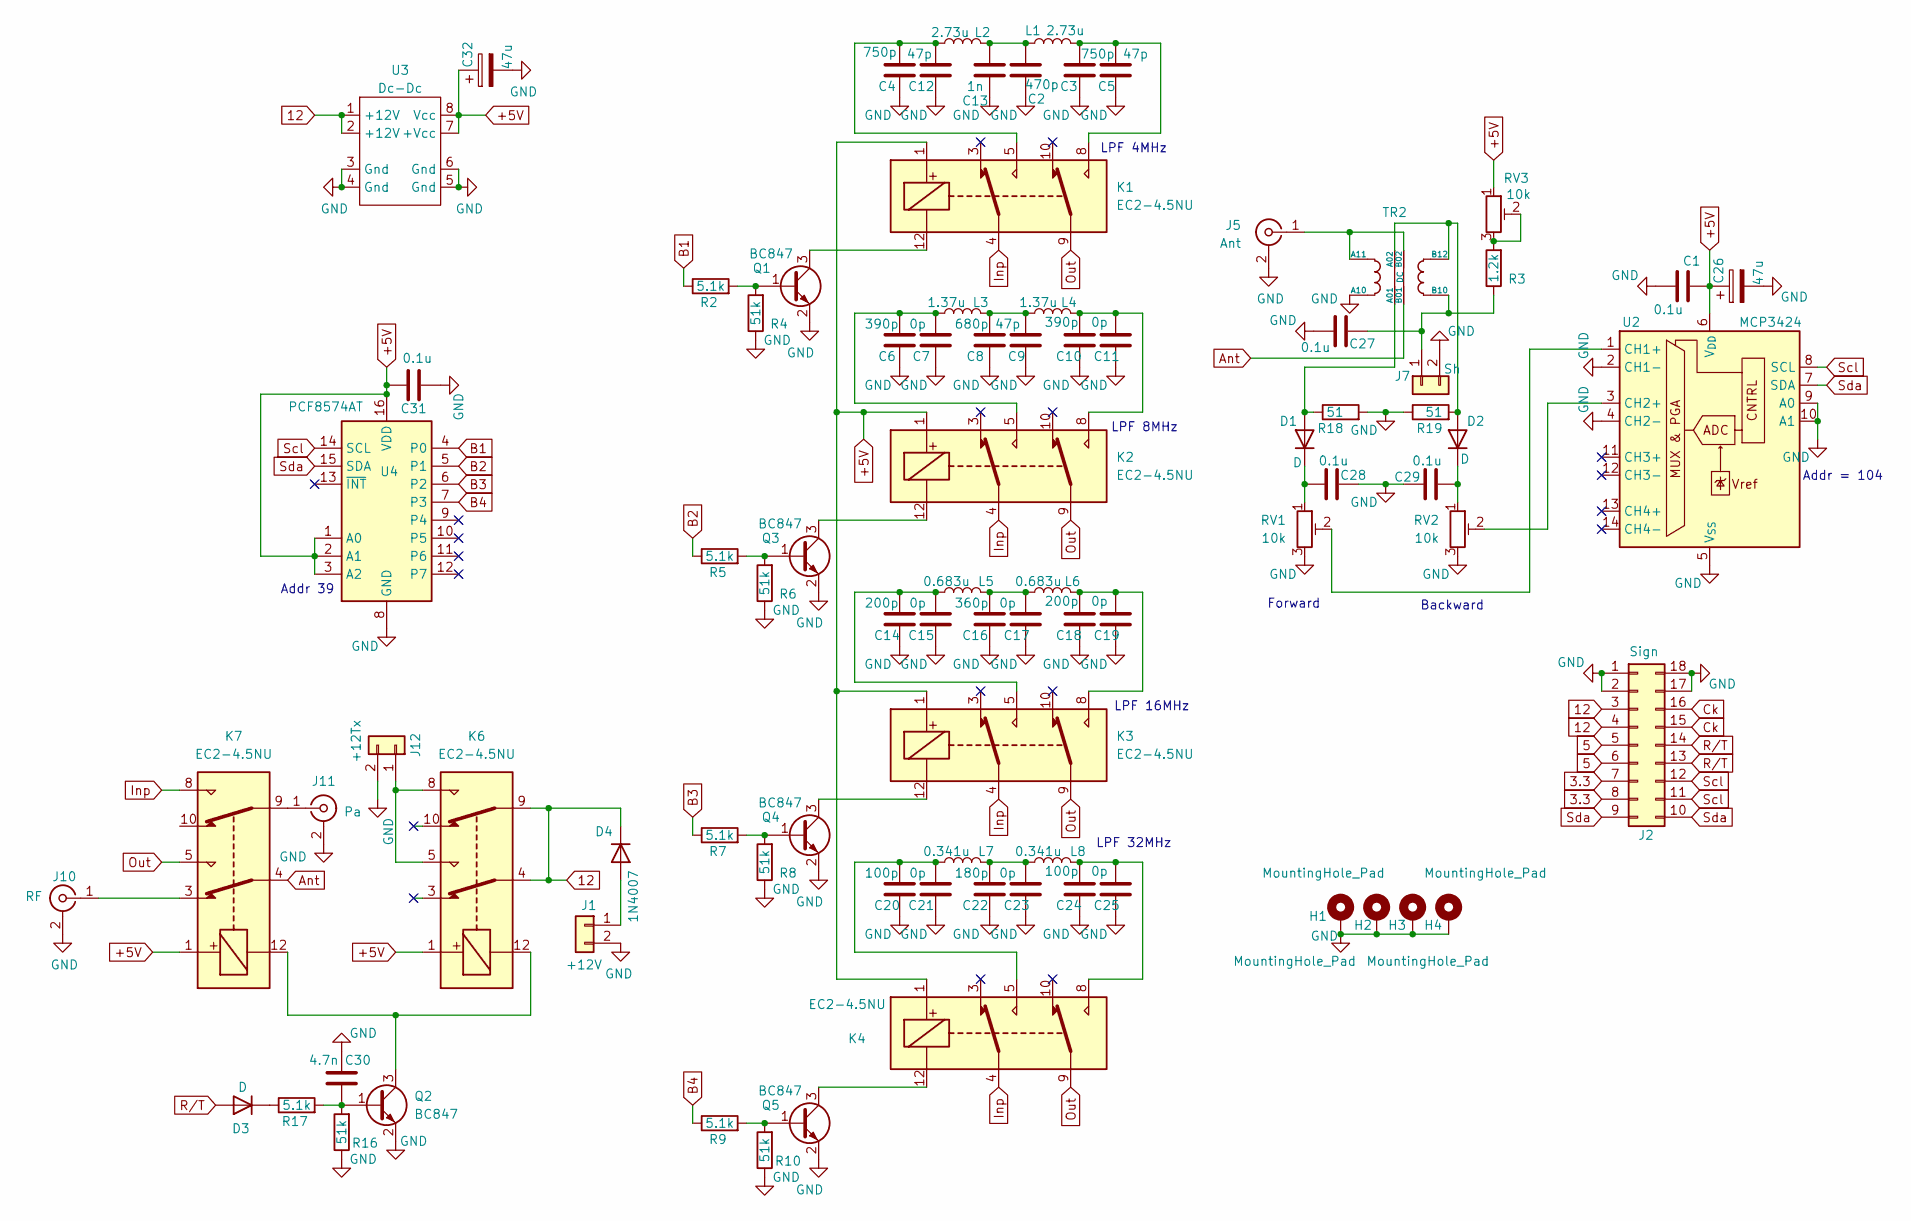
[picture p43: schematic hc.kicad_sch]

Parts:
C1, C27, C28, C29, C31: 0.1u; C_0805_2012Metric
C2: 470p; C_1206_3216Metric
C3, C4: 750p; C_1206_3216Metric
C5, C9, C12: 47p; C_1206_3216Metric
C6, C10: 390p; C_1206_3216Metric
C7, C11, C15, C17, C19, C21, C23, C25: 0p; C_1206_3216Metric
C8: 680p; C_1206_3216Metric
C13: 1n; C_1206_3216Metric
C14, C18: 200p; C_1206_3216Metric
C16: 360p; C_1206_3216Metric
C20, C24: 100p; C_1206_3216Metric
C22: 180p; C_1206_3216Metric
C26, C32: 47u; CP_EIA-3528-21_Kemet-B
C30: 4.7n; C_0805_2012Metric
D1, D2, D3: D; D_1206_3216Metric
D4: 1N4007; D_1206_3216Metric
H1, H2, H3, H4: MountingHole_Pad; MountingHole_3.2mm_M3_Pad_Via
J1: +12V; power_con
J2: Sign; PinHeader_2x09_P2.54mm_Vertical
J5: Ant; SMA_Amphenol_901-144_Vertical
J7: Sh; PinHeader_1x02_P2.54mm_Vertical
J10: RF; SMA_Amphenol_901-144_Vertical
J11: Pa; SMA_Amphenol_901-144_Vertical
J12: +12Tx; power_con
K1, K2, K3, K4, K6, K7: EC2-4.5NU; Relay_DPDT_Kemet_EC2_NU
L1, L2: 2.73u; l_01
L3, L4: 1.37u; l_01
L5, L6: 0.683u; l_01
L7, L8: 0.341u; l_01
Q1, Q2, Q3, Q4, Q5: BC847; SOT-23
R2, R5, R7, R9, R17: 5.1k; R_0805_2012Metric
R3: 1.2k; R_0805_2012Metric
R4, R6, R8, R10, R16: 51k; R_0805_2012Metric
R18, R19: 51; R_Axial_DIN0309_L9.0mm_D3.2mm_P12.70mm_Horizontal
RV1, RV2, RV3: 10k; Potentiometer_ACP_CA6-H2,5_Horizontal
TR2: DC; dircoupler
U2: MCP3424; SOIC-14_3.9x8.7mm_P1.27mm
U3: Dc-Dc; dc-dc
U4: PCF8574AT; SOIC-16W_7.5x10.3mm_P1.27mm

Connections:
3.3: J2.7, J2.8
5: J2.5, J2.6
12: D4.1 (K), J2.3, J2.4, K6.4, K6.9, U3.1 (+12V), U3.2 (+12V)
+5V: C1.2, C26.1, C31.1, C32.1, K1.1, K2.1, K3.1, K4.1, K6.1, K7.1, RV3.1, U2.6 (V_{DD}), U3.7 (+Vcc), U3.8 (Vcc), U4.1 (A0), U4.2 (A1), U4.3 (A2), U4.16 (VDD)
Ant: K7.4, TR2.3 (B01)
B1: R2.1, U4.4 (P0)
B2: R5.1, U4.5 (P1)
B3: R7.1, U4.6 (P2)
B4: R9.1, U4.7 (P3)
Ck: J2.15, J2.16
GND: C1.1, C2.1, C3.1, C4.1, C5.1, C6.1, C7.1, C8.1, C9.1, C10.1, C11.1, C12.1, C13.1, C14.1, C15.1, C16.1, C17.1, C18.1, C19.1, C20.1, C21.1, C22.1, C23.1, C24.1, C25.1, C26.2, C27.1, C28.1, C29.2, C30.1, C31.2, C32.2, H1.1, H2.1, H3.1, H4.1, J1.2, J2.1, J2.2, J2.17, J2.18, J5.2 (Ext), J7.2, J10.2 (Ext), J11.2 (Ext), J12.2, Q1.2 (E), Q2.2 (E), Q3.2 (E), Q4.2 (E), Q5.2 (E), R4.1, R6.1, R8.1, R10.1, R16.1, R18.2, R19.1, RV1.3, RV2.3, TR2.5 (A10), U2.2 (CH1-), U2.4 (CH2-), U2.5 (V_{SS}), U2.9 (A0), U2.10 (A1), U3.3 (Gnd), U3.4 (Gnd), U3.5 (Gnd), U3.6 (Gnd), U4.8 (GND)
Inp: K1.4, K2.4, K3.4, K4.4, K7.8
unnamed: C3.2, C5.2, K1.8, L1.2
unnamed: C6.2, C7.2, K2.5, L3.1
unnamed: C8.2, C9.2, L3.2, L4.1
unnamed: C10.2, C11.2, K2.8, L4.2
unnamed: C4.2, C12.2, K1.5, L2.1
unnamed: C2.2, C13.2, L1.1, L2.2
unnamed: C14.2, C15.2, K3.5, L5.1
unnamed: C16.2, C17.2, L5.2, L6.1
unnamed: C18.2, C19.2, K3.8, L6.2
unnamed: C20.2, C21.2, K4.5, L7.1
unnamed: C22.2, C23.2, L7.2, L8.1
unnamed: C24.2, C25.2, K4.8, L8.2
unnamed: D1.2 (A), R18.1, TR2.1 (A01)
unnamed: C28.2, D1.1 (K), RV1.1
unnamed: D2.2 (A), R19.2, TR2.2 (A02), TR2.8 (B12)
unnamed: C29.1, D2.1 (K), RV2.1
unnamed: D3.1 (K), R17.1
unnamed: D4.2 (A), J1.1
unnamed: J5.1 (In), TR2.4 (B02), TR2.6 (A11)
unnamed: C27.2, J7.1, R3.1, TR2.7 (B10)
unnamed: J10.1 (In), K7.3
unnamed: J11.1 (In), K7.9
unnamed: J12.1, K6.5, K6.8
unnamed: Q1.1 (B), R2.2, R4.2
unnamed: K1.12, Q1.3 (C)
unnamed: C30.2, Q2.1 (B), R16.2, R17.2
unnamed: K6.12, K7.12, Q2.3 (C)
unnamed: Q3.1 (B), R5.2, R6.2
unnamed: K2.12, Q3.3 (C)
unnamed: Q4.1 (B), R7.2, R8.2
unnamed: K3.12, Q4.3 (C)
unnamed: Q5.1 (B), R9.2, R10.2
unnamed: K4.12, Q5.3 (C)
unnamed: R3.2, RV3.2, RV3.3
unnamed: RV1.2, U2.1 (CH1+)
unnamed: RV2.2, U2.3 (CH2+)
Out: K1.9, K2.9, K3.9, K4.9, K7.5
R/T: D3.2 (A), J2.13, J2.14
Scl: J2.11, J2.12, U2.8 (SCL), U4.14 (SCL)
Sda: J2.9, J2.10, U2.7 (SDA), U4.15 (SDA)

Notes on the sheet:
LPF 8MHz
Addr = 104
Addr 39
LPF 16MHz
LPF 32MHz
Backward
LPF 4MHz
Forward

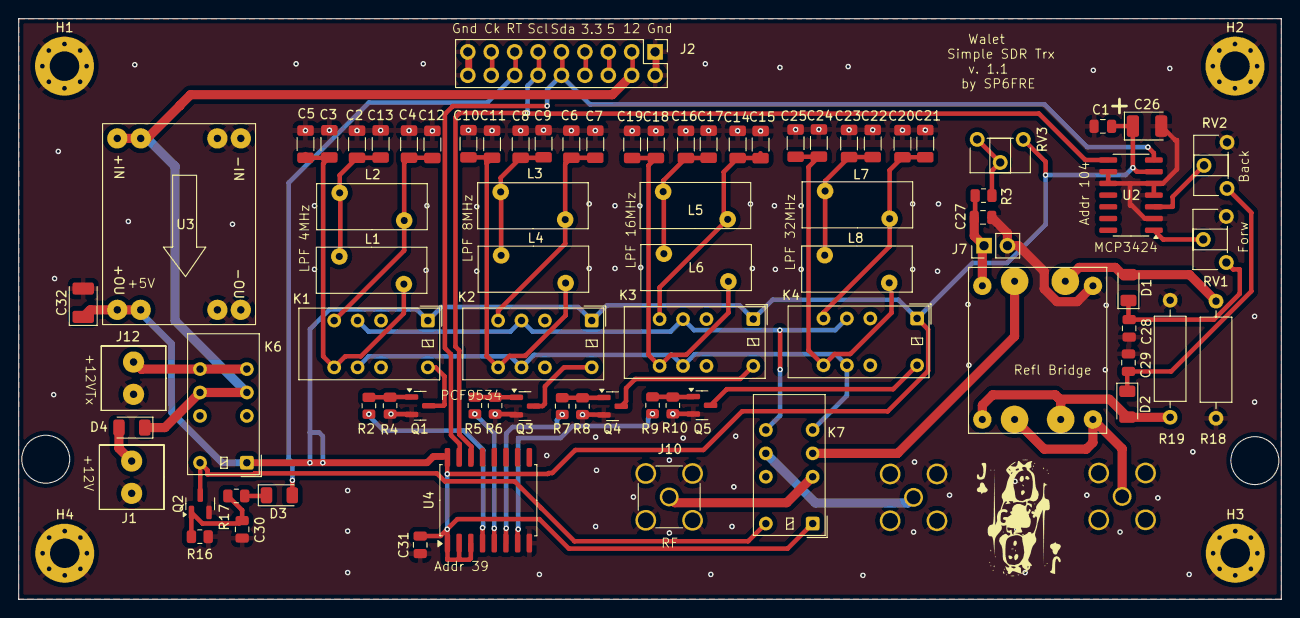
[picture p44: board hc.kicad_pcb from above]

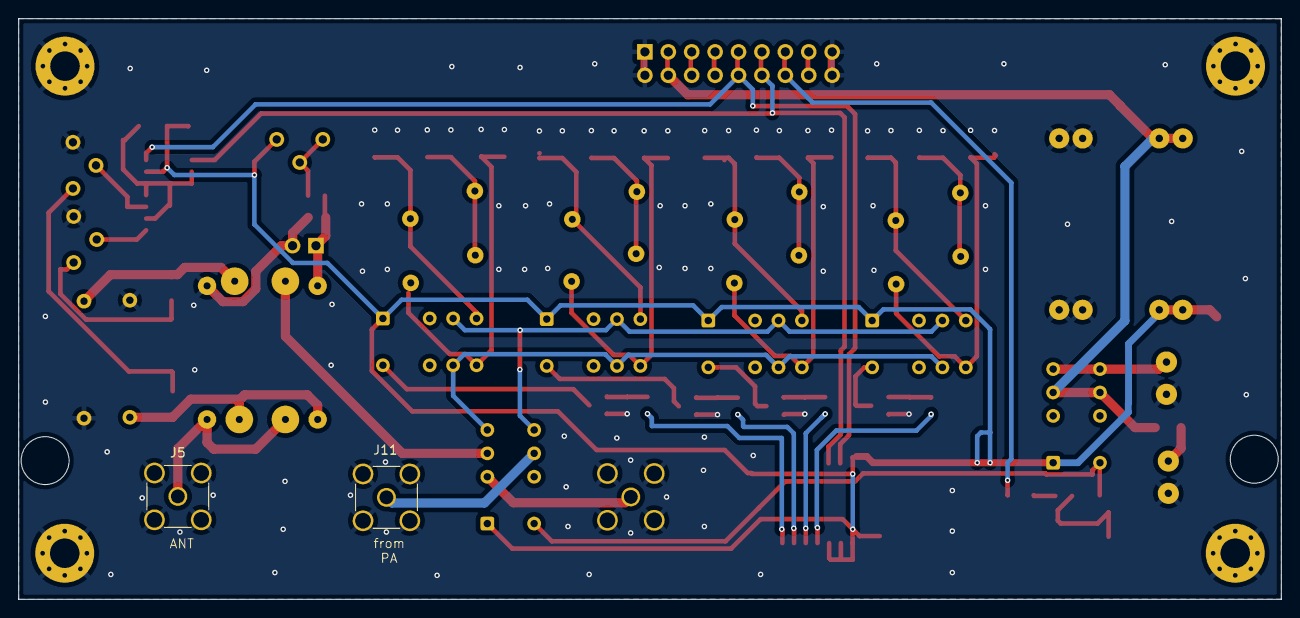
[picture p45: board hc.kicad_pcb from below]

Board: 2 copper layers, 137.0 x 63.0 mm, 86 parts (2 on the bottom side), 52 nets.

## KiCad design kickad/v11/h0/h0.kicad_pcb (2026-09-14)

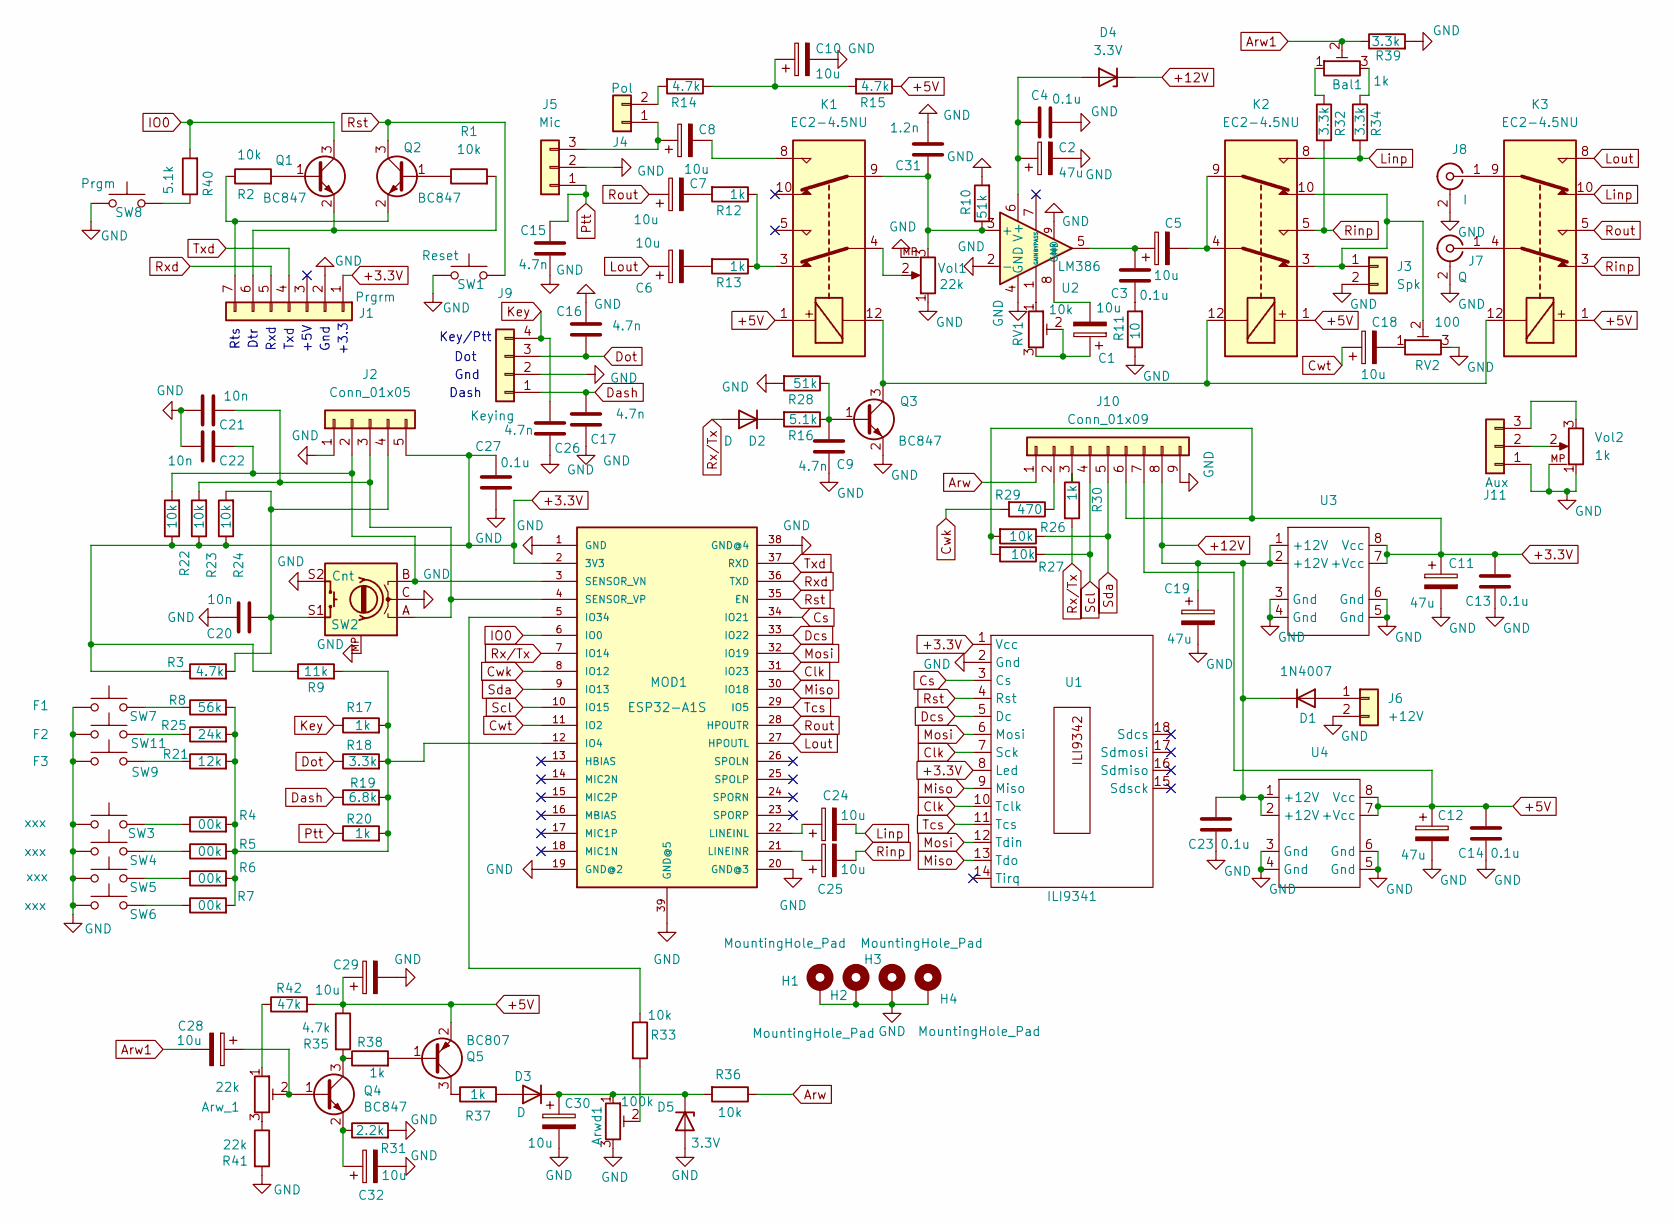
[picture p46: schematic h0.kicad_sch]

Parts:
Arw_1: 22k; Potentiometer_ACP_CA6-H2,5_Horizontal
Arwd1: 100k; Potentiometer_ACP_CA6-H2,5_Horizontal
Bal1: 1k; Potentiometer_ACP_CA6-H2,5_Horizontal
C1, C5, C6, C7, C8, C10, C18, C24, C25, C28, C29, C32: 10u; C_1206_3216Metric
C2, C11, C12, C19: 47u; CP_EIA-7343-31_Kemet-D
C3, C4, C13, C14, C23, C27: 0.1u; C_0805_2012Metric
C9, C15, C16, C17, C26: 4.7n; C_0805_2012Metric
C20, C21, C22: 10n; C_0805_2012Metric
C30: 10u; CP_EIA-7343-31_Kemet-D
C31: 1.2n; C_0805_2012Metric
D1: 1N4007; D_2114_3652Metric
D2, D3: D; C_1206_3216Metric
D4: 3.3V; D_DO-34_SOD68_P10.16mm_Horizontal
D5: 3.3V; C_1206_3216Metric
H1, H2, H3, H4: MountingHole_Pad; MountingHole_3.2mm_M3_Pad_Via
J1: Prgrm; PinHeader_1x07_P2.54mm_Vertical
J2: Conn_01x05; PinHeader_1x05_P2.54mm_Vertical
J3: Spk; power_con
J4: Pol; PinHeader_1x02_P2.54mm_Vertical
J5: Mic; PinHeader_1x03_P2.54mm_Vertical
J6: +12V; power_con
J7: Q; SMA_Amphenol_901-144_Vertical
J8: I; SMA_Amphenol_901-144_Vertical
J9: Keying; PinHeader_1x04_P2.54mm_Vertical
J10: Conn_01x09; PinHeader_1x09_P2.54mm_Vertical
J11: Aux; PinHeader_1x03_P2.54mm_Vertical
K1, K2, K3: EC2-4.5NU; Relay_DPDT_Kemet_EC2_NJ
MOD1: ESP32-A1S
Q1, Q2, Q3, Q4: BC847; SOT-23
Q5: BC807; SOT-23
R1, R2, R22, R23, R24, R26, R27, R33, R36: 10k; R_0805_2012Metric
R3, R14, R15, R35: 4.7k; R_0805_2012Metric
R4, R5, R6, R7: 00k; R_0805_2012Metric
R8: 56k; R_0805_2012Metric
R9: 11k; R_0805_2012Metric
R10, R28: 51k; R_0805_2012Metric
R11: 10; R_0805_2012Metric
R12, R13, R17, R20, R30, R37, R38: 1k; R_0805_2012Metric
R16, R40: 5.1k; R_0805_2012Metric
R18, R32, R34, R39: 3.3k; R_0805_2012Metric
R19: 6.8k; R_0805_2012Metric
R21: 12k; R_0805_2012Metric
R25: 24k; R_0805_2012Metric
R29: 470; R_0805_2012Metric
R31: 2.2k; R_0805_2012Metric
R41: 22k; R_0805_2012Metric
R42: 47k; R_0805_2012Metric
RV1: 10k; Potentiometer_ACP_CA6-H2,5_Horizontal
RV2: 100; Potentiometer_ACP_CA6-H2,5_Horizontal
SW1: Reset; microswitch
SW2: Cnt; RotaryEncoder_Alps_EC11E-Switch_Vertical_H20mm
SW3, SW4, SW5, SW6: xxx; microswitch
SW7: F1; microswitch
SW8: Prgm; microswitch
SW9: F3; microswitch
SW11: F2; microswitch
U1: ILI9341; ili9342
U2: LM386; Diodes_PSOP-8
U3, U4: dc-dc
Vol1: 22k; Potentiometer_Alpha_RD901F-40-00D_Single_Vertical
Vol2: 1k; Potentiometer_Alpha_RD901F-40-00D_Single_Vertical

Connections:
+3.3V: C11.1, C13.1, C27.1, J1.1, J2.5, J10.6, MOD1.2 (3V3), R3.1, R9.1, R22.1, R23.1, R24.1, R26.2, R27.2, U1.1 (Vcc), U1.8 (Led), U3.7 (+Vcc), U3.8 (Vcc)
+5V: C12.1, C14.1, C29.1, J10.7, K1.1, K2.1, K3.1, Q5.2 (E), R15.1, R35.1, R42.2, U4.7 (+Vcc), U4.8 (Vcc)
+12V: C19.1, C23.1, D1.1 (K), D4.1 (K), J10.8, U3.1 (+12V), U3.2 (+12V), U4.1 (+12V), U4.2 (+12V)
Arw: J10.1, R36.1
Arw1: Bal1.2, C28.2, R39.1
Clk: MOD1.31 (IO23), U1.7 (Sck), U1.10 (Tclk)
Cs: MOD1.34 (IO21), U1.3 (Cs)
Cwk: MOD1.8 (IO12), R29.2
Cwt: C18.1, MOD1.11 (IO2)
Dash: C17.1, J9.1, R19.1
Dcs: MOD1.33 (IO22), U1.5 (Dc)
Dot: C16.2, J9.3, R18.1
GND: Arwd1.3, C2.2, C4.2, C9.1, C10.2, C11.2, C12.2, C13.2, C14.2, C15.2, C16.1, C17.2, C19.2, C20.1, C21.1, C22.1, C23.2, C26.2, C27.2, C29.2, C30.2, C31.2, C32.2, D5.2 (A), H1.1, H2.1, H3.1, H4.1, J1.2, J2.1, J3.2, J5.2, J6.2, J7.2 (Ext), J8.2 (Ext), J9.2, J10.9, J11.1, MOD1.1 (GND), MOD1.19 (GND@2), MOD1.20 (GND@3), MOD1.38 (GND@4), MOD1.39 (GND@5), Q3.2 (E), R10.2, R11.1, R28.2, R31.2, R39.2, R41.2, RV2.3, SW1.1, SW2.C, SW2.MP, SW2.S2, SW3.1, SW4.1, SW5.1, SW6.1, SW7.1, SW8.1, SW9.1, SW11.1, U1.2 (Gnd), U2.2 (-), U2.4 (GND), U2.9 (GND), U3.3 (Gnd), U3.4 (Gnd), U3.5 (Gnd), U3.6 (Gnd), U4.3 (Gnd), U4.4 (Gnd), U4.5 (Gnd), U4.6 (Gnd), Vol1.1, Vol1.MP, Vol2.1, Vol2.MP
IO0: MOD1.6 (IO0), Q1.3 (C), R40.2
Key: C26.1, J9.4, R17.1
Linp: C24.2, K2.8, K3.10, R34.2
Lout: C6.1, K3.8, MOD1.27 (HPOUTL)
Miso: MOD1.30 (IO18), U1.9 (Miso), U1.13 (Tdo)
Mosi: MOD1.32 (IO19), U1.6 (Mosi), U1.12 (Tdin)
unnamed: Arw_1.1, R42.1
unnamed: Arw_1.3, R41.1
unnamed: Arwd1.2, R33.2
unnamed: Bal1.1, R32.1
unnamed: Bal1.3, R34.1
unnamed: C1.1, RV1.2, RV1.3
unnamed: C1.2, U2.8 (GAIN)
unnamed: C3.1, C5.1, U2.5
unnamed: C3.2, R11.2
unnamed: C5.2, K2.4, K2.9
unnamed: C6.2, R13.2
unnamed: C7.2, R12.2
unnamed: C8.2, K1.8
unnamed: C10.1, R14.1, R15.2
unnamed: C18.2, RV2.1
unnamed: D1.2 (A), J6.1
unnamed: D2.1 (K), R16.2
unnamed: D3.2 (A), R37.2
unnamed: Arwd1.1, C30.1, D3.1 (K), D5.1 (K), R36.2
unnamed: C2.1, C4.1, D4.2 (A), U2.6 (V+)
unnamed: J1.6, Q1.2 (E), R1.2
unnamed: J1.7, Q2.2 (E), R2.1
unnamed: C22.2, J2.2, MOD1.3 (SENSOR_VN), R22.2, SW2.B
unnamed: C21.2, J2.3, MOD1.4 (SENSOR_VP), R23.2, SW2.A
unnamed: C20.2, J2.4, R3.2, R24.2, SW2.S1
unnamed: J3.1, K2.3, K2.10, RV2.2
unnamed: C8.1, J4.1, J5.3
unnamed: J4.2, R14.2
unnamed: J7.1 (In), K3.4
unnamed: J8.1 (In), K3.9
unnamed: J10.2, R29.1
unnamed: J10.3, R30.1
unnamed: J11.2, Vol2.2
unnamed: J11.3, Vol2.3
unnamed: K1.3, R12.1, R13.1
unnamed: K1.4, Vol1.2
unnamed: MOD1.12 (IO4), R4.2, R5.2, R6.2, R7.2, R8.2, R9.2, R17.2, R18.2, R19.2, R20.2, R21.2, R25.2
unnamed: MOD1.5 (IO34), R33.1
unnamed: C24.1, MOD1.22 (LINEINL)
unnamed: C25.1, MOD1.21 (LINEINR)
unnamed: Q1.1 (B), R2.2
unnamed: Q2.1 (B), R1.1
unnamed: C9.2, Q3.1 (B), R16.1, R28.1
unnamed: K1.12, K2.12, K3.12, Q3.3 (C)
unnamed: Arw_1.2, C28.1, Q4.1 (B)
unnamed: Q4.3 (C), R35.2, R38.1
unnamed: C32.1, Q4.2 (E), R31.1
unnamed: Q5.1 (B), R38.2
unnamed: Q5.3 (C), R37.1
unnamed: R4.1, SW3.2
unnamed: R5.1, SW4.2
unnamed: R6.1, SW5.2
unnamed: R7.1, SW6.2
unnamed: R8.1, SW7.2
unnamed: R21.1, SW9.2
unnamed: R25.1, SW11.2
unnamed: R40.1, SW8.2
unnamed: RV1.1, U2.1 (GAIN)
unnamed: C31.1, K1.9, R10.1, U2.3 (+), Vol1.3
Ptt: C15.1, J5.1, R20.1
Rinp: C25.2, K2.5, K3.3, R32.2
Rout: C7.1, K3.5, MOD1.28 (HPOUTR)
Rst: MOD1.35 (EN), Q2.3 (C), SW1.2, U1.4 (Rst)
Rxd: J1.5, MOD1.36 (TXD)
Rx/Tx: D2.2 (A), MOD1.7 (IO14), R30.2
Scl: J10.4, MOD1.10 (IO15), R27.1
Sda: J10.5, MOD1.9 (IO13), R26.1
Tcs: MOD1.29 (IO5), U1.11 (Tcs)
Txd: J1.4, MOD1.37 (RXD)

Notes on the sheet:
Dtr
Key/Ptt
+5V
+3.3
Txd
Gnd
Dot
Rts
Dash
Rxd

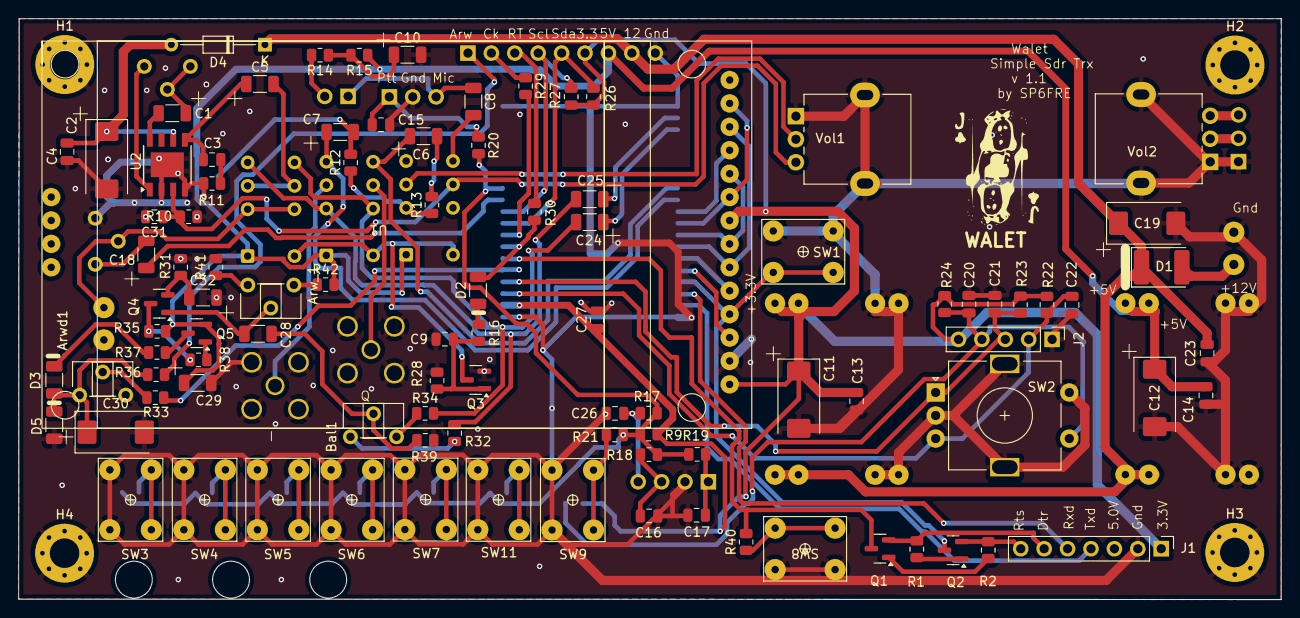
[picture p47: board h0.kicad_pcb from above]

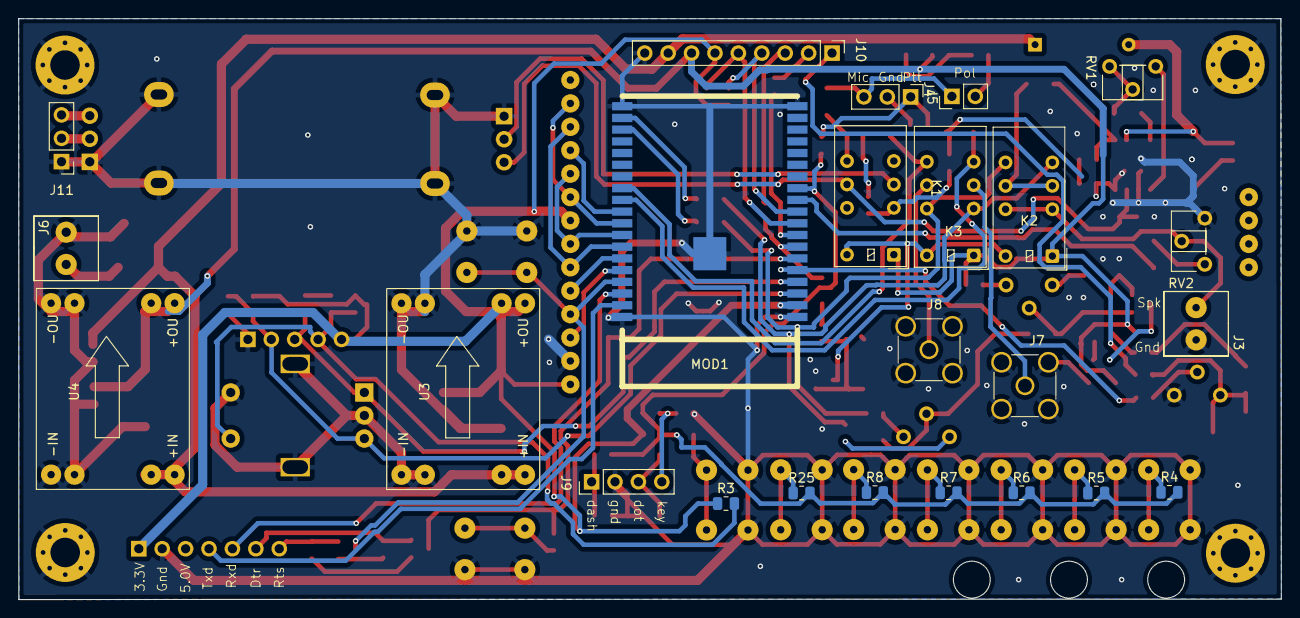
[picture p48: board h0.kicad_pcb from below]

Board: 2 copper layers, 137.0 x 63.0 mm, 125 parts (24 on the bottom side), 88 nets.

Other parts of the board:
WALET: LOGO; walet0

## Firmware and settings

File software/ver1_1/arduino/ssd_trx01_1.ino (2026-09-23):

//I would like to thank these colleagues for their undoubted contribution to the creation of this project:

//Ian A. Langle, NA5Y, for the inspiration regarding the ESP32A1S and Hilbert filters (see his YouTube
//videos, such as https://www.youtube.com/watch?v=D0EUDRo4Mx0 )

//Phil Schatzmann https://github.com/pschatzmann/arduino-audio-tools for I2S support, filtering,
//and likely for future inspiration

//Jasno Mildrum https://github.com/etherkit/si5351arduino for the library EtherKit for si5351

//John M. Wargo https://johnwargo.com/posts/2023/arduino...ple-cores/ for a description of how to use both cores
//of the ESP32 processor

//Matias Hertel https://github.com/mathertel/RotaryEncod...r/examples for handling different encoder modes

//Bodmer https://github.com/Bodmer for the TFT library for esp processors

//Rui Santos https://randomnerdtutorials.com/esp32-tf...1-arduino/ for the practical configuration of the TFT library for ESP
//and the ili9341 display

//Nigel Redmon https://www.earlevel.com/main/2021/09/02...ulator-v3/ for the online biquad filter calculator

//to the software developers at IowaHills (Windows only) https://web.archive.org/web/201711102019...hills.com/ for
// their Hilbert filter calculator (and more)

//Changpuak for amidon core calculator https://www.changpuak.ch/electronics/amidon_toroid_calculator.php


void (*resetFunc)(void) = 0;

//-----------------------------loading required libraries-------------------------------
#include <dummy.h>              //Error Supression Libary
#include "freertos/FreeRTOS.h"  //ESP32 (R.T.O.S) Real Time Operating System
#include "freertos/task.h"      //RTOS Task handler (Controls System Tasks
#include "AudioTools.h"
#include "es8388.h"
#include "FS.h"
#include <SPI.h>
#include <TFT_eSPI.h>  // Hardware-specific library
#include "Wire.h"
#include "si5351.h"
#include <Arduino.h>
#include <RotaryEncoder.h>
#include <EEPROM.h>
//#include "AudioTools/AudioLibs/I2SCodecStream.h"
//#include "AudioTools/AudioLibs/AudioBoardStream.h"
//#include "AudioTools/AudioLibs/AudioKit.h"
//#include "AudioBoard.h"
//#include "AudioTools/CoreAudio/AudioStreams.h"
//#include <WiFi.h>
//#include "AudioTools/AudioLibs/AudioRealFFT.h"
//-----------------------------loading required graphic elements in graph directory-------------------------------
#include ".//graph//g_b.h"
#include ".//graph//g00f.h"
#include ".//graph//g00e.h"
#include ".//graph//g01f.h"
#include ".//graph//g01e.h"
#include ".//graph//g02f.h"
#include ".//graph//g02e.h"
#include ".//graph//g03f.h"
#include ".//graph//g03e.h"
#include ".//graph//g04f.h"
#include ".//graph//g04e.h"
#include ".//graph//g05f.h"
#include ".//graph//g05e.h"
#include ".//graph//g06f.h"
#include ".//graph//g06e.h"
#include ".//graph//g07f.h"
#include ".//graph//g07e.h"
#include ".//graph//g08f.h"
#include ".//graph//g08e.h"
#include ".//graph//g09f.h"
#include ".//graph//g09e.h"
#include ".//graph//g10f.h"
#include ".//graph//g10e.h"
#include ".//graph//g11f.h"
#include ".//graph//g11e.h"
#include ".//graph//g12f.h"
#include ".//graph//g12e.h"
#include ".//graph//g13f.h"
#include ".//graph//g13e.h"
#include ".//graph//g14f.h"
#include ".//graph//g14e.h"
#include ".//graph//g15f.h"
#include ".//graph//g15e.h"
#include ".//graph//save.h"
#include ".//graph//plus.h"
#include ".//graph//minus.h"
#include ".//graph//digit_green.h"
#include ".//graph//digit_gray.h"
#include ".//graph//rect_gray.h"
#include ".//graph//rect_green.h"
#include ".//graph//sq_gray.h"
#include ".//graph//sq_green.h"
#include ".//graph//walet0.h"
#include "hb_24_81.h"  //define hilbert transform
#include ".//graph//en_r.h" //encoder right/left icons in setup
#include ".//graph//en_l.h"

TaskHandle_t Task0;

//-----------------------------define lp and bp filters-------------------------------
const float b_lpf24_36[] = { 0.13109923, 0.26219847, 0.13109923 };  //biquad lpf 24kHz sampling, 3600Hz f max
const float a_lpf24_36[] = { 1.0, -0.74774808, 0.27214502 };

const float b_lpf24_24[] = { 0.06745228, 0.13490457, 0.06745228 };  //biquad lpf 24kHz sampling, 2400Hz f max
const float a_lpf24_24[] = { 1.0, -1.14292982, 0.41273895 };

const float b_bpf24_8_6[] = { 0.01703090, 0.0, -0.01703090 };  //biquad bpf 24kHz sampling, 800Hz central freq
const float a_bpf24_8_6[] = { 1.0, -1.92297774, 0.96593821 };


//-----------------------------some audio definition and basic actions-------------------------------
uint16_t sample_rate = 24000;
uint16_t channels = 2;
uint16_t bits_per_sample = 16;  // or try with 24 or 32
AudioInfo info(sample_rate, channels, bits_per_sample); 
//MultiOutput out;
//AudioRealFFT fft; //or AudioKissFFT
//I2SCodecStream i2s_codec(AudioKitEs8388V2); 
I2SStream i2s;
//I2SCodecStream i2s(AudioKitEs8388V2); 

//VolumeMeter: Observes the signal right before passing it to I2S
///VolumeMeter volumeMeter(i2s); 
//StreamCopy copier(i2s, inFiltered);                        // copies filtered audio to output
//StreamCopy copier(volumeMeter, inFiltered);   

//StreamCopy copier(i2s, i2s); // copies sound into i2s
//FilteredStream<int16_t, float> inFiltered(volumeMeter,channels);  // Defines the filter as BaseConverter
FilteredStream<int16_t, float> inFiltered(i2s, channels);  // Defines the filter as BaseConverter
//VolumeMeter volumeMeter(inFiltered); 
//StreamCopy.copier(inFiltered,volumeMeter);
VolumeMeter volumeMeter(inFiltered);
//StreamCopy copier(i2s, inFiltered);   
StreamCopy copier(i2s, volumeMeter);                        // copies filtered audio to output
//StreamCopy copier(volumeMeter, i2s);  
//StreamCopy copier(out, inFiltered);
//StreamCopy copier(i2s,i2s); 


//-----------------------------Basic TFT and touch screen action-------------------------------
TFT_eSPI tft = TFT_eSPI();  // Invoke custom library
// This is the file name used to store the calibration data
// You can change this to create new calibration files.
// The SPIFFS file name must start with "/".
#define CALIBRATION_FILE "/TouchCalData1"
// Set REPEAT_CAL to true instead of false to run calibration
// again, otherwise it will only be done once.
// Repeat calibration if you change the screen rotation.
#define REPEAT_CAL false


//-----------------------------Some program and ports definitions-------------------------------
#define Freq_X 40  // Centre of key
#define Freq_Y 96
#define Freq_W 62  // Width and height
#define Freq_H 30
#define But_x 284
#define But_y 17
#define But_sp_y 40  // X and Y gap
#define PIN_IN1 36   //Rotary encoder pin definition
#define PIN_IN2 39
#define LOGO_HEIGHT 120
#define LOGO_WIDTH 240
#define RxTx_port 14  //port Rx/TX
#define Cwk_port 12   //port CW keying
#define Cwt_port 2    //CW ton 800Hz
#define Arw 34
#define But2s 4
#define RxTx_led_x 232
#define RxTx_led_y 13
#define Cws_x 224
#define Cws_y 124

//-----------------------------I2C hardware definitions-------------------------------
#define Bpf_addr 0x20  //Bpf addr PCF8574 32d
#define Lpf_addr 0x27  //Lpf addr PCF8574 swtich addr 39d
#define Att_addr 0x23  //RF addr PCF8574 attenuator addr 35d
#define Brg_addr 0x68  //Bridge addr addr MCP3424


//-----------------------------Rotary encoder definition-------------------------------
//RotaryEncoder encoder(PIN_IN1, PIN_IN2, RotaryEncoder::LatchMode::TWO03);
//RotaryEncoder encoder(PIN_IN1, PIN_IN2, RotaryEncoder::LatchMode::FOUR0);
RotaryEncoder *encoder = nullptr;
IRAM_ATTR void checkPosition() {
  encoder->tick();  // just call tick() to check the state.
}
// Setup a RotaryEncoder with 4 steps per latch for the 2 signal input pins:
//RotaryEncoder encoder(PIN_IN1, PIN_IN2, RotaryEncoder::LatchMode::FOUR3);//
// Setup a RotaryEncoder with 2 steps per latch for the 2 signal input pins:
//RotaryEncoder encoder(PIN_IN1, PIN_IN2, RotaryEncoder::LatchMode::TWO03);


//-----------------------------Some grafics settings-------------------------------
#define BigFont &FreeMonoBold18pt7b
#define SmallFont &FreeSans9pt7b




//-----------------------------definitions of program constants and variables-------------------------------
String callsign;
String F1_str;
String F2_str;
uint16_t Bgr_color = TFT_BLACK;
uint16_t Freq_color = TFT_BLUE;
uint16_t But_color = TFT_BLUE;
uint16_t But_text = TFT_YELLOW;
uint16_t But_active = TFT_MAGENTA;
uint16_t But_normal = TFT_GREEN;
TFT_eSPI_Button Freq;
TFT_eSPI_Button CwSsb;
TFT_eSPI_Button UpDn;
TFT_eSPI_Button Rit;
TFT_eSPI_Button Opt1;
TFT_eSPI_Button Opt2;
TFT_eSPI_Button Opt3;
TFT_eSPI_Button Save;
TFT_eSPI_Button Plus;
TFT_eSPI_Button Minus;
TFT_eSPI_Button Call;
TFT_eSPI_Button Corre;
TFT_eSPI_Button Cwdelay;
uint16_t t_x = 0, t_y = 0;  // To store the touch coordinates
bool CwSsb_state = true;
bool UpDn_state = true;
byte Att_value = 0x00;
bool Rit_state = false;
bool Menu_state = false;
bool Option_state = false;
bool Step_state = false;
bool RxTx_state = 0;  //receive/transmit
bool Setup_state = false;
bool isFirst = true;
bool isFilterChanged = true;
bool rxtx_checked = true;
bool swr_pwr = false;  //display swr during transmission
bool forw_state = false;
bool back_state = false;
bool forw_started = false;
bool back_started = false;
bool rit = false;

unsigned long long F1 = 350000000ULL;  //basic freq
unsigned long long F2 = 700000000ULL;  //spare freq
unsigned long long F03 = 350000000ULL;
unsigned long long F07 = 700000000ULL;
unsigned long long F10 = 1010000000ULL;
unsigned long long F14 = 1400000000ULL;
unsigned long long F18 = 1806800000ULL;
unsigned long long F21 = 2100000000ULL;
unsigned long long F24 = 2489000000ULL;
unsigned long long F28 = 2800000000ULL;
unsigned long long Frit;
unsigned long long Ftmp;
unsigned long long Step[] = { 2000ULL, 10000ULL, 100000ULL, 1000000ULL, 10000000ULL, 100000000ULL };
String Step_txt[] = { " 20Hz", "100Hz", " 1kHz", "10kHz", " 100k", " 1MHz" };
signed long long Corr;  // definicja zmiennej korekcji Si5351
unsigned long long pll_freq = 60000000000ULL;
unsigned long long pll_tmp;
unsigned long long pll_div;
int Step_index = 1;
int Filter_index = 0;  //0 - 3600Hz LPF, 1 - 2400Hz LPF, 2 - 800Hz Q=6 BPF
unsigned long delay1 = 250;
unsigned long delay2 = 30;
unsigned long delay3 = 5;    //used for button/function establish
unsigned long delay4 = 350;  // tx/rx blocking
unsigned long delay5 = 333;
signed long TxRx_delay;  // = 500;  //delay when change from Tx to Rx in cw
unsigned long oldMs1 = 0;
unsigned long oldMs2 = 0;
unsigned long oldMs3 = 0;
unsigned long oldMs4 = 0;
unsigned long oldMs5 = 0;
unsigned long curMs1;
unsigned long curMs2;
unsigned long curMs3;
unsigned long curMs4;
unsigned long curMs5;
int Band_index = 0;  // 0-3.5MH, 1-7zMHz, .....7-28MHz
int Band_index_old = Band_index;
String Band_txt[] = { "3.5", "7.0", "10.1", "14.0", "18.0", "21", "24.9", "28.0" };
int El_key_time[] = { 240, 200, 171, 150, 133, 120, 109, 100, 92, 86, 80, 75, 71, 67, 63, 60, 57, 55, 52, 50, 48 };  //21 speeds (dot time [ms]) from 5 to 25 groups/min
int El_key_speed = 9;                                                                                                //El_key_speed initial 14 (9+6) groups/min
int16_t x_of = 2;
int16_t y_of = 2;
int m_digit = 0;
int m_digit_old = m_digit;
int Arw_level = 0;
int Arw_level_old = Arw_level;
int Arw_read_old = 0;
int buttonFirst;
byte Arw_table[52];  //initial arw levels with zero
byte Arw_index = 52;
byte data_s;
byte rot_enc = 0;  //encoder rotation 0-> right, 1-> left
#define Arw_color00 0x7BEF //audio level colors
#define Arw_color01 0x6CEB
#define Arw_color02 0x3EE7
#define Arw_color03 0x07E0
#define Arw_color04 0x2FE0
#define Arw_color05 0x57E0
#define Arw_color06 0x7FE0
#define Arw_color07 0xA760
#define Arw_color08 0xCF60
#define Arw_color09 0xFF70
#define Arw_color10 0xFEA0
#define Arw_color11 0xFD80
#define Arw_color12 0xFC60
#define Arw_color13 0xFB40
#define Arw_color14 0xFA00
#define Arw_color15 0xF800

float forw; //PWR/SWR variable def
float back;
float swr;
float pwr;
int hiByte;
int loByte;
int cfByte;


//S scale: S1-0.2uV,S2-0.4uV,S3-0.8uV,S4-1.6uV,S5-3.2uV,S6-6.3uV,S7-12.6uV,S8-25.1uV
//S9-50.2uV,S9+10-160uV,S9+20-500uV,S9+30-1.5mV,S9+40-5mV,S9+50-15mV,S9+60-50mV

// Define si5351 instance
Si5351 *si5351;
// Define Two I2C channels
TwoWire wire0(0);
TwoWire wire1(1);

String version = "ver 1.1";

//---------------------;---------------------------------------------------------------------
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
void loop(void) {


  if (buttonPressed() > 3) {  //detection Rx or Tx -> Rx mode

    if (rxtx_checked == false) {
      if (millis() - oldMs4 > delay4) {  //delay for blocking tx/rx state
        wire1.beginTransmission(Att_addr);
        //Serial.println(data_s);
        wire1.write(data_s);
        wire1.endTransmission();
        rxtx_checked = true;
      }
    }

    curMs1 = millis();
    curMs2 = curMs1;
    if ((curMs1 - oldMs1) > delay1) {
  //    int amplitude = volumeMeter.volume(); 
  //    Serial.print("Volume_level = ");
  //    Serial.println(amplitude);
      //int Arw_read = (2 * analogRead(Arw) + Arw_read_old) / 3;  //counting arw level as 2/3 current and 1/3 past sum
      int Arw_read = (2 * volumeMeter.volume() + Arw_read_old) / 3;
      Arw_read_old = Arw_read;
      //Serial.println(Arw_read);
      if (Arw_read < 30) { Arw_level = 0; }  //20
      else if (Arw_read >= 30 and Arw_read < 65) {Arw_level = 1; }                                                              //30
      else if (Arw_read >= 65 and Arw_read < 80) {Arw_level = 2; } 
      else if (Arw_read >= 80 and Arw_read < 95) {Arw_level = 3; }                                                              //50
      else if (Arw_read >= 95 and Arw_read < 150) {Arw_level = 4; } 
      else if (Arw_read >= 150 and Arw_read < 260) {Arw_level = 5; }                                                                 //140
      else if (Arw_read >= 260 and Arw_read < 420) {Arw_level = 6; } 
      else if (Arw_read >= 420 and Arw_read < 610) {Arw_level = 7; }                                                                  //1250
      else if (Arw_read >= 610 and Arw_read < 1800) {Arw_level = 8; }  
      else if (Arw_read >= 1800 and Arw_read < 4500) {Arw_level = 9; }                                                                   //2600
      else if (Arw_read >= 4500 and Arw_read < 14000) {Arw_level = 10; } 
      else if (Arw_read >= 14000 and Arw_read < 30000) {Arw_level = 11; } 
      //else if (Arw_read >= 30000 and Arw_read < 2880) {Arw_level = 13; }
      //else if (Arw_read >= 2880 and Arw_read < 3000) { Arw_level = 14; } 
      else if (Arw_read >= 30000) {Arw_level = 15; }
      Meter(Arw_level_old, Arw_level);
      Arw_level_old = Arw_level;
      fftGraph();
      if (Setup_state == false) {
        button_Check();  //checking if right panel button was pressed
      }
      oldMs1 = curMs1;
    }

    if ((curMs2 - oldMs2) > delay2) {
      static int pos = 0;
      encoder->tick();  // just call tick() to check the state.
      int newPos = encoder->getPosition();
      if (pos != newPos) {
        int tmp = pos - newPos;
        if (rot_enc == true){
          tmp = -tmp;
        }
        if (Step_state == true) {
          uint16_t Step_index_old = Step_index;
          tft.setFreeFont(&FreeSans9pt7b);
          tft.setTextDatum(ML_DATUM);
          tft.setTextColor(Bgr_color);
          tft.drawString("Step " + Step_txt[Step_index], 150, 165);
          Step_index = Step_index + tmp;
          if (Step_index > 5) {
            Step_index = 0;
          }
          if (Step_index < 0) {
            Step_index = 5;
          }
          tft.setTextColor(But_active);
          tft.drawString("Step " + Step_txt[Step_index], 150, 165);
          Show_step(F1, Step_index_old, But_text);
          Show_step(F1, Step_index, But_active);
          tft.setFreeFont(SmallFont);
        } else {
          tft.setTextDatum(ML_DATUM);  // Use top left corner as text coord datum
          tft.setFreeFont(BigFont);
          String F1_str_old = Fstring(F1);
          int tmp = pos - newPos;
          if (rot_enc == true){
            tmp = -tmp;
          }
          set_Freq(tmp);
          F1_str = Fstring(F1);
          Fstr_compare(F1_str_old, F1_str);
          RfFiltersSet();  //setting bpf and lpf
        }
      }
      pos = newPos;
    }

  } else {  //detection Rx or Tx -> Tx mode
    static int pos = 0;
    if (CwSsb_state == true) {  //Cw mode
      si5351->output_enable(SI5351_CLK0, 0);
      si5351->output_enable(SI5351_CLK1, 0);
      si5351->output_enable(SI5351_CLK2, 0);

      digitalWrite(RxTx_port, HIGH);  //setting HIGH RxTx and Cwk signals
      digitalWrite(Cwk_port, HIGH);
      tft.fillCircle(RxTx_led_x, RxTx_led_y, 8, TFT_BLACK);  //
      tft.fillCircle(RxTx_led_x, RxTx_led_y, 8, TFT_RED);    //red lamp when TX
      if (UpDn_state == true) {
        if (rit == false) {
          si5351->set_freq_manual(F1 + 80000ULL, pll_tmp, SI5351_CLK2);
        } else {
          si5351->set_freq_manual(Frit + 80000ULL, pll_tmp, SI5351_CLK2);
        }
      } else {
        if (rit == false) {
          si5351->set_freq_manual(F1 - 80000ULL, pll_tmp, SI5351_CLK2);
        } else {
          si5351->set_freq_manual(Frit - 80000ULL, pll_tmp, SI5351_CLK2);
        }
      }
      tft.setFreeFont(SmallFont);  // Choose a nice font that fits box
      tft.setTextDatum(BC_DATUM);
      tft.setTextColor(But_color);
      if (rit == false) {
        tft.drawString("Rof", But_x, But_y + 5 * But_sp_y + 10);
      } else {
        tft.drawString("Ron", But_x, But_y + 5 * But_sp_y + 10);
      }

      tft.setTextColor(But_text);
      if (swr_pwr == false) {
        tft.drawString("Pwr", But_x, But_y + 5 * But_sp_y + 10);
      } else {
        tft.drawString("Swr", But_x, But_y + 5 * But_sp_y + 10);
      }

      oldMs1 = millis();
      while ((millis() - oldMs1) < TxRx_delay) {  //checking if still Tx mode
        static int pos = 0;
        if ((forw_started == false) && (forw_state == false)) {
          wire1.beginTransmission(Brg_addr);
          wire1.write(128);
          wire1.endTransmission();
          forw_started = true;
          oldMs3 = millis();
        }
        if ((forw_started == true) && (((millis() - oldMs3) >= 5))) {
          wire1.requestFrom(Brg_addr, 3);
          hiByte = wire1.read();
          loByte = wire1.read();
          cfByte = wire1.read();
          wire1.endTransmission();
          forw = (hiByte << 8) + loByte;
          forw_state = true;
          forw_started = false;
          wire1.beginTransmission(Brg_addr);
          wire1.write(160);
          wire1.endTransmission();
          back_started = true;
          oldMs3 = millis();
        }
        if ((back_started == true) && (((millis() - oldMs3) >= 5))) {
          wire1.requestFrom(Brg_addr, 3);
          hiByte = wire1.read();
          loByte = wire1.read();
          cfByte = wire1.read();
          wire1.endTransmission();
          back = (hiByte << 8) + loByte;
          back_state = true;
        }
        
        bool pressed = tft.getTouch(&t_x, &t_y);
        if (pressed) {
          tft.setFreeFont(SmallFont);  // Choose a nice font that fits box
          tft.setTextDatum(BC_DATUM);
          tft.setFreeFont(SmallFont);  // Choose a nice font that fits box
          if ((t_y >= (But_y + 4 * But_sp_y + 20) && t_y <= (But_y + 5 * But_sp_y + 15)) && (t_x >= 250 && t_x <= 319)) {
            if (swr_pwr == false) {
              swr_pwr = true;
              tft.setTextColor(But_color);
              tft.drawString("Pwr", But_x, But_y + 5 * But_sp_y + 10);
              tft.setTextColor(But_text);
              tft.drawString("Swr", But_x, But_y + 5 * But_sp_y + 10);
            } else {
              swr_pwr = false;
              tft.setTextColor(But_color);
              tft.drawString("Swr", But_x, But_y + 5 * But_sp_y + 10);
              tft.setTextColor(But_text);
              tft.drawString("Pwr", But_x, But_y + 5 * But_sp_y + 10);
            }
            delay(250);
          }
        }
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

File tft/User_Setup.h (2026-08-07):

//                            USER DEFINED SETTINGS
//   Set driver type, fonts to be loaded, pins used and SPI control method etc.
//
//   See the User_Setup_Select.h file if you wish to be able to define multiple
//   setups and then easily select which setup file is used by the compiler.
//
//   If this file is edited correctly then all the library example sketches should
//   run without the need to make any more changes for a particular hardware setup!
//   Note that some sketches are designed for a particular TFT pixel width/height

// User defined information reported by "Read_User_Setup" test & diagnostics example
#define USER_SETUP_INFO "User_Setup"

// Define to disable all #warnings in library (can be put in User_Setup_Select.h)
//#define DISABLE_ALL_LIBRARY_WARNINGS

// ##################################################################################
//
// Section 1. Call up the right driver file and any options for it
//
// ##################################################################################

// Define STM32 to invoke optimised processor support (only for STM32)
//#define STM32

// Defining the STM32 board allows the library to optimise the performance
// for UNO compatible "MCUfriend" style shields
//#define NUCLEO_64_TFT
//#define NUCLEO_144_TFT

// STM32 8-bit parallel only:
// If STN32 Port A or B pins 0-7 are used for 8-bit parallel data bus bits 0-7
// then this will improve rendering performance by a factor of ~8x
//#define STM_PORTA_DATA_BUS
//#define STM_PORTB_DATA_BUS

// Tell the library to use parallel mode (otherwise SPI is assumed)
//#define TFT_PARALLEL_8_BIT
//#defined TFT_PARALLEL_16_BIT // **** 16-bit parallel ONLY for RP2040 processor ****

// Display type -  only define if RPi display
//#define RPI_DISPLAY_TYPE // 20MHz maximum SPI

// Only define one driver, the other ones must be commented out
#define ILI9341_DRIVER       // Generic driver for common displays
//#define ILI9341_2_DRIVER     // Alternative ILI9341 driver, see https://github.com/Bodmer/TFT_eSPI/issues/1172
//#define ST7735_DRIVER      // Define additional parameters below for this display
//#define ILI9163_DRIVER     // Define additional parameters below for this display
//#define S6D02A1_DRIVER
//#define RPI_ILI9486_DRIVER // 20MHz maximum SPI
//#define HX8357D_DRIVER
//#define ILI9481_DRIVER
//#define ILI9486_DRIVER
//#define ILI9488_DRIVER     // WARNING: Do not connect ILI9488 display SDO to MISO if other devices share the SPI bus (TFT SDO does NOT tristate when CS is high)
//#define ST7789_DRIVER      // Full configuration option, define additional parameters below for this display
//#define ST7789_2_DRIVER    // Minimal configuration option, define additional parameters below for this display
//#define R61581_DRIVER
//#define RM68140_DRIVER
//#define ST7796_DRIVER
//#define SSD1351_DRIVER
//#define SSD1963_480_DRIVER
//#define SSD1963_800_DRIVER
//#define SSD1963_800ALT_DRIVER
//#define ILI9225_DRIVER
//#define GC9A01_DRIVER

// Some displays support SPI reads via the MISO pin, other displays have a single
// bi-directional SDA pin and the library will try to read this via the MOSI line.
// To use the SDA line for reading data from the TFT uncomment the following line:

// #define TFT_SDA_READ      // This option is for ESP32 ONLY, tested with ST7789 and GC9A01 display only

// For ST7735, ST7789 and ILI9341 ONLY, define the colour order IF the blue and red are swapped on your display
// Try ONE option at a time to find the correct colour order for your display

//  #define TFT_RGB_ORDER TFT_RGB  // Colour order Red-Green-Blue
  #define TFT_RGB_ORDER TFT_BGR  // Colour order Blue-Green-Red

// For M5Stack ESP32 module with integrated ILI9341 display ONLY, remove // in line below

// #define M5STACK

// For ST7789, ST7735, ILI9163 and GC9A01 ONLY, define the pixel width and height in portrait orientation
// #define TFT_WIDTH  80
// #define TFT_WIDTH  128
// #define TFT_WIDTH  172 // ST7789 172 x 320
// #define TFT_WIDTH  170 // ST7789 170 x 320
 #define TFT_WIDTH  240 // ST7789 240 x 240 and 240 x 320
// #define TFT_HEIGHT 160
// #define TFT_HEIGHT 128
// #define TFT_HEIGHT 240 // ST7789 240 x 240
 #define TFT_HEIGHT 320 // ST7789 240 x 320
// #define TFT_HEIGHT 240 // GC9A01 240 x 240

// For ST7735 ONLY, define the type of display, originally this was based on the
// colour of the tab on the screen protector film but this is not always true, so try
// out the different options below if the screen does not display graphics correctly,
// e.g. colours wrong, mirror images, or stray pixels at the edges.
// Comment out ALL BUT ONE of these options for a ST7735 display driver, save this
// this User_Setup file, then rebuild and upload the sketch to the board again:

// #define ST7735_INITB
// #define ST7735_GREENTAB
// #define ST7735_GREENTAB2
// #define ST7735_GREENTAB3
// #define ST7735_GREENTAB128    // For 128 x 128 display
// #define ST7735_GREENTAB160x80 // For 160 x 80 display (BGR, inverted, 26 offset)
// #define ST7735_ROBOTLCD       // For some RobotLCD Arduino shields (128x160, BGR, https://docs.arduino.cc/retired/getting-started-guides/TFT)
// #define ST7735_REDTAB
// #define ST7735_BLACKTAB
// #define ST7735_REDTAB160x80   // For 160 x 80 display with 24 pixel offset

// If colours are inverted (white shows as black) then uncomment one of the next
// 2 lines try both options, one of the options should correct the inversion.

// #define TFT_INVERSION_ON
// #define TFT_INVERSION_OFF


// ##################################################################################
//
// Section 2. Define the pins that are used to interface with the display here
//
// ##################################################################################

// If a backlight control signal is available then define the TFT_BL pin in Section 2
// below. The backlight will be turned ON when tft.begin() is called, but the library
// needs to know if the LEDs are ON with the pin HIGH or LOW. If the LEDs are to be
// driven with a PWM signal or turned OFF/ON then this must be handled by the user
// sketch. e.g. with digitalWrite(TFT_BL, LOW);

// #define TFT_BL   32            // LED back-light control pin
// #define TFT_BACKLIGHT_ON HIGH  // Level to turn ON back-light (HIGH or LOW)
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
